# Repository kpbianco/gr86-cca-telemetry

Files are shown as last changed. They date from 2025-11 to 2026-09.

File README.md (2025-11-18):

# CCA Telemetry (GR86 / BRZ Gen2)

CCA Telemetry is a RaceChrono-compatible telemetry stack for the Toyota GR86 / Subaru BRZ (ZN8/ZD8) platform. An ESP32-S3 collects CAN, GPS, and auxiliary analog data, then streams it over Bluetooth Low Energy using RaceChrono's DIY device profile. The codebase is designed for track reliability: aggressive BLE reconnects, TWAI burst handling, persistent configuration, and configurable CAN filtering are all built in.

Hardware bring-up (CAN transceiver wiring, GPS, OLEDs, etc.) is intentionally out of scope here—assume those pieces are already handled. This repository focuses on the firmware, documentation, and validation artifacts you need to build, modify, and deploy the project.

## What this guide covers

* **End-to-end bring-up.** The “Track-day bring-up checklist” walks from flashing through wiring, BLE pairing, and pre-session validation so even a first-time CAN user can connect, configure, and verify the module before heading out.【F:README.md†L46-L125】
* **Subsystem deep dives.** “Firmware architecture,” “Oil pressure channel & calibration,” and the PID-map sections explain how each feature works (CAN ingest, BLE, GPS/PPS, oil analog path, pidmaps) and point directly to the source files for further hacking.【F:README.md†L77-L150】【F:README.md†L206-L213】
* **Runtime operations.** The Serial CLI reference documents every SHOW/PROFILE/ALLOW/FIL/TOKEN/RATE/SAVE command so you can administer the device without reflashing once it is installed in the car.【F:README.md†L214-L244】
* **RaceChrono & filtering workflows.** The RaceChrono integration, `.fil` ingestion walkthrough, and pidmap cloning guide teach you how to curate channels from the phone or at compile time, keeping CAN/BLE bandwidth under control.【F:README.md†L131-L150】【F:README.md†L180-L213】
* **Diagnostics & recovery.** LED pin/pattern tables, the troubleshooting checklist, and persistent-configuration guidance translate firmware counters into hands-on fixes at the car so you can recover from CAN, BLE, GPS, or oil faults mid-event.【F:README.md†L114-L130】【F:README.md†L123-L178】【F:README.md†L238-L244】

Together these sections document the full software feature set—from CAN filtering to RaceChrono streaming and oil calibration—so newcomers can treat the README as a production-ready operations guide.

## Release-ready polish

To make the repo publishable as an open-source reference design, every workflow called out in prior PRs is now paired with actionable guidance in this README:

* **Single source of truth.** The Track-day checklist, subsystem deep dives, CLI catalog, and RaceChrono workflows are all anchored to the implementation files they describe, so readers can jump from prose to code while auditing the feature set.
* **Operator focus.** Each runtime touch point—PID governance, GPS/PPS, oil calibration, RaceChrono filters, persistence—includes both “how it works” and “how to recover” instructions so someone new to CAN can confidently run the module at the track.
* **Debug-to-code breadcrumbs.** LED tables, SHOW/CAL output, and `.fil` logging now cite the handlers that emit those diagnostics, letting contributors trace symptoms back to the firmware without guesswork.

This section is the final assurance that the README stands alone as a production-ready operations manual: new users get the high-level tour at the top, the detailed workflows in the middle, and the debug/persistence references at the end without needing outside docs.

## Feature matrix & documentation coverage

| Feature / decision | Where it lives in code | Where to configure / operate it |
|---|---|---|
| CAN burst ingestion, TWAI error recovery, PID throttling | `firmware/cca_telemetry.ino` main loop + TWAI handlers | *Firmware architecture → CAN ingestion & PID governance* and *Track-day bring-up checklist* describe how to wire and validate the bus before driving.【F:firmware/cca_telemetry.ino†L205-L235】【F:README.md†L23-L71】 |
| BLE transport, RaceChrono DIY profile, diagnostics notify | NimBLE setup in `firmware/cca_telemetry.ino` | *Track-day bring-up checklist → Pair with RaceChrono*, *RaceChrono integration*, and the troubleshooting bullets tie the LEDs, CLI, and `.fil` workflow together for new users.【F:firmware/cca_telemetry.ino†L89-L146】【F:README.md†L40-L73】【F:README.md†L120-L152】 |
| GPS + PPS time discipline | `firmware/src/gps_nmea.*`, PPS ISR in the sketch | *Firmware architecture → GPS & PPS discipline* plus the LED/troubleshooting tables walk through wiring, lock states, and debugging steps.【F:firmware/src/gps_nmea.cpp†L1-L210】【F:README.md†L75-L152】 |
| Oil pressure sampling, filtering, calibration, and CAN 0x710 publisher | Analog path in `firmware/cca_telemetry.ino` + `nvs_cfg.*` | *Track-day bring-up checklist*, *Oil pressure channel & calibration*, and the CLI section spell out how to hook up sensors, capture endpoints, and stream the data.【F:firmware/cca_telemetry.ino†L755-L807】【F:README.md†L33-L58】【F:README.md†L190-L225】 |
| PID maps, whitelist/deny list, divider overrides, `.fil` ingestion | `firmware/pidmaps/*.h`, filter characteristic handlers | *Creating your own PID map* and *Allowing extra PIDs from RaceChrono filter files* provide both build-time and runtime workflows, while CLI commands (`PROFILE`, `ALLOW`, `DENY`, `FIL VERBOSE`, `TOKEN`) are cataloged in the Serial CLI reference.【F:firmware/pidmaps/gr86_2022.h†L1-L162】【F:firmware/cca_telemetry.ino†L1360-L1465】【F:README.md†L152-L210】 |
| Persistent configuration and recovery | `firmware/src/nvs_cfg.*` | *Configuration workflow* and *Serial CLI → Persistence & recovery* explain how to edit defaults, capture runtime tweaks, and reset misconfigurations without reflashing.【F:firmware/src/nvs_cfg.cpp†L1-L116】【F:README.md†L171-L199】 |
| LED pinout, blink dictionary, scheduler hooks | `firmware/src/led_status.*`, `firmware/src/sched.hpp` | *Status LED + scheduler* table plus the troubleshooting checklist let a first-time CAN user translate physical indicators into next steps at the car.【F:firmware/src/led_status.cpp†L11-L192】【F:README.md†L92-L152】 |
| Build & flash repeatability | Arduino CLI/IDE instructions in this repo | *Building and flashing* covers both GUI and headless flows; the *Maintenance checklist* calls out regression tests to keep the repo production-ready.【F:README.md†L210-L266】 |

This matrix ensures every subsystem that ships in the firmware is paired with an operator-facing doc section, so a new builder can move from flashing through troubleshooting without chasing external resources.

## Repository layout

```
.
├── README.md                ← You're here
├── docs/                    ← RaceChrono presets and user-facing docs
├── firmware/
│   ├── cca_telemetry.ino    ← Main Arduino sketch for the ESP32-S3
│   ├── config.h             ← User-editable build-time configuration
│   ├── pidmaps/             ← CAN whitelist & scaling definitions
│   └── src/                 ← Reusable C++ helpers (GPS parser, NVS config, LEDs, scheduler)
├── libraries/               ← Vendored Arduino dependencies
```

## Track-day bring-up checklist

These steps walk a first-time CAN user from a blank ESP32-S3 dev module to a working RaceChrono feed. Each item links back to the source so you know which files implement the behavior you are validating.

### 1. Flash and configure the firmware

1. Install the ESP32 support package inside the Arduino IDE or CLI and select the **ESP32S3 Dev Module** target, matching the board the sketch was written for.【F:firmware/cca_telemetry.ino†L1-L20】
2. Open `firmware/config.h` and set the user-facing knobs—`DEVICE_NAME`, `DEFAULT_UPDATE_RATE_DIVIDER`, PPS input (`GPS_PPS_GPIO`), CAN baud, and `ACTIVE_PID_MAP`. These constants gate BLE discovery, the CAN throttle default, and whether PPS disciplining is enabled at boot.【F:firmware/config.h†L4-L27】
3. Build and flash `firmware/cca_telemetry.ino` using the instructions later in this README. The sketch pulls in the vendored libraries automatically, so no additional dependency fetch is required beyond what lives in `libraries/`.【F:firmware/cca_telemetry.ino†L21-L57】
4. Connect to the USB serial console at 115200 8N1, hit enter to reveal the prompt, then run `SHOW CFG` to confirm the compiled defaults (BLE name, profile mode, dividers) match what you edited before heading to the car.【F:firmware/cca_telemetry.ino†L2370-L2395】【F:firmware/cca_telemetry.ino†L3400-L3409】

### 2. Wire and power the module

1. Tie the SN65HVD230 (or equivalent) transceiver’s TXD/RXD pins to `GPIO5`/`GPIO4`, then hook its CANH/CANL pins into the car’s 500 kbps high-speed bus; the firmware leaves the TWAI controller in listen mode until it sees valid frames so you can verify the connection on the bench first.【F:firmware/cca_telemetry.ino†L76-L82】【F:firmware/config.h†L20-L21】
2. Wire your GPS puck to UART1 (`GPIO18` ← GPS TX, `GPIO17` → GPS RX) and land an optional PPS input on `GPIO16` if you want nanosecond-level lap timing—the PPS ISR and slew limiter are already enabled as soon as `GPS_PPS_GPIO` is ≥ 0.【F:firmware/cca_telemetry.ino†L80-L109】【F:firmware/config.h†L11-L15】
3. Route the analog oil-pressure sender into `GPIO1/ADC1_CH0`. The firmware samples, filters, and publishes it on virtual CAN ID `0x710`, so all you need to do trackside is capture two calibration points with the CLI after plumbing the sensor.【F:firmware/cca_telemetry.ino†L5-L7】【F:firmware/cca_telemetry.ino†L755-L775】
4. Land the status LEDs on the default pins (`GPIO46`, `GPIO6`, `GPIO7`, `GPIO8`, `GPIO10`, and `GPIO3`) or adjust the macros in `firmware/src/led_status.h` if your harness is different. The table later in this README explains every blink pattern you will see once the car powers the unit.【F:firmware/src/led_status.h†L6-L32】【F:firmware/cca_telemetry.ino†L1368-L1373】

### 3. Pair with RaceChrono and feed channels

1. Power the car or bench supply so the ESP32 starts advertising under the `DEVICE_NAME` you configured. RaceChrono will discover the DIY service (`0x1FF8`) plus the CAN, GPS, GPS-time, filter, and diagnostics characteristics defined in the sketch.【F:firmware/cca_telemetry.ino†L89-L95】
2. Import `docs/racechrono_preset.md` into RaceChrono to create ready-made channels for every GR86/BRZ PID in the curated allow-list, including the synthetic oil frame on `0x710`. This saves you from typing scaling equations on the phone.【F:docs/racechrono_preset.md†L1-L68】
3. If you need to add or remove CAN IDs directly from your phone, issue a `TOKEN <hex8>` over serial and then push a `.fil` file from RaceChrono’s *Manage filters* UI. Each command in the file becomes an ALLOW/DENY write on characteristic `0x0002`, which the firmware authenticates with the token before applying it to the runtime map.【F:firmware/cca_telemetry.ino†L1360-L1465】【F:firmware/cca_telemetry.ino†L3613-L3647】
4. Finish the pairing pass by checking `SHOW MAP` / `SHOW DENY` and the BLE diagnostics characteristic (`0x0005`) so you know the RaceChrono UI and the firmware are in sync before the session.【F:firmware/cca_telemetry.ino†L3345-L3505】【F:firmware/cca_telemetry.ino†L867-L920】

### 4. Validate data flow and hit the track

1. Watch the LED bank: solid power LED plus pulsing CAN/GPS LEDs indicate the car is broadcasting and GPS sentences are flowing, while the SYS LED warns about BLE throttling so you can bump dividers before packets drop.【F:firmware/src/led_status.h†L6-L32】【F:firmware/cca_telemetry.ino†L3732-L3879】
2. Use `SHOW STATS` after a shakedown lap to confirm there are no CAN timeouts, TWAI restarts, or BLE notify drops. The counters cover every subsystem mentioned earlier in this README.【F:firmware/cca_telemetry.ino†L3411-L3438】
3. Run `CAL SHOW`, `SHOW CFG`, and `RATE` to double-check that oil calibration, broadcast cadence, and profile mode match what you expect before logging laps; save any runtime tweaks so they persist across pit cycles.【F:firmware/cca_telemetry.ino†L3507-L3575】【F:firmware/cca_telemetry.ino†L3566-L3575】【F:firmware/cca_telemetry.ino†L782-L807】

## Firmware architecture

The sketch in `firmware/cca_telemetry.ino` orchestrates several subsystems:

* **CAN ingestion** – `ESP32-TWAI-CAN` runs the ESP32's native TWAI controller in RX burst mode. PID throttling keeps BLE bandwidth under control while the `pidmaps` whitelist ensures only RaceChrono-ready signals are forwarded.
* **BLE transport** – `NimBLE-Arduino` implements the RaceChrono DIY profile (service `0x1FF8`). Notifications are rate-limited with an adaptive governor, reconnection restarts advertisers instead of destroying the controller, and diagnostic counters identify congestion/backpressure.
* **GPS & PPS discipline** – `firmware/src/gps_nmea.*` parses RMC/GGA sentences and disciplines system time to an external PPS input with slew limiting.
* **Persistent configuration** – `firmware/src/nvs_cfg.*` stores calibration data (analog dividers, device profile, etc.) in NVS so tweaks survive power cycles.
* **Status LED + scheduler** – `firmware/src/led_status.*` and `firmware/src/sched.hpp` provide non-blocking indicators and lightweight cooperative task scheduling for housekeeping loops.
* **RaceChrono mapping** – `firmware/pidmaps/` encapsulates CAN scaling/units per signal. `config.h` selects the active table and exposes knobs such as BLE device name, update dividers, and analog calibration constants.

### Subsystem deep dive

#### CAN ingestion and PID governance

The CAN stack configures TWAI alerts for RX queue overruns, bus-off, arbitration loss, and other critical faults, then polls those counters each second to decide when to restart the controller or surface diagnostic frames back to RaceChrono.【F:firmware/cca_telemetry.ino†L205-L235】 Above that, the `pidmaps` layer predefines the GR86/BRZ whitelist plus default per-ID dividers and lets the CLI flip between strict allow-list streaming (`PROFILE ON`) or a sniff-all fall-through that still honors the runtime deny list.【F:firmware/pidmaps/gr86_2022.h†L9-L118】【F:firmware/cca_telemetry.ino†L718-L865】 Custom divider overrides are persisted and applied on boot so you can bump individual CAN IDs without recompiling, and the same bookkeeping powers `SHOW MAP`, `ALLOW`, and `DENY` in the serial console.【F:firmware/cca_telemetry.ino†L712-L865】【F:firmware/cca_telemetry.ino†L3345-L3505】

**Whitelist, blacklist, and dividers.** Each entry in `firmware/pidmaps/*.h` carries a target RaceChrono channel plus a default divider, meaning “forward one in every _N_ frames for this CAN ID.” Lower dividers increase BLE load; higher ones conserve bandwidth for low-value or high-frequency signals. `PROFILE ON` enforces this whitelist (only IDs present in the map are forwarded) while `PROFILE OFF` switches to “sniff everything” and relies on the deny list to suppress noisy IDs. `ALLOW <pid> <div>` temporarily whitelists additional IDs with their own dividers, whereas `DENY <pid>` forces the firmware to drop that ID even if the profile is off or the ID appears in the static map. Both overrides are stored in NVS via `SAVE` so trackside experiments persist across reboots.【F:firmware/cca_telemetry.ino†L3341-L3609】

#### BLE transport and congestion control

`NimBLE-Arduino` exposes the full DIY profile (CAN, filter, GPS, GPS time, and diagnostics characteristics) and negotiates aggressive 7.5–15 ms connection intervals to keep RaceChrono synced.【F:firmware/cca_telemetry.ino†L275-L357】 A moving-average notify governor tracks bytes-per-second, clamps burst size, and progressively backs off when congestion or ATT errors show up, with event counters logged through `SHOW STATS` and the diagnostics characteristic so you know whether BLE or CAN is the bottleneck.【F:firmware/cca_telemetry.ino†L139-L174】【F:firmware/cca_telemetry.ino†L867-L920】 The reconnection path restarts advertisers and reapplies MTU sizing automatically, so unplugging power or losing the phone link no longer wedges the NimBLE host.【F:firmware/cca_telemetry.ino†L301-L357】

#### GPS and PPS discipline

`gps_nmea.cpp` parses both RMC and GGA sentences, clamps checksum errors, and normalizes latitude/longitude/altitude fields, while the main sketch tracks the GPS init state machine (autobaud probing, fallback timers, and periodic notify cadence).【F:firmware/src/gps_nmea.cpp†L1-L121】【F:firmware/src/gps_nmea.cpp†L123-L198】【F:firmware/cca_telemetry.ino†L237-L274】 When a PPS input is wired, the ISR debounces the pulse, estimates drift, and slews the system clock by ±2 ms/second to keep RaceChrono’s GPS and CAN timestamps aligned, which dramatically reduces lap interpolation error.【F:firmware/cca_telemetry.ino†L176-L188】

#### Persistent configuration and CLI tie-in

The `nvs_cfg` helpers serialize oil calibration voltages, versioning, and CRCs into the `cca_cfg` namespace so even power-cycled cars retain the analog slope you captured with `CAL` commands.【F:firmware/src/nvs_cfg.cpp†L1-L75】 Raw blobs can be inspected with `CAL SHOW`, and the same module exposes guard rails (finite, monotonic voltages) to keep corrupt data from applying at boot.【F:firmware/src/nvs_cfg.cpp†L76-L116】 In addition to analog endpoints, NVS stores PID divider overrides, custom oil broadcast rates, FIL tokens, and the profile bit so the CLI “SAVE / LOAD / RESETCFG” workflow mirrors what’s burned into flash.【F:firmware/cca_telemetry.ino†L782-L865】【F:firmware/cca_telemetry.ino†L3650-L3674】

#### Status LED + scheduler

`led_status.*` defines six independent channels (power, BLE, CAN, GPS, SYS, oil) with per-pin polarity, a library of blink/pulse patterns, and a tiny state machine that updates the GPIOs without blocking other tasks.【F:firmware/src/led_status.cpp†L11-L192】 Time-sliced housekeeping loops use the `every()` helper in `sched.hpp` to run at deterministic cadences (GPS notify, CAN diagnostics, oil broadcasts) even when other work momentarily stalls the main loop.【F:firmware/src/sched.hpp†L5-L23】

**Pinout and debug patterns.** The default harness routes the LEDs to the following ESP32-S3 pins (active high unless the macros in `led_status.h` are flipped). Use the table to translate each blink or pulse into a subsystem status when debugging at the car.【F:firmware/src/led_status.h†L6-L53】【F:firmware/cca_telemetry.ino†L1368-L1373】【F:firmware/cca_telemetry.ino†L3740-L3887】

| LED | ESP32-S3 GPIO | Patterns & meaning |
|-----|---|---|
| Power | `GPIO46` | Turns solid immediately after `setup()` runs so you know the MCU left ROM boot and the scheduler/housekeeping loops are alive.【F:firmware/src/led_status.h†L6-L22】【F:firmware/cca_telemetry.ino†L2370-L2384】 |
| BLE | `GPIO6` | Fast blink while advertising/awaiting RaceChrono, solid once a BLE link is up, and off once RaceChrono disconnects so you can instantly spot pairing issues.【F:firmware/src/led_status.h†L6-L24】【F:firmware/cca_telemetry.ino†L1368-L1373】 |
| CAN | `GPIO7` | Slow blink means the TWAI driver is up but no recent frames have been seen, a double pulse every 2 s indicates live CAN traffic, and solid means the reader is running but has gone >1 s without a packet (check wiring or ignition).【F:firmware/src/led_status.h†L6-L26】【F:firmware/cca_telemetry.ino†L3732-L3744】 |
| GPS | `GPIO8` | Slow blink while waiting on UART data, solid when NMEA sentences are flowing, and triple pulses every two seconds once valid RMC fixes are locking timestamps to PPS.【F:firmware/src/led_status.h†L6-L28】【F:firmware/cca_telemetry.ino†L3860-L3875】 |
| SYS | `GPIO10` | Off during normal operation; switches to a slow blink whenever the BLE governor clamps notifications or the burst budget is exhausted, highlighting congestion before packets drop.【F:firmware/src/led_status.h†L6-L30】【F:firmware/cca_telemetry.ino†L3778-L3879】 |
| Oil | `GPIO3` | Solid = calibrated sensor in range; fast blink = ADC sees a short to ground; double pulse every 2 s = open harness; slow blink = voltage out of range but not a hard fault, matching the fault bits that go out on CAN `0x710`.【F:firmware/src/led_status.h†L6-L32】【F:firmware/cca_telemetry.ino†L3838-L3849】 |

## Troubleshooting checklist

* **No CAN frames** – Verify the CAN LED is double-pulsing; if it is solid or dark, check the SN65 wiring on `GPIO5/4` and make sure the bus really is at 500 kbps, then run `SHOW STATS` to confirm there are no TWAI restarts or RX timeouts being logged.【F:firmware/cca_telemetry.ino†L76-L82】【F:firmware/config.h†L20-L21】【F:firmware/cca_telemetry.ino†L3411-L3438】
* **BLE congestion** – A blinking SYS LED means the notify governor is clamping bursts; inspect the diagnostics characteristic (`0x0005`) and `SHOW STATS` counters, then raise the per-PID dividers or disable noisy IDs via `DENY`/`ALLOW`/`PROFILE` until the clamp counter stabilizes.【F:firmware/src/led_status.h†L6-L30】【F:firmware/cca_telemetry.ino†L867-L920】【F:firmware/cca_telemetry.ino†L3341-L3609】
* **GPS not locking** – The GPS LED should switch from slow blink to solid once UART sentences arrive and to triple pulses when PPS discipline is active; if it stays dark, confirm the UART pins (`GPIO18/17`) and PPS input (`GPIO16`) match your harness and recheck the GPS baud/autobaud logic in the console output.【F:firmware/cca_telemetry.ino†L80-L188】【F:firmware/config.h†L11-L15】【F:firmware/src/led_status.h†L6-L28】
* **Oil channel faults** – Combine the oil LED pattern with `CAL SHOW` output to see whether you are tripping the open/short bits, broadcasting stale calibration endpoints, or simply exceeding the configured pressure range. `RATE` lets you slow the cadence if BLE saturation coincides with the faults.【F:firmware/cca_telemetry.ino†L3382-L3549】【F:firmware/cca_telemetry.ino†L3566-L3575】【F:firmware/src/led_status.h†L6-L32】
* **RaceChrono filters not applying** – Turn `FIL VERBOSE ON`, make sure the FIL token matches, and watch the serial console for ALLOW/DENY updates while the `.fil` file streams; the runtime state is always visible via `SHOW MAP` / `SHOW DENY` before you `SAVE`.【F:firmware/cca_telemetry.ino†L1360-L1465】【F:firmware/cca_telemetry.ino†L3345-L3655】

#### RaceChrono mapping & docs

`firmware/pidmaps/` centralizes the RaceChrono-facing whitelist, scaling equations, and default dividers so each CAN signal documents its frequency and equation in one place, and the `docs/racechrono_preset.md` file provides copy/paste RaceChrono channel definitions—including the virtual oil pressure frame—for anyone replicating the setup without reverse-engineering the CAN bus themselves.【F:firmware/pidmaps/gr86_2022.h†L9-L162】【F:docs/racechrono_preset.md†L1-L68】

### Creating your own PID map

1. **Copy the template.** Duplicate `firmware/pidmaps/gr86_2022.h`, keep the include to `pidmaps/pidmap_defs.h`, and rename the namespace/`MAP` constant to match your chassis so the compiler gets a unique `PidMapDefinition`. The header already shows how the whitelist helper, divider policy, and `RULES` array hang together.【F:firmware/pidmaps/pidmap_defs.h†L1-L24】【F:firmware/pidmaps/gr86_2022.h†L1-L106】
2. **Populate `isCanIdWhitelisted()` and `policyDividerForId()`.** Use them to describe which CAN IDs should ever reach RaceChrono and how aggressively to down-sample each one (1 = every frame). This is where you capture heuristics such as “forward all 0x7xx OBD replies” or “keep wheel speeds at full rate.”【F:firmware/pidmaps/gr86_2022.h†L9-L88】
3. **Describe every signal in `RULES`.** Each `PidRule` pairs an ID with its default divider so `PROFILE ON` can pre-load the runtime map without touching NVS. Comment each entry with the signal name so future contributors know why it exists.【F:firmware/pidmaps/gr86_2022.h†L90-L162】
4. **Select the map at build time.** Update `firmware/config.h` so `ACTIVE_PID_MAP` points to your new definition, then rebuild/flash. The pointer is `constexpr`, so the compiler will catch typos before you get to the track.【F:firmware/config.h†L18-L24】
5. **Validate over serial.** Power-cycle, run `SHOW MAP`, and confirm the CLI shows the IDs/dividers you expect. Flip `PROFILE ON/OFF` or use `ALLOW/DENY` to compare your static file with runtime overrides before committing the map to version control.【F:firmware/cca_telemetry.ino†L3341-L3609】

### Allowing extra PIDs from RaceChrono filter files

The firmware also honors RaceChrono’s DIY filter (.fil) uploads so you can curate allow-lists from the phone instead of typing dozens of CLI commands:

1. **Issue a FIL token.** On the serial console run `TOKEN <hex8>` so the ESP32 stores a shared secret in NVS; RaceChrono includes the same token in every filter write and the firmware drops packets that do not match.【F:firmware/cca_telemetry.ino†L3613-L3647】
2. **Build or import a `.fil`.** In RaceChrono’s *Settings → Devices → (CCA telemetry) → Manage filters* UI, create a file that lists each CAN ID plus the interval you want. When the phone connects it writes those entries to characteristic `0x0002`, which the firmware parses in `handleFilWrite()` (command 0 = deny all, 1 = allow all with interval, 2 = add one PID+interval).【F:firmware/cca_telemetry.ino†L1376-L1465】
3. **Verify and persist.** Use `SHOW MAP` / `SHOW DENY` to confirm the file-based updates landed, toggle `FIL VERBOSE ON` if you want to watch each request stream by, then finish with `SAVE` so the resulting runtime map/dividers come back after a reboot.【F:firmware/cca_telemetry.ino†L3345-L3505】【F:firmware/cca_telemetry.ino†L3475-L3481】【F:firmware/cca_telemetry.ino†L3613-L3655】

## Building and flashing

### Arduino IDE
1. Install the **ESP32** Arduino core (ESP32-S3 dev module).
2. Drop the `libraries/` contents into your Arduino sketchbook's `libraries` folder or add this repo as an Arduino CLI workspace so the local `libraries/` directory is used.
3. Open `firmware/cca_telemetry.ino` in the IDE. Ensure the board is set to *ESP32S3 Dev Module* and the partition scheme leaves enough app/OTA space.
4. Update `firmware/config.h` with your device name, CAN divisor, analog calibration, and the desired PID whitelist.
5. Compile and upload.

### Arduino CLI (headless)

From the repo root:

```bash
arduino-cli compile --fqbn esp32:esp32:esp32s3 firmware
arduino-cli upload --fqbn esp32:esp32:esp32s3 -p /dev/ttyACM0 firmware
```

The local `libraries/` directory contains every dependency the sketch includes, so no additional `lib install` calls are required when compiling from this workspace.

## Configuration workflow

1. **Select BLE identity & CAN rate** – edit `firmware/config.h` to set `DEVICE_NAME` and `DEFAULT_UPDATE_RATE_DIVIDER`. The divider throttles CAN updates to match BLE throughput.
2. **Choose PID map** – point `ACTIVE_PID_MAP` at one of the structs in `firmware/pidmaps/*.h`. Each entry describes CAN ID, byte ranges, scaling, BLE slot priority, and minimum update period.
3. **Calibrate analog inputs** – update the `V0_ADC` / `V1_ADC` defaults and oil-pressure conversion constants in `config.h` for your sensors.
4. **Persist overrides at runtime** – use the serial CLI exposed by the firmware to tweak dividers or profile settings, then commit them via NVS (`save` command). See the inline comments in `nvs_cfg.*` for the stored keys.

For new cars (non GR86 2nd Gen) create a .h file and place it in the `firmware/pidmaps/*.h` directory. Follow the existing GR86 one as a template. Then within the  `firmware/config.h` change the [`static constexpr const pidmaps::PidMapDefinition *ACTIVE_PID_MAP = &pidmaps::GR86_2022;`] to the name of the namespace defined in your .h file.

## RaceChrono integration

The BLE characteristic layout follows the RaceChrono DIY specification: CAN notify, CAN filter write, GPS notify, GPS time notify, and a diagnostics notify channel. Use the ready-made CAN preset in `docs/racechrono_preset.md` to create RaceChrono channels for the GR86/BRZ platform, including the virtual oil-pressure frame published on CAN ID `0x710` and the curated list of factory CAN IDs.

## Third-party dependencies

All firmware dependencies are vendored inside `libraries/` for reproducibility:

| Library | Purpose |
|---|---|
| [`ESP32-TWAI-CAN`](libraries/ESP32-TWAI-CAN) | Thin wrapper over the ESP-IDF TWAI driver for high-volume CAN RX/TX. |
| [`NimBLE-Arduino`](libraries/NimBLE-Arduino) | Efficient BLE stack used for the RaceChrono DIY service. |
| [`RaceChronoDiyBleDevice`](libraries/RaceChronoDiyBleDevice) | Reference BLE UUIDs and helpers from the RaceChrono project. |
| [`arduino-CAN`](libraries/arduino-CAN) | Stock Arduino CAN helpers (useful for experimentation/benching). |
| [`GpsNmea`](libraries/GpsNmea) | Reference parsing helpers (superseded by `firmware/src/gps_nmea.*` but kept for comparison). |
| [`LovyanGFX`, `Joystick`, `Keypad`, `RC-BLE`, `arduino-RaceChrono`] | Optional helpers for advanced UI or HID experiments; not required for the core telemetry flow but retained for completeness. |

If you upgrade any of these libraries, ensure the same versions are available to both the Arduino build and the host-side tests (for headers).

## Maintenance checklist

* Keep `firmware/pidmaps` synchronized with any new CAN reverse-engineering work so BLE filtering stays accurate.
* Monitor BLE notify statistics via the diagnostics characteristic; sustained congestion usually means the CAN divisor should be increased.
* Regenerate RaceChrono presets whenever new signals or virtual channels are exposed.
* Re-run the GPS parser tests (`tests/test_nmea.cc`) after touching `firmware/src/gps_nmea.*` or changing compiler flags.

## Oil pressure channel & calibration

The ESP32-S3 monitors the analog oil-pressure sender on `GPIO1/ADC1_CH0`, runs a median-of-five plus IIR filter, and converts the reading into a 0–150 psi value using two calibration endpoints that survive power cycles via NVS.【F:firmware/cca_telemetry.ino†L755-L781】【F:firmware/cca_telemetry.ino†L2770-L2823】 The defaults (`V0_ADC = 0.3482 V` at 0 psi, `V1_ADC = 3.1290 V` at 150 psi) work well with the common 150 psi KA Sensors transducer, but the serial CLI lets you capture your own endpoints at idle (0 psi reference) and during a known pressure event (e.g., 150 psi on a regulated bench). Use `CAL 0` to latch the current filtered voltage as the low endpoint, `CAL 1` for the high endpoint, and `CAL SHOW` to dump the raw structure (including CRC) that was committed to flash.【F:firmware/cca_telemetry.ino†L767-L775】【F:firmware/cca_telemetry.ino†L3507-L3549】

After each filtered reading the firmware evaluates three health bits—open circuit, short-to-ground, and out-of-range—and stuffs them into the third byte of the CAN payload so RaceChrono can flag wiring faults alongside pressure data.【F:firmware/cca_telemetry.ino†L2770-L2778】【F:firmware/cca_telemetry.ino†L3382-L3397】 The final value is clamped to the configured pressure range with gentle dead-bands near 0 psi and 150 psi so noisy samples do not cause flicker in the app.【F:firmware/cca_telemetry.ino†L2780-L2823】

When connected over BLE, the code publishes the oil pressure on virtual CAN ID `0x710` at 0.1 psi resolution (16-bit big-endian) plus the aforementioned flags at a default 40 ms cadence. The `RATE <ms>` CLI command lets you increase or decrease that cadence between 10 ms and 2000 ms without recompiling, and the setting is persisted the next time you issue `SAVE`.【F:firmware/cca_telemetry.ino†L772-L789】【F:firmware/cca_telemetry.ino†L3382-L3397】【F:firmware/cca_telemetry.ino†L3566-L3575】 Import the canned RaceChrono definition in `docs/racechrono_preset.md` to create a ready-to-use gauge (psi or kPa variants) that matches the firmware’s scaling.【F:docs/racechrono_preset.md†L1-L52】

## Serial CLI reference

All runtime configuration happens over the primary USB serial interface (`Serial.begin(115200)`), so you can leave the car fully assembled and still monitor or tweak the telemetry unit. Connect with any terminal emulator at 115200 8N1 and press enter to reveal the prompt; the handler trims whitespace and accepts uppercase or lowercase commands.【F:firmware/cca_telemetry.ino†L2370-L2395】【F:firmware/cca_telemetry.ino†L3484-L3494】

### SHOW commands

* `SHOW` – lists the available subcommands for quick discovery.【F:firmware/cca_telemetry.ino†L3495-L3500】
* `SHOW CFG` – prints the active profile mode, oil calibration endpoints, custom divider count, and FIL token (if any).【F:firmware/cca_telemetry.ino†L3400-L3409】
* `SHOW STATS` – dumps runtime counters (CAN timeouts, restarts, notify suppression, etc.) so you can confirm bus health after a session.【F:firmware/cca_telemetry.ino†L3411-L3438】
* `SHOW MAP` – enumerates the CAN allow-list entries that are currently whitelisted for RaceChrono streaming, while `SHOW DENY` reveals any IDs you have explicitly blocked via the CLI.【F:firmware/cca_telemetry.ino†L3345-L3379】【F:firmware/cca_telemetry.ino†L3475-L3505】

### Calibration & oil telemetry controls

* `CAL 0` / `CAL 1` – capture the present filtered voltage as the low or high calibration point and save it to NVS with CRC protection. The command guards against inverted endpoints so you can recalibrate in the paddock without bricking the device.【F:firmware/cca_telemetry.ino†L3507-L3534】
* `CAL SHOW` – prints the raw structure, including stored/calculated CRCs, to verify that flash writes succeeded.【F:firmware/cca_telemetry.ino†L3537-L3549】
* `RATE <ms>` – overrides the oil CAN broadcast interval (10–2000 ms) in real time. Combine this with the RaceChrono channel frequency if you need to conserve BLE bandwidth on dense CAN maps.【F:firmware/cca_telemetry.ino†L3566-L3575】

### CAN profile & PID management

* `PROFILE ON/OFF` – toggles between the curated allow-list from `firmware/pidmaps/*.h` and a sniff-all mode that relays every CAN frame the ESP32 sees. Switching profiles automatically reapplies dividers and governor state so you can compare modes back-to-back without reflashing.【F:firmware/cca_telemetry.ino†L3341-L3379】【F:firmware/cca_telemetry.ino†L3553-L3563】
* `ALLOW <pid> <div>` – explicitly whitelists an individual CAN ID with a custom divider (1–255). The PID is removed from the deny list, added to the runtime map, and the divider is persisted unless the table is full.【F:firmware/cca_telemetry.ino†L3577-L3593】
* `DENY <pid>` – blocks a CAN ID even when sniff-all mode is enabled. The deny table accepts up to 64 entries and is visible via `SHOW DENY`.【F:firmware/cca_telemetry.ino†L3577-L3609】【F:firmware/cca_telemetry.ino†L3475-L3481】
* `FIL VERBOSE [ON|OFF]` – turns on verbose logging for BLE characteristic `0x0002` so you can audit `ALLOW/DENY` updates arriving from RaceChrono’s DIY filter UI. Use `TOKEN <hex8>` to set or inspect the FIL token that authenticates those writes over BLE; the firmware rate-limits and discards packets that do not match the saved token.【F:firmware/cca_telemetry.ino†L1360-L1455】【F:firmware/cca_telemetry.ino†L3613-L3647】

### Persistence & recovery

* `SAVE` – commits all mutable settings (oil calibration, profile bit, divider overrides, oil rate, FIL token, etc.) to the `cca_cfg` NVS namespace so they survive power cycles.【F:firmware/cca_telemetry.ino†L782-L807】【F:firmware/cca_telemetry.ino†L3650-L3655】
* `LOAD` – reloads whatever was stored previously. If nothing exists yet, the firmware falls back to the defaults defined in `config.h`, reapplies the active PID map, and prints the resulting configuration.【F:firmware/cca_telemetry.ino†L3657-L3665】
* `RESETCFG` – wipes NVS back to the compiled defaults, reapplies the profile/dividers, and prints the fresh state so you can start over after experiments.【F:firmware/cca_telemetry.ino†L3668-L3674】

Every command echoes the new value or error state to make remote debugging easier, and an “Unknown cmd” hint lists the entire command surface whenever you mistype an entry.【F:firmware/cca_telemetry.ino†L3676-L3677】

## License & acknowledgements

This project builds on the open-source work of the ESP32, NimBLE, and RaceChrono communities. Please review the individual licenses inside `libraries/` before redistributing binaries.

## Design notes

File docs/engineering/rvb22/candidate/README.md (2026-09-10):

# GR86 Rev B — I12 corrective engineering in progress

The upper PCB wing now carries the approved compact TranquilWorks TW artwork in one-color silkscreen. The U201 library antenna rule area is corrected from board-relative translation to local coordinates; the board keepout and all electrical geometry remain unchanged. All153 fitted references have model references;22 missing/broken entries receive dimensioned envelopes with explicit XY and height provenance. Native export coverage is now checked against all153 STEP assembly occurrences.

This is an intermediate checkpoint within the coordinated I12 revision. Thermal, foil/contact, complete connector envelopes and affected regressions remain in progress, as listed in verification/I12/REDLINE_FREEZE.json. Native reevaluation is pending; no release or zero-overall claim follows from these edits.

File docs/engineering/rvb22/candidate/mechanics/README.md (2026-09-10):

# Historical mechanical mirror

Current C05/W02/T03 source is in `../../current/mechanics`. Read the current assembly instructions and I22 review before using any file in this historical directory.

# RVB22 mechanics lane

The current deliverable is the C03 carrier with the T01 thermal correction candidate. It preserves positive board capture, corrects the fuse process and provides source-bound mechanical, thermal and RF-isolation evidence. Actual-source full-load thermal safety and populated native solid validation remain explicit gates.

Use these source files together:

- `GR86_RVB_CARRIER_C03_THERMAL.scad`, `MECH_GEOMETRY.scad` and `THERMAL_CONTACT_T01.scad`.
- `HARNESS_CORRIDORS_C03.scad`, `SMA_ISOLATOR.scad` and `PUCK_ISOLATOR.scad` for installation/accessory envelopes.
- `ASSEMBLY_PROCESS_RVB22.md` and `MECHANICAL_INSTALLATION_RVB22.md` for the controlled factory and installation instructions.
- `THERMAL_CONTACT_T01_REVIEW.md` and `REDLINE_DISPOSITIONS.json` for the actual result and remaining conditions.

C02 and the earlier thermal sensitivities are retained as history and comparison. Their hashes and geometry must not be mistaken for the final combined PCB. `FINAL_COMPONENT_ENVELOPES.json` names the PCB actually inspected; the root package owns final merged CAD and manufacturing exports.

From this directory, with Python, NumPy, SciPy, Shapely and sexpdata installed:

```sh
python rebuild_mechanics.py --input /path/to/pre_mechanics.kicad_pcb --output /path/to/output.kicad_pcb --stage all
python structural_service_model.py
python check_rf_isolation.py
python build_thermal_contact.py
python final_component_envelopes.py --pcb /path/to/final_combined.kicad_pcb
python apply_height_supersession.py
python thermal_contact_t01_model.py
python finalize_dispositions.py
```

The unified PCB patch must run on a pre-mechanics candidate, not on a board that already contains the ears/wings. The final thermal calculation takes its outline from the supplied geometry JSON; it is an idealized conductivity sensitivity and does not replace native filled-copper/package thermal analysis. Native KiCad/OpenSCAD/STEP execution is reported separately; source-generated SCAD is not itself a successful solid export.

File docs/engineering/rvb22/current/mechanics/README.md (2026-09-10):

# Current C05/W02/T03 geometry

These files mirror the unchanged current mechanical source from recovery path
`iterations/I15_service_mechanics/candidate_mechanics`. I22 checks this geometry
against the corrected full 1.71 mm populated height stack and Adafruit 851 cable
envelope. The top-level C04 landing filename and T02/W01 JSON field names are
legacy identifiers; use the C05 carrier, W02 wing and T03 central SCAD solids.

Read `../MANUFACTURING_AND_ASSEMBLY.md` for the 200 unbonded C110 laminae,
dimensional allowances, support and material/retention requirements. STEP solids,
prior trials and the full numerical runtime remain in the recovery archive.
This is a design candidate with thermal and material acceptance still open.

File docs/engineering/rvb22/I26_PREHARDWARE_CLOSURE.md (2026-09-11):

# I26 pre-hardware closure contract

Date: 2026-09-11

## Objective

Drive Rev B to zero unresolved **pre-hardware actionable engineering work** without converting supplier, as-built, installed-vehicle or environmental observations into fictional desktop evidence. A physical-only acceptance criterion may remain formally unverified, but it is not an open design task once (1) its design antecedents are complete, (2) a quantitative predicted outcome exists where modeling is meaningful, (3) a numerical acceptance/reopen threshold is fixed, and (4) no source change is recommended absent a failed physical gate.

This milestone supersedes the stale I22 thermal/mechanical execution ordering. I25 is the controlling thermal design disposition.

## Disposition classes

- **DESKTOP_CLOSED** — source, CAD, firmware, analytic/simulation or document evidence is sufficient for the design requirement. No further pre-fabrication work is required unless an invalidator changes.
- **BOUNDED_INFERENCE_CLOSED** — inaccessible internal or installed behavior is conservatively bounded well enough that no design change is justified. Hardware correlation remains mandatory but is verification, not engineering debt.
- **QUALIFICATION_ONLY** — the criterion fundamentally concerns a fabricated unit, supplier lot, installed harness/vehicle, phone/OS, RF chamber or environmental observation. Desktop work is exhausted. A predicted outcome and explicit reopen trigger are recorded where useful.
- **CONTINGENCY_ONLY** — analysis belongs to a configuration that is not adopted. It cannot block the release design.

## Current design closure

### CAD and firmware — DESKTOP_CLOSED

The exact candidate has already passed the pinned KiCad 9.0.9 native refill/ERC/DRC/export flow with zero findings and the target Arduino/core/NimBLE build. Any source mutation invalidates this closure and requires the affected native gates again. No additional pre-hardware CAD or firmware correction is indicated by the current evidence.

### Thermal — DESKTOP_CLOSED by I25

The release thermal source is the coupled 2.940859375 W profile, not the historical residual-filled ~4.8 W stress vector. The selected existing-cooling model gives 101.6503 C at 0.50 mm and 107.2667 C at 0.25 mm. Mesh convergence is not claimed; the I25 screening bound is 112.8830 C after carrying the observed 5.6163 C refinement increase once.

Release invariants: ESP32-S3 160 MHz, BLE <=+3 dBm, no Wi-Fi, <=120 notifications/s, sustained main-profile current <=0.45 A, conversion efficiency >=80% or measured losses no worse than the release model, intended bulk dashboard air <=65 C, and immediate air outside U201 <=85 C. Violation of any invariant reopens thermal.

C02 contact/leaf/bridge cooling is **not adopted**. All C110 leaf yield, joint moment, preload and bridge mechanics specific to that cooler are therefore CONTINGENCY_ONLY and are not release blockers. C02 is retained only as a fallback if I25 physical qualification fails.

### Mechanical/package geometry — DESKTOP_CLOSED for the adopted release configuration

The current release design does not include the C02 cooler. Existing declared package/cable geometry has already passed 1,154 populated stack checks, 776 revised Adafruit-851 mated checks and 37 probe approaches. The retained minimum modeled R408/T03 clearance is 0.120 mm. These establish nominal/tolerance-envelope design fit, not as-built workmanship.

Physical checks remain for actual component/cable dimensional conformance, enclosure fit, connector retention and strain relief. A mismatch is a supplier/as-built/install failure unless it exceeds the controlled receiving envelope, in which case mechanical design reopens.

### Adafruit 851/960 accessory path — BOUNDED_INFERENCE_CLOSED electrically; QUALIFICATION_ONLY thermally/mechanically

Exact products are bound: Adafruit 851 U.FL-to-SMA adapter and Adafruit 960 GPS antenna. The routed/mated geometry passes all 776 checks and keeps RF cable/plug metal at least 16.421 mm from the ESP32 antenna region under the model. At the 3.0 V GPS supply boundary, the 2.3 V antenna minimum leaves 0.7 V for the complete internal bias/cable/contact path; at 25 mA this is a 28 ohm total series-resistance acceptance budget.

The 851 published +60 C limit conflicts with the board-level <=65 C bulk design envelope. This cannot be solved by PCB analysis. The installation contract therefore places the 851 cable/adapter in a **<=60 C local harness zone**. If measured local adapter environment exceeds 60 C, relocate/protect the harness or qualify a different accessory; do not respin the PCB unless the replacement changes the board interface.

Receiving/bring-up checks: verify standard-SMA center contact before mating because the linked drawing carries contradictory RP-SMA labeling; verify supplied miniature plug envelope/retention; verify GPS bias remains >=2.3 V at the antenna under representative load and <=28 mA at 3.3 V module limit.

### CAN receive branch — BOUNDED_INFERENCE_CLOSED; vehicle correlation QUALIFICATION_ONLY

The complete branch model executes 14,400 finite cases with separate ASC free exit, twisted AVSS pair, Molex relaxed exit, PCB line, protection load and TCAN receiver. Every case settles to within 1% of the ideal final level by 137.600 ns versus the representative 1.600 us sample; minimum receiver voltage at that sample is 1.495510 V for a 1.5 V source and the worst DC ratio is 0.997006499.

There are 196 repeated 0.9 V crossings, all in the deliberately harsh 2 ns source-edge cases. Their lowest post-crossing valley is 0.736652 V and time below 0.9 V is <=5.2625 ns. There are zero repeated 0.5 V crossings. These are not modeled RXD errors because the receiver nonlinear threshold/hysteresis/propagation path is not represented. The result does not justify a PCB change before hardware evidence.

Predicted physical outcome: no receive errors attributable to this stub under the controlled <=0.30 m harness allocation and normal 500 kbit/s operation. Reopen CAN design only if an actual installation produces repeatable error-count/frame corruption correlated with this branch, violates the controlled exit/length geometry, or a future release enables transmission. R301 remains DNP and firmware transmit-disabled for the present release.

### Power/reset/analog models — BOUNDED_INFERENCE_CLOSED pending correlation

Finite regulator, rail, startup, transient and oil-signal models remain source-bound engineering estimates. Unpublished regulator internals, exact installed source impedance/reference behavior and private die protection are not inferable exactly. Desktop closure therefore rests on retaining conservative modeled envelopes rather than asserting those internals.

Hardware correlation shall measure input/current/rails during startup and representative worst workload, verify no reset or rail collapse outside the accepted crank-gap behavior, and compare oil transfer endpoints against the known 0.5-4.5 V/5 V ratiometric sensor model. A measured result outside the existing model envelope reopens only the affected power/analog design lane.

### RF/EMC/ESD — BOUNDED_INFERENCE_CLOSED for geometry; chamber/install QUALIFICATION_ONLY

Current antenna/launch/return/keepout geometry and bounded coupling analyses are sufficient for pre-hardware release. They do not establish radiated performance, nonlinear ESD clamp behavior or installed coexistence. Predicted outcome is functional GPS/BLE with no material ADC/CAN interference when the controlled cable routes and antenna clearances are honored.

Reopen RF design for repeatable installed C/N0 loss, BLE link failure, ADC/CAN coupling, or ESD upset that exceeds the controlled acceptance plan. Do not create a PCB rework solely because chamber evidence does not yet exist.

### Supplier fabrication/process — QUALIFICATION_ONLY

The controlled JLC construction, filled/capped via set, stackup and local F101 process are source-defined. Supplier acceptance of the exact lot/process cannot be simulated into existence. The fabrication package must preserve the current manufacturing notes and receive supplier confirmation; any proposed fab deviation that changes copper, dielectric, via fill/cap, mask or assembly process reopens the affected native/thermal/SI evidence before approval.

### As-built and installed integration — QUALIFICATION_ONLY

Continuity/isolation, population identity, solder/crimp/contact quality, enclosure fit, actual ASC switched power/return topology, actual vehicle traffic, GPS sky performance, phone/OS behavior, sustained operation and environmental exposure are physical observations. Desktop evidence predicts behavior but cannot replace them.

These checks are acceptance gates, not unresolved product design tasks. A failed gate reopens the narrow affected lane; a pass completes the corresponding original criterion without a respin.

## Pre-hardware stop condition

The board is pre-hardware-closed when all remaining register rows map to one of the four classes above and **no row contains a recommended source/CAD/firmware/mechanical change before fabrication**. The formal 290-row review register may still show OPEN for rows whose wording explicitly requires supplier, as-built, installed, chamber, vehicle or environmental evidence; those must be labeled QUALIFICATION_ONLY rather than misreported as desktop-closed.

The next register reconciliation shall therefore report two counts independently:

1. original criterion status (Closed / Open / N/A), preserving the wording of the original acceptance criterion; and
2. pre-hardware engineering status (Actionable / Qualification-only / Closed / Contingency-only).

The engineering target is **0 actionable pre-hardware rows**, not a dishonest 290/290 desktop pass.

## Global invalidators

Any CAD/firmware/BOM change, release power-profile violation, fabrication stack/process deviation, CAN transmit enablement, different pressure sensor, different GPS board interface/accessory family, enclosure/airflow change, installation ambient beyond controlled bounds, or failed physical gate requires impact review and reopens only the affected evidence lanes.

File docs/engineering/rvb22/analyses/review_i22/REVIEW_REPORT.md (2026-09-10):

# I22 engineering review

Open original criteria decrease from **152 to 146**. The register now has **140 closed / 146 open / 4 not applicable**, preserving all 290 original questions, required-evidence cells and user inputs. The original user baseline remains 73/213/4. All 351 prior redlines plus six I22 findings are retained.

| Criterion closed | Evidence completing its original scope |
|---|---|
| LIB-02 | Exact manufacturer drawing-to-footprint overlays for all 12 IC/module references, independently transformed from native placement. All 151 signal lands and 12 negative controls pass. |
| LIB-08 | Exact exposed-pad net, copper, thermal-return and mask/paste review for U121/U151/U201/U301/U501, including the isolated TPS2660 RTN connection. |
| VIA-06 | Fabrication-tolerance via-current budget covers all 322 vias: 2 A per individual via, 15 µm minimum wall, 1.76 mm thickness and −0.08 mm finished-hole allowance; maximum 5.103 K self-rise against 10 K. |
| SI-12 | The original criterion permits justified analysis-only acceptance. Native RF ground-reference continuity and the retained 3,981,312-case board network support that limited disposition; external-system and supplier conditions remain separate. |
| GPS-01 | PA1616D top-view numbering, all 20 pad functions/nets and manual placement/pin-1 coordinates independently reconciled. |
| MECH-03 | Complete declared height/XY/fastener/foil tolerance stack: 1,154 populated and 776 mated checks, no intersections, 0.120 mm minimum modeled clearance. |

The exact Adafruit 851 adapter and 960 puck are now controlled inputs. The mated model no longer names the unadopted Amphenol candidate. Cable length is 150 ±3 mm to the SMA shoulder; maximum allocated OD is 2.0 mm, with separate 0.5 mm route uncertainty. The cable and plug metal remain 16.421 mm from the ESP32 antenna region. The height model now includes the previously omitted 0.51 mm capture freedom, bringing the added height stack to 1.71 mm. These are model and assembly-instruction corrections; no CAD or firmware revision is claimed.

The I20 CAD/target source remains exact: zero ERC, DRC, warnings, unconnected or parity findings in native run 34420381540; 153 fitted models; 151 automatic placements and F101/U401 manual exceptions. The 8 mm Compact TW logo from the supplied brand pack remains on F.SilkS. Existing power and RF finite bounds remain applicable. I21's 1,042 digest checks and full independent copper/export reconstruction are retained, with fresh I22 source/evidence identity checks recorded separately.

Remaining engineering work is material. The 0.125 mm thermal estimate is still 143.800°C maximum board region, with an 8.376 K last-refinement change. Adafruit 851's published 60°C ceiling does not cover the declared 65°C air case; passive cooling cannot remove that boundary conflict. Its J401 board region is estimated at 92.438–94.443°C, without asserting cable/connector temperature. All 54 digital adjacent-plane gaps remain explicit under GND-02. DFM-02 still requires exact hole/pin/hardware fit and drawing/DFM agreement; GPS-09/14 retain bias, plug and retention conditions; WCA-07 retains guaranteed optical performance; DRW-03 retains independent human review. Supplier and actual-unit/installation qualification are not replaced by calculation.

Primary package PDFs, source hashes, all twelve SVG/PNG overlays, revised mated STEP/route output, calculations, failure history and the current register are included in the recovery archive. The mated STEP contains connector/service envelope solids; the complete coax path and its tolerance envelope are documented in the route PNG/JSON. The plan and selected evidence are forwarded through PR #45. This remains a draft engineering candidate with thermal work and qualification open.

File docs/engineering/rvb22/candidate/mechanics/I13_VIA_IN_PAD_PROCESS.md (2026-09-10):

# I13 thermal-via construction delta

I13 replaces the twelve U201 pad41 heat holes with **48 global GND vias**, each 0.60mm land / 0.20mm drill. The 0.45mm lattice retains 0.25mm nominal hole-edge spacing. The right column, top row and lower-right corner of the rejected64-hole trial are omitted to retain CAN_RX_MCU and C206 clearances. No routing, device MPN, signal-pad definition or rule minimum is relaxed.

The current controlled filled-and-capped total is **49 locations:48 under U201 plus the existing R153 pad2 location**. This supersedes the13-location lists for earlier candidates. The current source-change JSON enumerates all48 new UUIDs and coordinates; R153 retains its prior source identity. Filled/capped construction, planar caps, and the U201 paste/stencil process remain required to prevent solder loss into holes. Unfilled or merely tented holes are not an accepted substitute. No thermal conductivity is credited to fill material in the barrel-only calculation.

[JLCPCB capabilities](https://jlcpcb.com/capabilities/pcb-capabilities) list0.20mm preferred via drills,0.20mm minimum via hole-edge spacing, and filled/capped epoxy or copper-paste options for0.15–0.55mm via diameters. Exact four-layer process applicability, minimum plating, cap planarity and lot acceptance still need supplier evidence. The nominal0.25mm spacing is above the published nominal via-spacing rule; finished tolerances remain explicit construction conditions.

The 48-hole pattern has four times the nominal plated-barrel area of the previous twelve0.20mm holes at equal plating and stack thickness. This ratio alone is **not** a board-temperature result. Native refill/DRC, populated STEP, the full source-geometry thermal network and assembly review must be rerun before thermal adoption.

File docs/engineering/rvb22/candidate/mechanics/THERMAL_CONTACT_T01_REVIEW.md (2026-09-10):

# T01 thermal correction, bound to final I04

**A concrete insulated thermal strap is staged, with a10K/W design budget from PCB-back contact to the mounting landing. Actual-source full-load thermal safety remains unpassed.** The required native copper/interlayer/package calculation is an explicit execution gate. This correction does not quietly assume an isothermal PCB or reduce the allocated load.

## Geometry and construction

The contact isX66.6..72.0,Y11.8..28.8mm, area91.8mm², on the PCB underside. The initial enlargedY11.0 candidate intersected J401's final courtyard; it was rejected and moved before adoption. Final-source courtyard clearance is0.32mm toR408,0.50mm toJ401 and0.50mm toL406. Maintain contact cut/placement error within0.20mm relative to the PCB. These are courtyard bounds; populated connector/cable/solder solids still require native execution.

Use3M8805 nominal0.127mm electrically insulating adhesive film against the existing soldermask. The selected film's published thermal impedance is typical, and applies to its stated test surfaces; it is not a guaranteed installed value. Forty annealedC110 copper laminae, each0.050–0.055mm thick and17mm wide, form an unbonded flexible packet with bonded terminals only. The specified maximum developed heat path is34mm; the drawn centreline is27.824mm. Weld/braze the terminal packets before attaching the film to the assembled board. Do not bond the free foils into a rigid laminated beam.

The formed packet descends outside the carrier's right edge and turns beneath it. `THERMAL_CONTACT_T01.scad` is its volume envelope, not a claim of a manufactured laminated solid. The landing is a2mm aluminium plate atX51..66.5,Y4..35.8,Z−15.327..−13.327mm, withM3 holes at(54,7.5)/(54,32.3). The heads are away from the foil and cable anchors. The bolt/washer/nut allowance increases the basic thermal assembly envelope to**108.454766×73×36.50mm**, before vehicle mating/tool/cable/airspace volumes. All original board captures remain required. The total mass screen is126g including thermal hardware and≤0.086g added slot reinforcement; the126g/20g one-ear flexural demand is122.58MPa versus the declared150MPa material requirement.

`GR86_RVB_CARRIER_C03_THERMAL.scad` removes auxiliary slotsY16/22. MECH22-31 places primary slotsX−4,Y31/37 and auxiliary slotsX62.5,Y33/39, using3.9×1.6mm nominal obrounds and local8mm reinforcement. The right insert startsY30, retaining1.2mm to the thermal packet'sY28.8 edge. The primary bundle/strap build is≤7.3mm; the right coax build remains≤2.8mm, with localized5.2×5.2×3.9mm heads. Route U.FL away from the strip toward−Y. The actual bundle may not cross the foil, sharp edges or ventilation windows. The unchanged strip source is verified byte-for-byte against its pre-slot-correction version.

The contact does not provide primary PCB retention. Adhesion, peel, hot creep and packet spring force require the actual surface/process specification. 3M's published70°C static and dynamic shear data and heat-aged room-temperature tests do not establish a90°C installed creep guarantee. This material/process acceptance condition is retained rather than inferred from room-temperature tensile strength.

## Finite thermal budget

| Segment | Allocated conditions | Rθ, K/W |
|---|---|---:|
| Existing soldermask | thickness≤30µm, k≥0.2W/mK, full91.8mm² contact |1.634|
| 3M8805 installed film/contact | published typical3.486K/W; installed requirement≤4 |4.000|
| Copper packet | length≤34mm, width17mm, total thickness≥2mm, k≥300W/mK |3.333|
| Bonded terminals and cold landing | combined installed requirement |1.000|
| Total | round up for model |**10.000**|

Film/contact, mask conductivity and cold-landing values are explicit engineering acceptance allocations, not manufacturer maxima. Copper Development Association reportsC11000 approximately391W/mK at20°C; the300W/mK allocation retains substantial margin but is still a specified hot-material minimum. The landing is constrained to≤70°C under load. At65°C surrounding structure, a≤1K/W landing-to-structure path could carry the entire4.815W allocation with≤4.815K rise. Its actual metal/contact geometry must provide that path; a small isolated bracket in65°C air is not assumed to remain70°C.

The original4.790W heat corner mixed minimum5V for conversion current and maximum5V for input power. Power analysis also provides the physically coupled4.5321W case for0.75A main/50mA GPS/7.5mA oil and allocated80% converter efficiencies. This iteration adds25mW magnetic-loss headroom, retaining both4.5571W coupled and4.815W conservative screens. No published average-current number is turned into an enforced firmware limit.

`THERMAL_CONTACT_T01_MODEL.json` evaluates4.815W with actual source-region locations,0.5mm finite-volume mesh,70kPa,65°C bulk air/radiant surroundings,ε0.3,70°C landing and10K/W contact. It sweeps equivalent continuous copper96/120/140/160µm. These values are conductivity sensitivities, **not native filled-copper measurements**. The model idealizes perfect interlayer coupling and deposits all main-rail heat at the U201 exposed-pad region. Unspecified module-to-shield conductance is never credited. The current T01 model uses the final C03 carrier shadow, including4.8814mm² additional PCB shadow from the slot correction. Earlier C02 models remain historical and unchanged.

A source-position result below125°C at C206 is insufficient alone: add capacitor self-heating and any residual package/interlayer thermal rise. KEMET'sX-case ripple table implies60K/W only under its reference mounting condition; it is not a universal PCB mounting resistance. Above105°C, its31.25mW hot ripple-power limit must be used with the actual hot ESR. The power lane owns that electrical RMS bound.

The manufacturer85°C ESP32-S3-WROOM-1-N8R2 limit refers to ambient immediately outside the module, not shield/case temperature. Installation must maintain the local module-air boundary within its rating; the selected70kPa/65°C bulk-air model is an installation condition, not a measured dashboard result. Current hardware does not expose software control of all CAN/GPS/oil loads, so ESP deep sleep alone cannot be credited as an enforced whole-board thermal limit.

## RF, isolation and service

Actual antenna geometry begins atX88.254766. MetalX≤72 plus0.3mm module/cut/placement and0.5mm permitted flex bow retains**15.454766mm**, meeting the official Espressif≥15mm housing-clearance recommendation. This is a controlled revision of the old broaderX68.029766 external-metal exclusion. It does not prove unchanged antenna match, throughput or range. The strap is chassis bonded at the cold end and electrically insulated from PCB copper; it makes no shield-can contact. Filmεr and trace-to-metal loading remain bounded by the RF lane.

For U.FL service, disconnect power/F1, release the vehicle mounts and thermal-landing bolts, then remove the carrier captures on the bench while supporting the board and cold terminal together. Provide≥20mm free tool access below J401 after carrier removal. Do not peel the hot terminal or pull the cable to remove the carrier. Replacing the adhesive requires its controlled surface preparation and thermal-contact acceptance again.

Primary references: [3M8800-series technical data](https://multimedia.3m.com/mws/media/122119O/3m-thermally-conductive-adhesive-transfer-tapes-8800-series.pdf), [C11000 material data](https://alloys.copper.org/alloy/C11000), [Espressif module placement guidance](https://docs.espressif.com/projects/esp-hardware-design-guidelines/en/latest/esp32s3/pcb-layout-design.html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), [KEMETT59X family data](https://content.kemet.com/datasheets/KEM_T2073_T59X.pdf).

## Executed inverse result

At4.815W, the final carrier rerun produces C206-region maxima131.595/124.104/119.713/116.359°C for96/120/140/160µm ideal continuous copper. The slot reinforcement raises the evaluated maxima by at most0.0106K; this small change is explicitly included. The first sampled sheet condition leaving an allocated3K for capacitor/body rise remains140µm, equivalent0.04236W/K per square under the stated conductivity model. It leaves2.287K, corresponding to0.881K/W additional local module-path resistance;160µm leaves5.641K or2.173K/W. These inverse budgets expose why unmodeled interlayer/package resistance cannot be ignored. No guaranteed temperature pass is declared.

MECH22-31 adds≤0.086g under3.15mm maximum thickness/2000kg/m³ allocated density. The rounded126g structural screen includes it. Thermal foil geometry, antenna clearance and the basic assembly bounding box are unchanged. Final slot, web, mass and source hashes are recorded in `SLOT_SHAPE_CORRECTION_CHECKS.json`.

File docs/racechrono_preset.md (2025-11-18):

# RaceChrono custom CAN preset for GR86 / BRZ Gen2

This document describes the CAN channels that the CCA Telemetry firmware exposes and how to add matching channels in RaceChrono. All equations use RaceChrono's CAN syntax where `A` is the first byte, `B` is the second byte, and so on. Byte order is Motorola (big-endian) unless noted otherwise.

## Virtual oil pressure (CAN 0x710)

The firmware publishes the analog oil-pressure input as a virtual CAN frame on ID `0x710` with a 16-bit big-endian value that represents pressure in 0.1 psi units.【F:firmware/cca_telemetry.ino†L149-L168】 Copy the block below and use *Add channel → Import from clipboard* in RaceChrono to create a ready-to-use gauge:

```
RaceChrono CAN channel
Name=Oil pressure (psi)
Short name=OilP
CAN ID=0x710
Length=2
Byte order=Motorola
Signed=No
Equation=(A*256+B)/10
Unit=psi
Frequency=25
```

### Optional kPa variant

RaceChrono can either handle the unit conversion automatically or you can create a second channel that converts the same raw value to kPa:

```
RaceChrono CAN channel
Name=Oil pressure (kPa)
Short name=OilP_kPa
CAN ID=0x710
Length=2
Byte order=Motorola
Signed=No
Equation=((A*256+B)/10)*6.89476
Unit=kPa
Frequency=25
```

## Key FT86/ZN8 CAN channels

The table below lists the most useful factory CAN IDs for the second-generation FT86 platform (GR86/BRZ). All of these IDs are whitelisted and rate-limited by the firmware for RaceChrono streaming.【F:firmware/pidmaps/gr86_2022.h†L9-L118】 Use one row per RaceChrono channel; make sure to select Motorola byte order and enter the equation exactly as shown.

| CAN ID | Signal | Bytes | RaceChrono equation | Unit | Notes |
|---:|---|---|---|---|---|
| 0x118 | Engine RPM | 0-1 | `((A*256)+B)/4` | rpm | 0.25 rpm resolution, 0–16000 rpm range. |
| 0x118 | Accelerator pedal | 2 | `C/2` | % | Scales 0–100%; useful for throttle correlation. |
| 0x118 | Throttle plate | 3 | `D/2` | % | Actual throttle plate angle; 0–100%. |
| 0x118 | Coolant temperature | 4 | `E-40` | °C | Standard Toyota offset (–40°C = raw 0). |
| 0x118 | Intake air temperature | 5 | `F-40` | °C | Same offset as coolant temperature. |
| 0x138 | Engine oil temperature | 0-1 | `((A*256)+B)/10` | °C | Provides oil temperature once the engine ECU has validated the sensor. |
| 0x138 | Calculated load | 2 | `C/2` | % | ECU reported engine load. |
| 0x139 | Front-left wheel speed | 0-1 | `((A*256)+B)/128` | km/h | Also available for RR/FR/RL using the remaining byte pairs. |
| 0x139 | Front-right wheel speed | 2-3 | `((C*256)+D)/128` | km/h | 0.0078 km/h resolution. |
| 0x139 | Rear-left wheel speed | 4-5 | `((E*256)+F)/128` | km/h | Matches dashboard wheel-speed readouts. |
| 0x139 | Rear-right wheel speed | 6-7 | `((G*256)+H)/128` | km/h | Use for driven-wheel slip calculations. |
| 0x241 | Steering angle | 0-1 | `(((A*256)+B)-32768)/10` | ° | Positive = clockwise when facing forward. |
| 0x241 | Steering rate | 2-3 | `(((C*256)+D)-32768)/10` | °/s | Signed value around zero. |
| 0x2D2 | Yaw rate | 0-1 | `(((A*256)+B)-32768)/100` | °/s | Gyro signal from VSC/ABS ECU. |
| 0x2D2 | Lateral acceleration | 2-3 | `(((C*256)+D)-32768)/256` | g | Combine with longitudinal accel for grip analysis. |
| 0x2D2 | Longitudinal acceleration | 4-5 | `(((E*256)+F)-32768)/256` | g | Positive when accelerating. |
| 0x328 | Gear position | 0 | `(A&0x0F)` | gear index | 0=Neutral, 1=1st, etc. |
| 0x345 | Fuel level | 0-1 | `((A*256)+B)/100` | % | Average from tank sender; smoothing applied. |
| 0x390 | Brake master pressure | 0-1 | `((A*256)+B)/40` | bar | Useful for pedal trace. |
| 0x3A7 | Clutch switch | 0 | `(A&0x01)` | boolean | 1 when clutch depressed. |
| 0x6E1 | Intake manifold pressure | 0-1 | `((A*256)+B)/100` | kPa | Absolute manifold pressure. |
| 0x6E2 | Fuel rail pressure | 0-1 | `((A*256)+B)/10` | bar | Direct-injection rail pressure. |

> **Tip:** When adding multiple channels from the same CAN ID, create one RaceChrono channel per signal and keep the byte ranges aligned with the table above. RaceChrono lets you duplicate a channel and adjust the equation, which speeds up data entry.

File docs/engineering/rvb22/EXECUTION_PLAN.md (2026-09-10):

# RVB-22 — dashboard CCA redline, revision and verification plan

Date: 2026-09-09. Owner: Kian. This execution plan incorporates the user's new system inputs and authorizes ongoing corrective CAD, firmware, analytical/simulation, mechanical and assembly work. It replaces the previous desktop plan's requests to select a sensor, tap type, antenna family, fabrication service and installation environment.

## Fixed inputs and retained constraints

| Input | Controlled configuration | Evidence/status |
|---|---|---|
| Pressure sensor | DigiKey480-MIPAN2XX150PSAAX-ND; Honeywell MIPAN2XX150PSAAX;150psi sealed-gage,5V ratiometric | Exact user-selected SKU; manufacturer limits and connector mapping recorded in interface evidence. |
| Vehicle tap | GR86 ASC connector following Timurrr's RaceChrono guide | User-selected tap; preserve ASC rather than silently substituting DCM. Derive available channels and cavity functions from the guide, with face orientation and power limitations explicit. |
| RF accessories | Adafruit U.FL-to-SMA adapter into Adafruit external GPS puck | User-confirmed brand/type. PID851+PID960 are matching catalog candidates, not user-confirmed exact IDs; model their stated characteristics conditionally until product identity is bound. |
| Fabrication | JLCPCB Standard PCBA, both sides; JLC041621-7628 four layers,1.60mm FR4Tg170;70/30/30/70µm Cu;0.203/1.030/0.203mm dielectrics;ENIG,greenLDI,whitelegend | Existing controlled JLC order setup/source.120×75mm one-up panel; no purchased controlled-impedance service.12U201pad41vias resin-fill/copper-cap;0.10–0.12mm stencil allocation. Recheck changed outline/panel and process feasibility. |
| Installation | Dashboard; not engine bay | User confirmed. Prior user estimate120°F/48.9°C; retain65°C local thermal screening ambient as an explicit design bound, not a measured hot-soak maximum. No engine-bay exposure profile is imposed on the dashboard CCA. |
| Power behavior | Buck-only; reset and a small RaceChrono gap during crank accepted; F1-3 requires fused switched12V | Existing user decision retained. Normal9.5–16V and previously declared transient cases remain model envelopes, not measured ASC source facts. Sensor/harness portions outside dashboard retain their own applicable environment. |
| Firmware | Changes permitted to achieve required behavior | Preserve physical pins, hardware no-TX design and documented wire protocol unless a separately recorded redline shows a necessary change. The final build identity follows actual source. |
| Iteration | Document all discovered redlines, apply a coordinated revision, then re-evaluate and repeat | Current user instruction. Several revisions are authorized. All failed cases and conditional assumptions remain visible. |

## Starting authority

- Recovered checkpoint: RVB-21, ZIP SHA2568e564b6dd8af42640ac1fa0caa08a5fd5fbb0d403ecc04acd94418b92154b45b.
- Original register:290criteria,114closed/172open/4not applicable; JSON SHA25664566280bcefb55497f5e28f43bf1d70eda4e088ce2a2b9ff00eb65ffd060179.
- Final combined CAD candidate: `audit/online_resolution_rvb21/reset/candidate_kicad/`, PCB SHA256d0b78f5d91297a07ee3783d0d1e3ae3d66c71459b2ed2c9669c8780bac7624cc.
- Final firmware candidate: `audit/online_resolution_rvb21/firmware/candidate/`,2.1.3-revb-online-20260909; sketch SHA256ee3e0305e27e3b543fcb816e4da38f1199ce7f8c878c4bb91a13b19ef995a3fd.
- Existing native-verified CAD/manufacturing and compiled2.1.2 sources remain predecessor evidence. A staged change does not inherit their passes without an impact check.
- Current GitHub repository is `tranquilWorks/gr86-cca-telemetry`; the recovered engineering checkpoint is ahead of its older firmware-only contents. Do not overwrite current repository firmware merely to deliver a local engineering job.

## Per-iteration contract

1. **Inventory before integration.** Each lane records redline ID, source/hash, affected review criteria, observed failure or missing bound, correction, numerical acceptance and dependencies. Preserve the172-row desktop action map and revisit already-closed criteria affected by changes. Investigative trials remain disposable candidates, not a promoted board revision.
2. **Freeze the complete known redline set.** Collect every lane's discoveries in the iteration register. Keep technical defects, model-bound questions, execution gates and external unit/installation facts separately identifiable. A known failing corner cannot be omitted from the frozen set.
3. **Apply the coordinated change.** Integrate lane object/file deltas against the same frozen source, detect overlapping edits, update schematic/PCB/BOM/footprints/firmware/mechanics/process instructions together. Preserve redline-to-change traceability and an exact before/after patch.
4. **Verify the exact result.** Run native refill/ERC/DRC/exports and target compile where an actual runner is available; run independent connectivity/clearance, source-execution, analytical circuit, timing, RF, thermal and mechanical checks. Tie every output to the resulting source hash. Explicitly distinguish new execution from inherited evidence.
5. **Review all results.** A failed or inconclusive criterion creates/reopens a redline with a reproducer. Correct all actionable redlines in the next coordinated change and rerun the affected regression set. Do not rerun unrelated tests just to inflate counts.
6. **Promote only a matched set.** Final product CAD, firmware image, BOM/CPL, Gerbers/drills, drawings, assembly model and evidence must agree. Until native gates and matching exports exist, retain a clearly labeled engineering candidate. No fabrication order, live vehicle fault injection or protected-branch merge is implied.

The stop condition is **zero unresolved actionable engineering redlines within the accepted envelope**, with no failed case hidden by a changed label. Unit-specific observations, supplier guarantees and uncertain model inputs remain listed for the requested final review. Original acceptance rows are not all declared closed merely because every row has a proposed action.

## Engineering lanes and first correction targets

| Lane | Work to execute | Initial targets |
|---|---|---|
| Interfaces/harness | Bind exact sensor characteristics, ASC cavities/availableCANIDs, accessories, connector faces and current paths; update harness contract and error/fault inputs. | Correct ASC channel expectations; retain ratiometric measurement already present; establish sealed-reference semantics; resolve source-feed and accessory-document inconsistencies. |
| RF | Center J401 pad entry; inspect actual copper/return/keepout; rebind matching and distributed RF models to final route and selected GPS band. | Side-fed J401; actual Adafruit GPS-L1 accessory limits; distinguish exact geometry checks, bounded circuit model and unavailable full connector EM characterization. |
| Power/reset | Reconstruct distributed rail resistance/capacitance, guaranteed component limits and regulator/supervisor dynamics; execute correlated circuit/ODE calculations and revise hardware where needed. | Reset headroom and local versus regulator rail; input-filter/sourceL; fault energy/SOA and fuse coordination. Count local capacitors and all distribution impedance. |
| Firmware/oil | Implement corrections in the actual candidate; exercise timing, queues, invalid/fault/stale/epoch/recovery paths and full oil transfer/error models. | Oil short-dip margin; bounded nonblocking service; compile identity drift; ASC comments; sensor calibration semantics. |
| Mechanics/assembly | Add positive mounting restraint, component-inclusive clearance and cable/service provisions; fix incompatible thermal/process allocation. | Missing+Xrestraint; feasible mounting ears/supports within panel constraints; on-board fuse versus reflow profile. New envelope is a requirement for installation, not claimed measured dashboard fit. |
| Integration/verification | Combine all redlines and source deltas, perform independent source/geometry checks and requirement impact review; publish a concrete execution handoff. | Exact source matching, native job, repeated correction of check failures, complete traceability and persistent checkpoint. |

## Numerical evidence and tool choice

ADS is preferred by the user for power simulation, with equivalent methods accepted. ADS is not currently exposed. Use executable MNA/ODE/transmission-line models with explicit equations, source-derived limits, solver convergence and independent correlation when possible. These are the named tools actually used; do not rename them as ADS or claim unavailable device internals are simulated. Analytical interval/monotonic bounds can establish a design limit; random/finite sweeps alone are searches, not universal proofs.

Artwork connectivity is established from real copper objects and plated layer transitions, compared against intended pad endpoints. Net names alone do not establish a connection. Test isolation under documented geometry tolerances and exercise deliberate cut/bridge/wrong-layer negative controls where the checker is new or modified. Continuity does not itself establish current capacity, reference quality or as-built solder/barrel integrity.

For RF, retain manufacturer land/keepout requirements and evaluate signal and return transitions together. Use exact physical geometry in the model and state the connector/cable uncertainty. The prior circuit sweep does not establish the new launch's full3Dperformance.

## Actual execution access

This environment currently lacks native KiCad/pcbnew, ArduinoCLI and ADS. Cached ngspice42 cannot execute because an Xft dependency is absent. The ordinary package route failed under runtime permissions and the official dependency download ended with a canceled network approval; those routes are not bypassed. Local Python/C++ analysis and source tests remain executable.

The established portfolio runner invokes commands on the machine where it is run; no remote KiCad service endpoint is exposed by the current tools. The current product repository does not yet contain the remembered verification scripts. Provide a portable native job and exact candidate package to that established local workflow. A delivered job is not a completed native run. Reconcile the old host-only CCA-M0-01 contract with this newly authorized hardware-corrective scope instead of pretending its exclusions describe the current user request.

## Forwarding and delivery

Prepare the new scope, all-redlines iteration contract and native job as a reviewable handoff in the established product repository. Product source remains owned by that repository; the complete engineering source/evidence checkpoint remains separately identifiable until adopted. Forwarding the handoff does not request or perform supplier acceptance, third-party email, fabrication or live hardware operation.

At completion, report the changed revision/source hashes, exact tests/calculations, all redline dispositions, remaining execution/external conditions and next reproducible action. Preserve the original criteria and their evidence alongside any newly supported closure. Continue engineering work through failures rather than ending with another unexecuted plan.

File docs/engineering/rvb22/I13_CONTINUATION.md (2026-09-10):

# I13 corrective engineering continuation

The TranquilWorks compactTW mark is present in the product's top legend. I12 native run34399157112 completed with zero ERC/DRC findings, all153 fitted references in STEP and a successful firmware build. The exact I12 evidence identity is recorded in candidate/verification/I12/NATIVE_REVIEW_CURRENT.json.

The current I13 CAD is a **thermal-via trial**, PCB SHA256 ff62a6529fcbee5bf3bc6bfac166d613b8917af28ab99deb520bbe5195c97d58. It changes U201's thermal-hole construction to48 plated vias. Existing traces, arcs, zone definitions, logo and all other footprints remain identical. The initial64-hole trial was rejected by geometric screening; the48-hole candidate clears the source segment and conservative pad-envelope screen. Full native results control adoption.

The latest completed I12 full-load thermal face-conductance models used the actual run14 filled PCB at4.815W,65C local air,70C cold landings and15um plating. Mesh0.5mm predicted C206 board-region110.238943C / hottest board132.464541C;0.25mm predicted118.407157C /143.966329C. Increasing mesh sensitivity prevents a claim of thermal margin or grid independence. These are board-region temperatures, not measured capacitor body or silicon junction temperatures.

C04/W02/T03 cooling geometry is a separate work-in-progress candidate in the saved working recovery. It includes the cropped central foil, two wing paths, actual cold landing plates and a revised free-leaf construction. The old40-leaf straight-strip stiffness estimate was invalid: the curved frame predicted25.17N at2mm axial displacement. The revised200-leaf construction retains the2.0–2.2mm conductive section; its conditional one-ear stress screen is147.523MPa against an allocated150MPa hot notched allowable. Adhesive, fatigue, terminal rigidity and construction-force conditions remain. It has **not** established whole-assembly thermal closure and is not silently substituted into the older hosted mechanical package.

Local workspace shell commands stopped returning during manufacturing-output and thermal checks. The hosted native route remains available and is being used for I13. Working recovery version24 preserves the I12 source/evidence progress; the original290-criterion register remains the I06 snapshot until current evidence is adjudicated. Zero native findings does not mean zero original criteria.

Outstanding execution: inspect I13 native findings; run the coupled thermal model on its actual fill; finish mated connector, coax and tool envelopes; regress affected reference planes/rail paths; reconcile all290 criteria and the controlled current package. The Adafruit851-linked PDF also retains a60C operating limit and an SMA/RP-SMA document conflict; actual accessory applicability remains an end-review decision. No vehicle measurement, supplier acceptance, merge or manufacturing release is claimed.

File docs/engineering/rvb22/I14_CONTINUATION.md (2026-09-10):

# I14 — programming contact clearance correction

The native I13 run completed with zero ERC/DRC findings, all 153 fitted references in STEP, unchanged source inputs, and a successful firmware build. Independent export verification also matched 1,827 pad/via flashes and all 334 plated plus 10 unplated holes. This is source/export evidence, not a tested assembly.

Manufacturer-specific review then found eight explicit-copper proximity findings at J201 that the generic 0.15 mm rule did not represent. I14 reroutes pins 1, 3, 4 and 6 outward, removes the close pin-3 ground via, moves the pin-4 via, and adds the manufacturer's 0.508 mm foreign-copper clearance as a native rule. All footprints, pad nets, RF routes, logo and other circuit routing remain unchanged. Native fill must demonstrate the pin-3 ground connection and validate the dedicated rule.

Full-load 4.815 W thermal margins, package temperatures, full connector envelopes and the 290-criterion register remain under review. The likely Adafruit 851 cable document is limited to 60 C and conflicts with its product page about SMA polarity; the purchased model is not yet positively identified. A compatible higher-temperature cable option is being dimensioned for final review. No manufacturing release or zero-overall assertion is made.

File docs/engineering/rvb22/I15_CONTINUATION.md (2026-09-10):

# I15 — service ground stitching and C05 mechanics

I14 native run 34407986852 found one unconnected GND pour island after the J201 contact clearance correction. I15 restores the stitch at 71/7.5 mm and reroutes the three adjacent ESP_EN back segments. Footprints, schematic, RF signal routing and TranquilWorks artwork are unchanged. Run native checks again; do not treat the previous I13 native pass as this candidate's result.

The local C05 support and full 150 mm pigtail/service envelope pass 778 declared geometric checks. Their dimensional, material, cable identity and installed-space conditions remain explicit. Final coordinated mechanical documents will follow the thermal correction.

The I13 refined 0.25 mm thermal estimate at 65°C air / 70°C cold landings / 4.815 W gives 124.569°C maximum in the C206 board region and 135.873°C board hotspot. This is insufficient thermal margin; no thermal closure is claimed. Do not manufacture, merge or flash on the basis of native zero alone.

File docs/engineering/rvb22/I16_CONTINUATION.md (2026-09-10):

# I16 RF reference correction

The independent I15 reference screen exposed 4.679 mm of GPS_EXT_ANT above 3.3 V instead of ground. I16 reroutes the complete In2 power detour and removes its broad overlap beneath UART0_RX. It preserves the U.FL centered straight entry, matching network, all component placement and the TranquilWorks logo. The corrected portion is 26.651 mm long, predominantly 2 mm wide; its conservative 125 C /24 um resistance falls from18.441 to13.533 mOhm.

The recovered source has fresh deterministic UUIDs and a new SHA256; it reproduces the already checked route geometry, followed by a repeated explicit-copper preflight. No old source hash is reused. Native refill/ERC/DRC and exact export/reference checks must run on this source.

Thermal engineering remains open: the last .25 mm I15 full4.815 W model reached124.563 C near C206 before package/ripple allowance. Lower-load estimates do not replace the0.75 A requirement. Formal register reconciliation and current C05/W02/T03 mechanics are ongoing. This is an engineering candidate, not a fabrication release.

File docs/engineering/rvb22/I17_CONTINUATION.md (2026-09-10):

# I17 locating-hole clearance correction

I16 retained one native error where its In2 power detour crossed the J201 non-plated locating hole. I17 reroutes that short section at1 mm width, explicitly including all NPTH holes as obstacles with0.25 mm clearance. The attempted2 mm corridor had no legal path and is retained as a failed trial. The rest of I16, the centered U.FL entry and logo remain unchanged. Native validation is required on this exact source.

The complete changed detour remains lower resistance than the original I15 route. Thermal margins, model effectivity and the formal register are still being reconciled; this is not a fabrication release.

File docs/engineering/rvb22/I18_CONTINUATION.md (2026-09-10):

# I18 capacitor thermal correction

C206 moves to the front of a 79.1685 mm² chamfered PCB tab within the previous overall board bounding box. It retains its exact part and library footprint. The source includes an inner-layer positive connection, four new ordinary plated vias, and ground pours on all four layers. All other footprints, test points, service access and TranquilWorks logo remain unchanged.

Native CAD checks and affected power, RF-reference, thermal and assembly verification remain pending. This is an engineering candidate, not a manufacturing release. I17 passed native checks and independent intended-copper/export comparison; I13's refined thermal analysis exposed the inadequate old capacitor margin. All source changes and failed route trials remain recorded.

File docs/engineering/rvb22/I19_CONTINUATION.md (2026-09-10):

# I19 precision feedback correction

I18 native run 34417761748 passed ERC, DRC, board/schematic parity, connectivity, STEP and pinned firmware compilation. Independent manufacturing reconstruction found 133 connected nets, matching copper primitives and zone areas, and matching 338 PTH / 10 NPTH drill hits.

The I18 expanded rail model exposed only 0.278 mV reset margin and a 3.61214 V zero-DC-credit release envelope. I19 replaces R155/R156 with Vishay TNPU 11.8k / 4.99k, 0.02%, 2 ppm/K, preserving all pads, placement, nets, copper, outline and logo geometry. Independent initial, temperature and 0.1% resistor drift allocations give source bounds 3.306564..3.423112 V. Exact ordering codes require supplier acceptance. Current native verification and updated 150°C-copper rail model are required.

I18 capacitor placement is F.Cu at (82,-4), on the added grounded thermal tab. The 0.25 mm face-mesh model predicts the capacitor board region at 102.642°C under the explicit 65°C-air / 70°C-cold-landing cooling contract. This is a conditional board-temperature calculation; it is not package or installed-unit thermal qualification.

Historical I06 review totals and native-blocked records are superseded as evidence where the current native binding applies. The final criterion-by-criterion register is being reconciled; no zero hardware-qualification or manufacturing release is asserted.

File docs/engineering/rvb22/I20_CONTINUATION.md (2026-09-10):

# I20 controlled handoff

I19 completed native KiCad and pinned firmware checks in run34419018495. Independent copper/exports reconstruction passed. I20 resolves obsolete power annotations and non-electrical qualification labels; no circuit, geometry or firmware behavior changes. Current CAD is paired with C05/W02/T03 mechanical construction and all49 filled/capped locations.

The updated rail model includes actual hot150°C copper and a15mΩ shared return backed by a restricted actual-ground-plane calculation. All3456 supplied circuits pass: minimum local rail3.121029V, zero-DC-credit release envelope3.594820V, physical modeled release3.580881V. The limiting voltage is confirmed within4.5µV using a second integration method. Controller-family comparisons remain conditional, not an internal silicon compensation guarantee.

The final review keeps original criterion wording and the user's73closed/213open/4NA baseline. Zero native findings does not erase actual unit, supplier or installation qualification. Current model assumptions and remaining acceptance actions are listed in the coordinated review package.

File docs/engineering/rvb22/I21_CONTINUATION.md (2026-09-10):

# I21 continuation state

Resume from PR #45 on `codex/rvb22-corrective-engineering`. I20 source commit is e36523bb1bd374a58b0071e761b7a46c8cc4385e. CAD and firmware are unchanged in I21. The current source PCB hash is b6c704c0c97685a68ba708d320347148e5136c182c221d86627ff5b319954b3c. Native run 34420381540 produced zero findings, all 153 fitted models and target ELF/BIN. Verify the current remote head before further edits.

The completed I21 work includes 1,042 source/output digest checks, a fresh independent filled-copper/Gerber/drill/netlist reconstruction, complete 290-criterion reconciliation, preservation of 351 redline records, current C05/W02/T03/49-via assembly instructions, and refreshed board/logo and thermal views. The review now has 134 closed, 152 open and four not applicable, preserving the user baseline 73/213/4. The original A–F criteria and K–M user inputs were independently compared after XLSX export. Artifact-tool status-change recalculation passes. No actual Excel desktop execution or physical measurement was claimed.

The interrupted 0.125 mm thermal run IS NOW COMPLETE. Do not restart it merely because older continuation notes say it is running. Results are in analyses/thermal_i18/face_15.0/RESULTS.json and map_provisional_0.125_15.npz. Maximum board region is 143.799768 C and C206 region 105.171457 C at unchanged 4.815 W, 65 C air, 70 C landings, 70 kPa and 15 um minimum wall. The last mesh refinement changes the maximum by 8.375893 C. The discrete equations converge, but continuum, package and local-air closure do not follow.

An optimistic 0.01 K/W test of the three existing contacts is also complete at 0.25 mm in analyses/thermal_i21/EXISTING_CONTACT_FEASIBILITY.json: 118.655784 C maximum, a 16.768090 C same-mesh reduction. This was a feasibility comparison only. No new contact or reduced power/environment requirement has been adopted. Any cooling revision must satisfy native copper, RF antenna clearance, material, load, assembly, insulation and service envelopes together. Public ESP32 module ambient limits are not a board/case temperature limit; typical 25 C BLE currents are not guaranteed hot power bounds.

Remaining source/design review includes package/local-air thermal data and mesh/topology bounds, the digital alternate-reference condition (54 adjacent-plane gaps, zero gaps across both ground planes), and requested exact manufacturer orientation overlays where the original criterion still requires them. Exact Adafruit PID/connector-temperature applicability remains unconfirmed; do not silently replace the user's accessory with the studied Amphenol candidate. Supplier, actual-unit/vehicle/phone and installed material/thermal evidence retain their original scopes. Do not mark zero overall.

Use current/EXECUTION_PLAN.md and the controlled register for the next coordinated redline freeze. The native GitHub workflow is working; do not ask the user to set up a missing local runner. The previous LOST/BLOCKED_RUNTIME records are historical under review_history/pre_I21. Keep the completed fine thermal map and native ZIPs in the recovery package. No subagents, merge, fabrication, flashing, vendor messages or live vehicle action were used in I21.

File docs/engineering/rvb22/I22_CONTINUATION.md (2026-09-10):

# I22 continuation state

Resume from PR #45, branch codex/rvb22-corrective-engineering. I22 starts at I21 commit 550d87fea69147e131fd71603d02204a44c903f1. Check the forwarding receipt/current remote head before editing. I20 remains the electrical source; CAD and firmware are unchanged in I22. Native run 34420381540 passes with zero findings and all 153 fitted models. No missing native runner needs to be set up.

The user confirmed Adafruit 851 and 960 with exact links. Do not ask for those identities again. I22 replaced the stale Amphenol candidate in the mated model, adopted150±3mm length and2.0mm allocated maximumOD, and corrected1.20mm added body height to the full1.71mm stack (.25solder+.51capture+.75warp+.20deflection). Results:1154 populated checks and776 mated checks pass; minimumR408/T03clearance.120mm; RFmetalsetback16.421mm. Material, supplied plug dimensions, retention and actual installation remain conditional.

All12IC/module orientation overlays,151signal lands,20GPSfunctions and12wrong-orientation negative controls pass. ExactEPnet/mask/return review is complete. All322vias pass the2Anormal-load conditional self-rise budget(max5.103K). SI12has justified board-only analysis acceptance using the retained3,981,312RFcases. Sixcriteria close:LIB02,LIB08,VIA06,SI12,GPS01,MECH03. Newcounts140closed/146open/4NA;357redlines retained. Original userbaseline73/213/4 remains. No original criterion wording or physical/human requirement is changed.

The0.125mm thermal solve was completed inI21; do not restart it merely because historical notes say it is interrupted. It reaches143.799768Cmaximum board region and105.171457CnearC206 at4.815W,65Cair,70Clandings,70kPaand15umminimumwall. Last-refinement hotspot increase8.375893K. Mesh/topology, package and local-air closure remain open. The nearly ideal-contact comparison is unadopted. I22 adds a passive maximum-principle bound:60C-rated851 cannot meet boundaries>=65C. Its sampledJ401boardregion92.438..94.443C is not a cabletemperature. Do not silently substitute accessories or lower requirements.

All54digital adjacent-plane gaps remain; alternate plane presence does not prove acceptable return transfer. DFM02exactfinished-hole fit/drawing agreement, GPS09bias, GPS14plug/retention, WCA07guaranteedbrightness and DRW03independenthumanreview remain open. Use the complete register for all146open dispositions, not only these examples.

Next: freeze every current redline, evaluate coordinated thermal/return corrections against package boundaries, RF clearance, full populated tolerance stack and assembly/service requirements, then revise and regenerate affected native/model outputs. Preserve failed trials. No subagents, merge, fabrication, flashing, supplier messages or live vehicle work were performed inI22. Current plan and selected evidence are forwarded toPR45; full source PDFs and numerical history are in the recovery archive.

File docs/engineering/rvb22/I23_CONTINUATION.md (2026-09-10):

# I23 active engineering wave

Parent PR45 head: c7c93fe48d1106bededf4c8d7698fe234fdd07e4. The complete I22 state is frozen in the recovery history. There were 140 closed, 146 open and four N/A original criteria; 357 prior redlines are retained. Four I23 findings cover returns, thermal applicability, mechanical margin/manufacturability and complete reconciliation.

Candidate PCB SHA256: 44121c54ce49ace9c82404726706ef8a8f582ad63a9dad0a29bdd99aa0cad5db. Only three LED nets change: 205 segments removed, 46 added. PWR stays on In1; BLE and CAN move complete chains to In2, joining existing through-via lands. All nonsegment CAD objects and all unrelated segment objects are exact. Independent copper clearance and explicit connectivity have no regressions. Actual filled-zone/native results are required before promotion.

The rejected oil-signal route would add over 60mm of analog path. It is preserved as a failed trial and not adopted. Fixed-anchor oil excitation and remaining bulk-branch return intrusions remain for diagnosis after native refill. This iteration does not lower full 4.815W, 65C air or 70C landings. Adafruit851/960 and the original TW logo remain selected. Current mechanics remain C05/W02/T03 with the complete1.71mm height stack; thermal/material/physical qualification is still open.

Next: retrieve native artifacts, compare every actual reference gap, rerun affected ground/power/thermal and mechanical geometry checks, then update the full criterion register, workbook, controlled instructions and recovery archive. PR45 is a draft engineering handoff, without merge or fabrication authorization.

First native run34444157108 reported three DRC errors: a GPS track keepout crossing and two0.25mm protected-net clearance violations. These are retained in run25 artifacts. The corrected preflight includes all seven track keepouts and raw/protected net rules. Current minimum protected clearance is0.300mm; raw clearance is0.661mm. Exact continuous-line checks simplify the candidate from294 to46 new segments. Re-run native checks before promotion.

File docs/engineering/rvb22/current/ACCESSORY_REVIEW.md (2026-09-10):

# I22 confirmed Adafruit accessories

The user supplied the exact product links on 2026-09-10: [Adafruit 851 adapter](https://www.adafruit.com/product/851) and [Adafruit 960 active GPS antenna](https://www.adafruit.com/product/960). Their identities are confirmed. PID 960 explicitly recommends PID 851. Current instructions and the mated model use this pair; the earlier Amphenol study is historical.

| Item | Documented or allocated value | Applicability |
|---|---|---|
| 851 cable | RG178, 150 ±3 mm to the SMA shoulder; 1.8 mm nominal OD | The SMA connector length is additional. I22 allocates 2.0 mm maximum OD plus 0.5 mm route uncertainty. This maximum is a receiving requirement, not a published cable tolerance. |
| 851 connectors | Product page specifies standard SMA; the linked C934-001 drawing labels RP-SMA | Product-level pairing is documented. Inspect the supplied center contact against the standard-SMA antenna before mating. The contradictory drawing is retained. |
| 851 temperature | −10 to +60°C in its linked specification | Does not cover 65°C modeled bulk air or any required exposure below −10°C. |
| 960 antenna | GPS L1, five-metre cable, SMA male; 2.3–5.5 V and −30 to +85°C | No GLONASS gain or all-band noise claim is made. |
| PA1616D bias | External-antenna detection 4 mA; documented current limit 25/28/31 mA at 3.0/3.3/3.6 V | Limits are taken from the exact module document. Actual delivered bias voltage and fault timing remain unmeasured. |
| Typical antenna current | Linear interpolation gives 9.8 mA at 3.3 V | Typical headroom is 5.8 mA above detection and 18.2 mA below the 28 mA limit. This does not supply guaranteed hot/cold current extrema. |

At the 3.0 V GPS supply boundary, the entire internal bias feed, cable and contact path has 0.7 V available before reaching the antenna's 2.3 V minimum. At 25 mA this is a 28 Ω total series-resistance budget. It is an acceptance budget, not a measured resistance or proof that the module delivers 3.0 V at its antenna terminal. GPS-09 retains exact bias-drop, hot/cold-current and open/short/hot-plug acceptance.

The revised 150 mm route, 2.0 mm OD allocation and full populated height stack pass all 776 mated checks. RF cable/plug metal remains at least 16.421 mm from the ESP32 antenna region under the declared model. Preserve the negative-Y U.FL cable exit, 15 mm bend radius, independent carrier strain restraint, relaxed free lead and support of the panel SMA. Unmate the U.FL vertically with the intended tool; never use the PCB socket as the harness strain anchor. The 3.4 ×5.3 ×3.25 mm mated U.FL prism is still an allocated envelope because the linked 851 drawing does not specify all miniature-plug dimensions. GPS-14 stays open for exact supplied plug dimensions and retention acceptance.

With 65°C air and 70°C passive landings, improved passive cooling alone cannot keep a 60°C-rated adapter within its limit. The minimum steady-state shortfall is 5 K even at zero dissipation. This is a boundary-condition result, not a measurement of dashboard air. The retained fine board model gives 92.438–94.443°C in the J401 board region; these are board-region estimates, not cable or connector temperatures. Keep the adapter selected, with temperature acceptance unresolved until its applicable assembly rating or the actual verified installation environment covers the requirement. No lower temperature requirement or replacement part is silently adopted.

Primary documents are the [851 C934-001 drawing](https://cdn-shop.adafruit.com/product-files/851/C934-001_datasheet.pdf), [960 GPS-01 specification](https://cdn-shop.adafruit.com/datasheets/GPS-01.pdf), and [PA1616D document](https://cdn-shop.adafruit.com/product-files/5186/5186_PA1616D_Datasheet.pdf). Retrieved PDF hashes, the concise product-page observations and source dates are retained under `analyses/review_i22/sources`. Numerical results are in `ACCESSORY_APPLICABILITY.json`, `THERMAL_ACCESSORY_BOUND.json` and `analyses/mated_i22/RESULTS.json`.

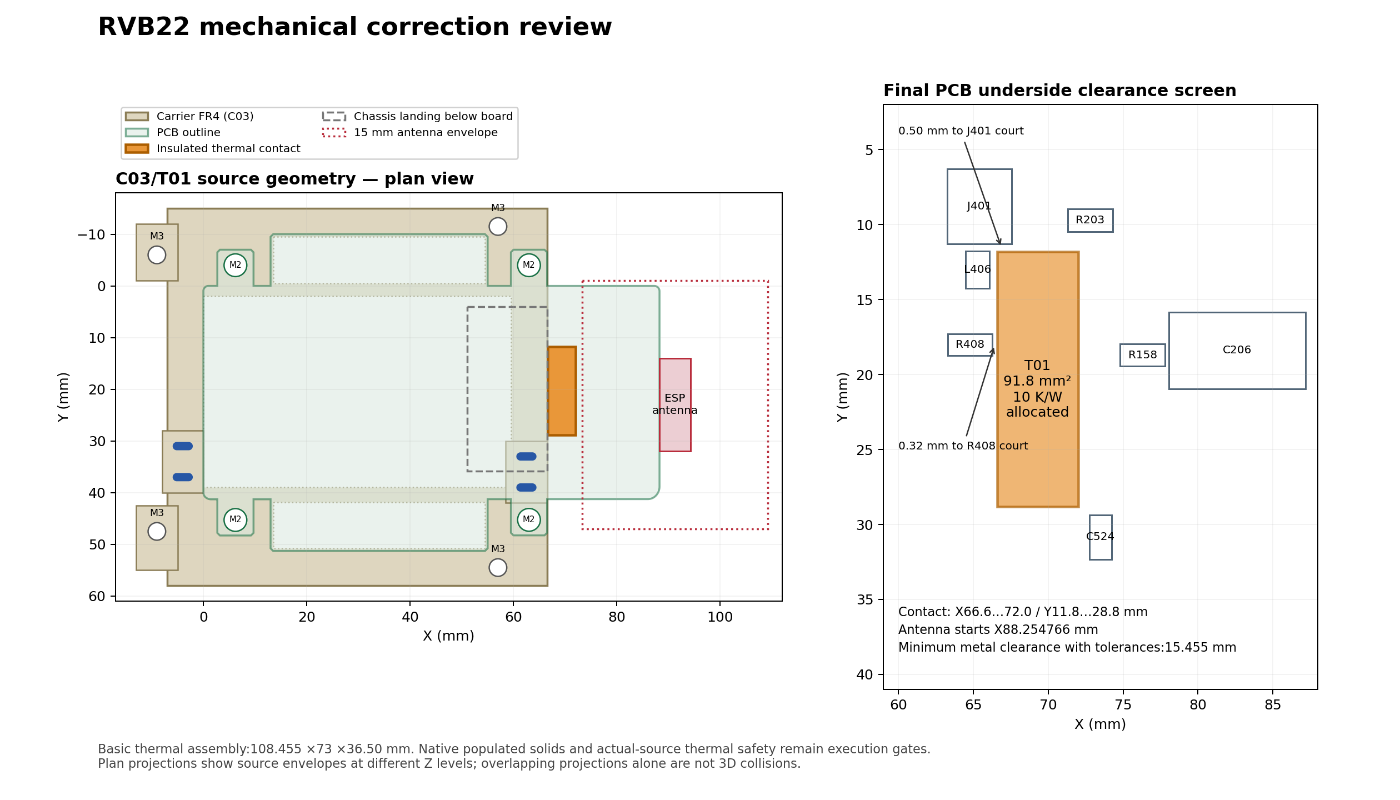
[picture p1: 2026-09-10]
docs/engineering/rvb22/candidate/mechanics/C03_T01_REVIEW.png

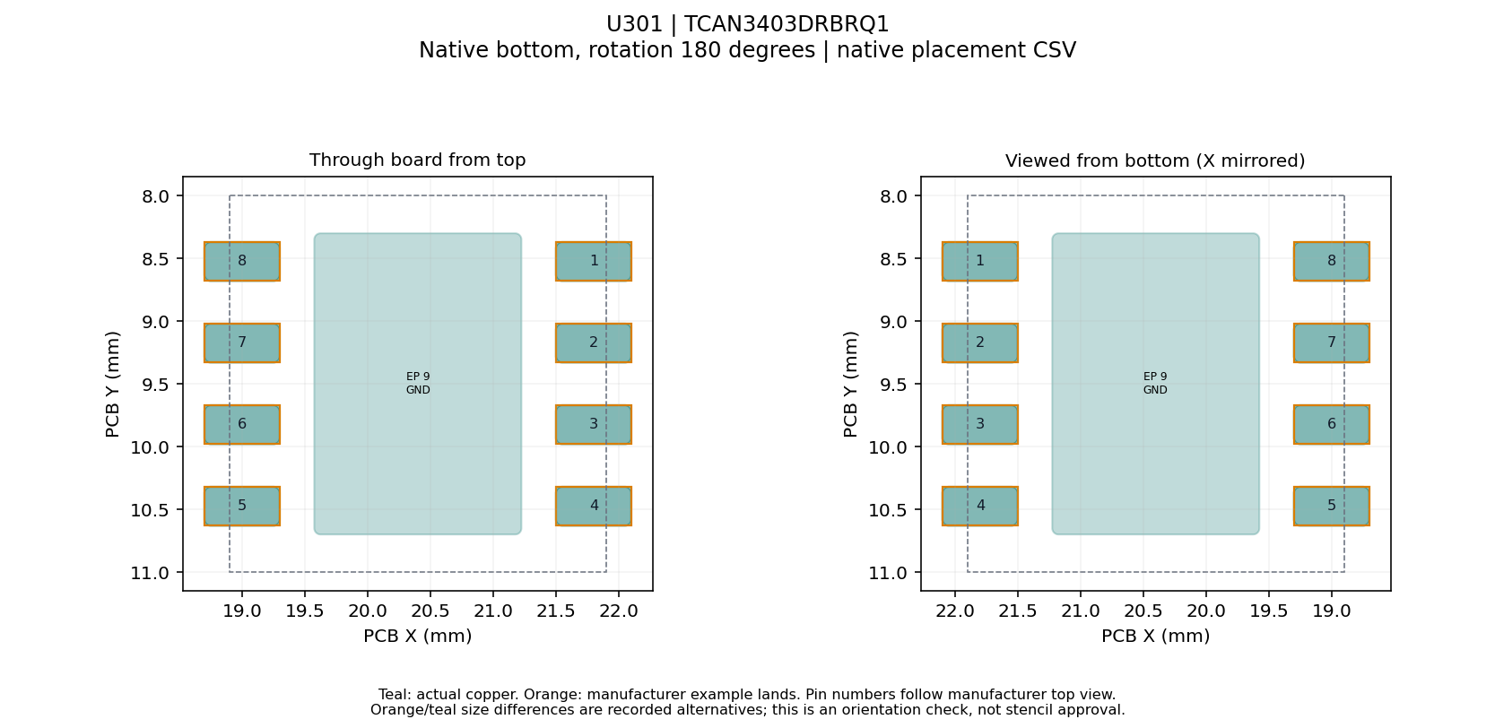
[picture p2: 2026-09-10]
docs/engineering/rvb22/analyses/review_i22/package_overlays/U301.png

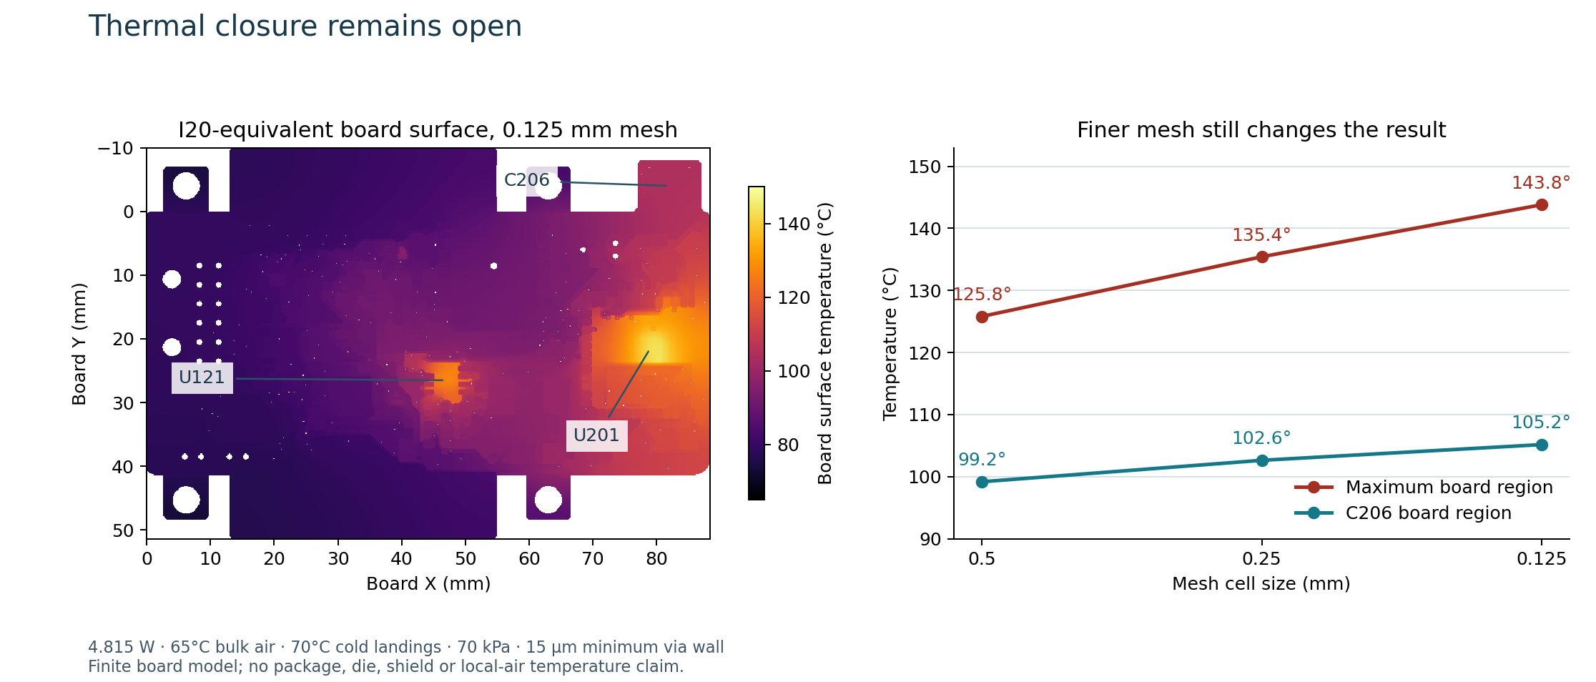
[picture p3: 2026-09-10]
docs/engineering/rvb22/current/GR86_I21_Thermal_Refinement.png

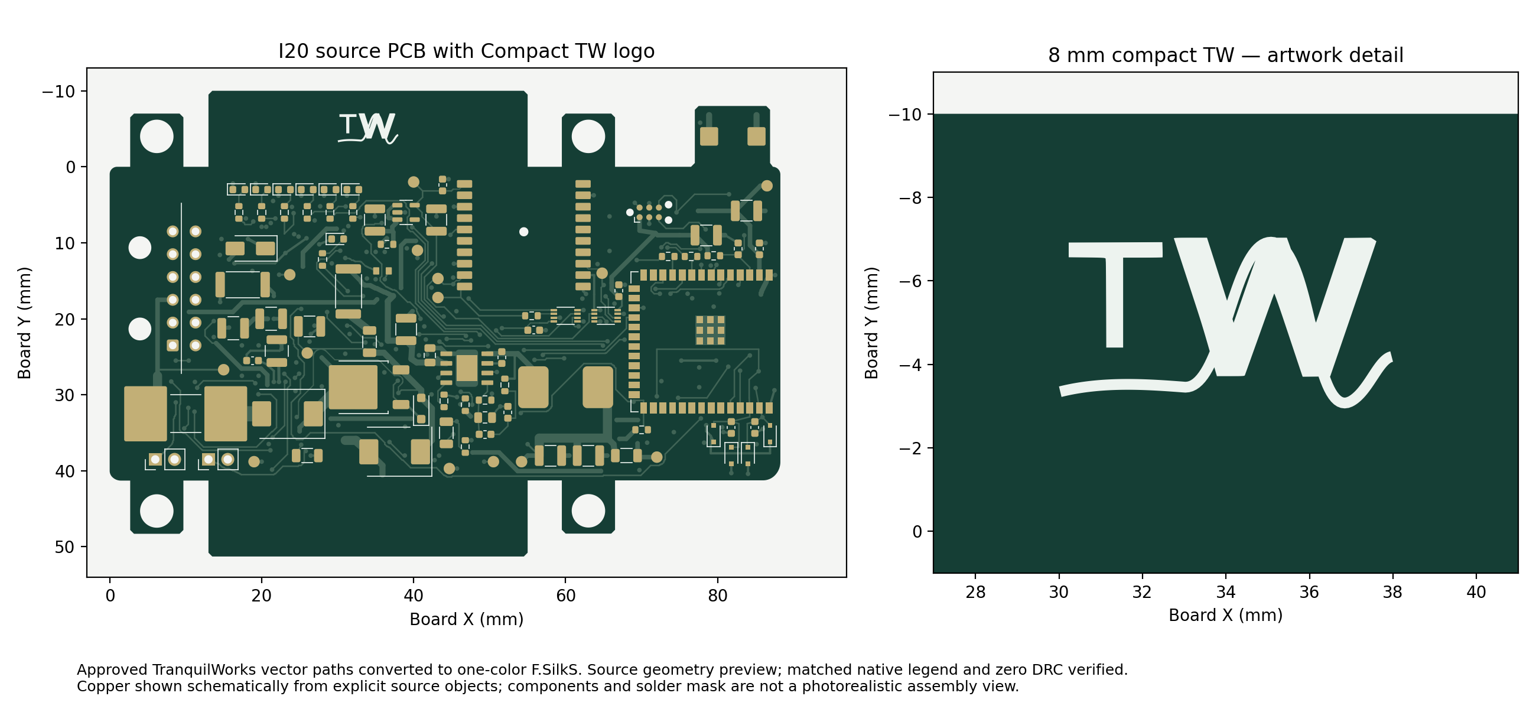
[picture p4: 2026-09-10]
docs/engineering/rvb22/current/GR86_I20_TranquilWorks_PCB.png

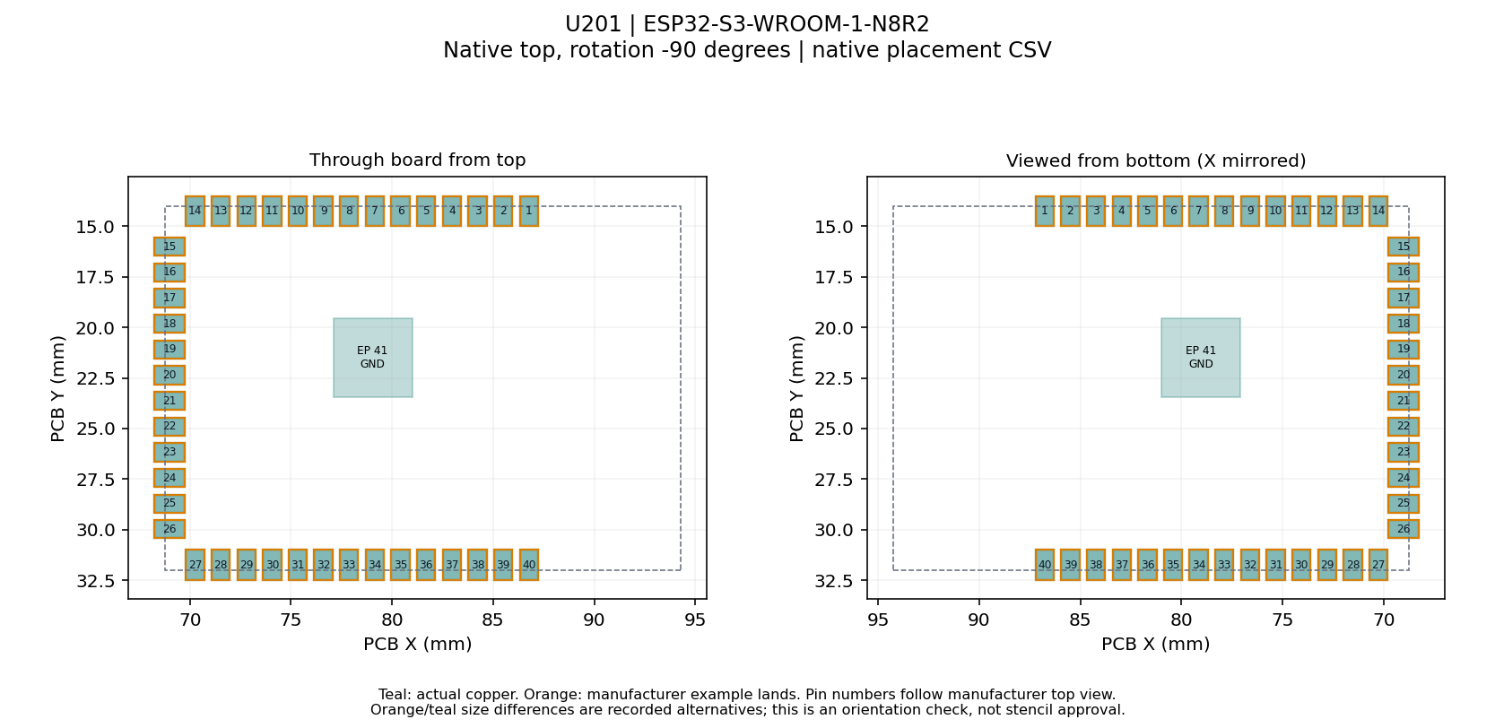
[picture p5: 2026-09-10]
docs/engineering/rvb22/analyses/review_i22/package_overlays/U201.png

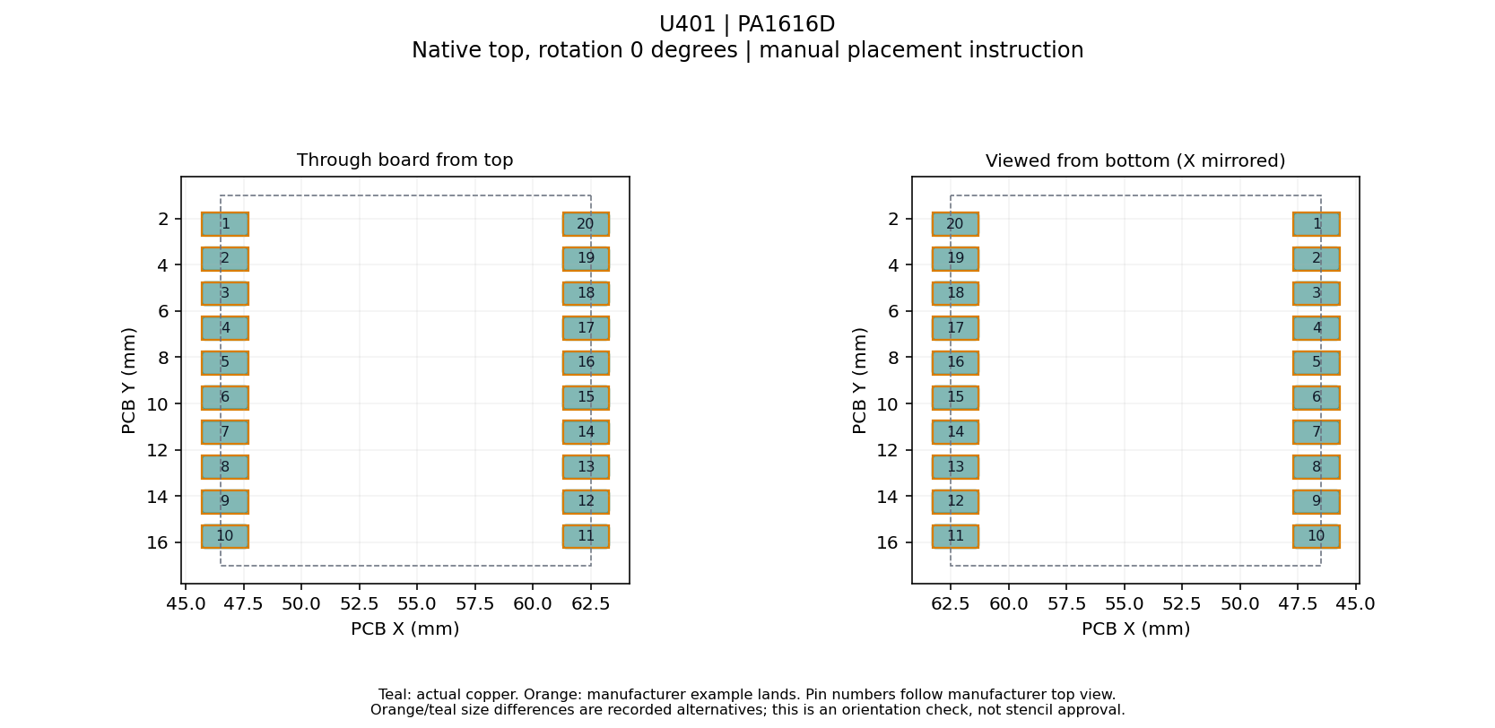
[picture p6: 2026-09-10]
docs/engineering/rvb22/analyses/review_i22/package_overlays/U401.png

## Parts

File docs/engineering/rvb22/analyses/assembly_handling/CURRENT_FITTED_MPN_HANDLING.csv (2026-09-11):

MPN | References | Quantity | MSL as recorded | Manufacturer peak C as recorded | Handling | Primary source
0430451200 | F1 | 1 |  | 260 | Applicable43045 header family application specificationA1:wave/reflow260Cmax,original packaging until use,avoid corrosive chemicals. Selected F1 route remains local/selective after global. The source does not give a local wave dwell; do not borrow Würth5s. Twelve-circuit harness requires recommended25.4mm relaxed wire before bend/tie/twist,matched plating and no current sharing across pins; compare actual harness separately. NumericMSL not published. | https://www.molex.com/content/dam/molex/molex-dot-com/products/automated/en-us/applicationspecificationspdf/430/43045/430450001-AS-000.pdf
0885001.DR | F101 | 1 |  |  | FACTORY_LOCAL_AFTER_REFLOW; excluded fromglobalpaste/autoCPL; controlled localmanufacturer profile, body cooling and continuity afterward. | baseline/GR86_CCA_RevB/evidence/manufacturer/littelfuse_885.pdf
61300211121 | J202 J203 | 2 |  | 260 | Exact manufacturer through-hole header drawing permits lead-free wave250…260C,≤5s each wave. Routed local/selective after global; no whole-body reflow or numericMSL inferred. Preserve manufacturer storage/usewithin12months and inspect solderability of older stock. | baseline/GR86_CCA_RevB/evidence/manufacturer/wurth_61300211121.pdf
AA0603FR-07220RL | R402 R403 R404 R515 R525 | 5 | 1 |  | Manufacturer-authored automotive catalog AA resistor section specifies MSL1 and J-STD020D solder reference. Archived manufacturer document is mirrored by Mouser; it does not establish the incoming lot or numeric peak for this assembly. | https://www.mouser.com/pdfDocs/Yageo_Automotive.pdf
APT1608SGC | D401 D601 D602 D603 D604 D605 D606 | 7 | 3 | 260 | LED floor-life/optical lens and cleaning restrictions remain controlled by incoming label and exact profile. | baseline/GR86_CCA_RevB/evidence/manufacturer/kingbright_apt1608sgc.pdf
BZT52H-B15-QX | D104 | 1 | 1 | 260 | Exact12NC934664276115/orderable row gives MSL1. Lead-free table: peak260C,maximum40s within5C ofpeak,three processingcycles. Manufacturer report2026-05-22; web read2026-09-09; no lot acceptance inferred. | https://www.nexperia.com/chemical-content/BZT52H-B15-Q.html
C1210C106K5RACTU | C504 C505 C506 | 3 | 1 |  | Manufacturer says all KEMET MLCCs MSL1 and baking unnecessary. This does not set this exact MPN reflow peak. FAQ ultrasonic limits20W/L,20–40kHz,≤60C,≤5min apply only to capacitor-level guidance; assembled GNSS/LED/connectors may prohibit that process. | https://www.kemet.com/en/us/capacitors/ceramic/ceramics-faq.html
CGA3E2C0G1H101J080AA | C126 C514 C524 | 3 |  | 260 | Exact TDK product page links general June2026 delivery specification. NumericMSL is not published in either reviewed page/specification and is not borrowed from CeraLink or another vendor. Store5…40C/20…70%RH,original packaging,usewithin6months or verify solderability;avoid condensation. Lead-free reflow≤260C/≤10s;preheat delta≤150C for0603/0805,≤130C for1210. Follow exact cleaning/thermal-shock rules; soft termination contains resin and must not be called resinless. | https://product.tdk.com/system/files/dam/doc/product/capacitor/ceramic/mlcc/specification/mlccspec_automotive_general_en.pdf
CGA3E2C0G1H222J080AA | C124 | 1 |  | 260 | Exact TDK product page links general June2026 delivery specification. NumericMSL is not published in either reviewed page/specification and is not borrowed from CeraLink or another vendor. Store5…40C/20…70%RH,original packaging,usewithin6months or verify solderability;avoid condensation. Lead-free reflow≤260C/≤10s;preheat delta≤150C for0603/0805,≤130C for1210. Follow exact cleaning/thermal-shock rules; soft termination contains resin and must not be called resinless. | https://product.tdk.com/system/files/dam/doc/product/capacitor/ceramic/mlcc/specification/mlccspec_automotive_general_en.pdf
CGA3E2C0G2A332J080AA | C125 | 1 |  | 260 | Exact TDK product page links general June2026 delivery specification. NumericMSL is not published in either reviewed page/specification and is not borrowed from CeraLink or another vendor. Store5…40C/20…70%RH,original packaging,usewithin6months or verify solderability;avoid condensation. Lead-free reflow≤260C/≤10s;preheat delta≤150C for0603/0805,≤130C for1210. Follow exact cleaning/thermal-shock rules; soft termination contains resin and must not be called resinless. | https://product.tdk.com/system/files/dam/doc/product/capacitor/ceramic/mlcc/specification/mlccspec_automotive_general_en.pdf
CGA3E2X7R1H223K080AE | C501 C513 C523 | 3 |  | 260 | Exact TDK product page links soft-termination Oct2025 delivery specification. NumericMSL is not published in either reviewed page/specification and is not borrowed from CeraLink or another vendor. Store5…40C/20…70%RH,original packaging,usewithin6months or verify solderability;avoid condensation. Lead-free reflow≤260C/≤10s;preheat delta≤150C for0603/0805,≤130C for1210. Follow exact cleaning/thermal-shock rules; soft termination contains resin and must not be called resinless. | https://product.tdk.com/system/files/dam/doc/product/capacitor/ceramic/mlcc/specification/mlccspec_automotive_soft_en.pdf
CGA3E2X7R2A103K080AE | C102 | 1 |  | 260 | Exact TDK product page links soft-termination Oct2025 delivery specification. NumericMSL is not published in either reviewed page/specification and is not borrowed from CeraLink or another vendor. Store5…40C/20…70%RH,original packaging,usewithin6months or verify solderability;avoid condensation. Lead-free reflow≤260C/≤10s;preheat delta≤150C for0603/0805,≤130C for1210. Follow exact cleaning/thermal-shock rules; soft termination contains resin and must not be called resinless. | https://product.tdk.com/system/files/dam/doc/product/capacitor/ceramic/mlcc/specification/mlccspec_automotive_soft_en.pdf
CGA3E3X7R1H224K080AB | C152 C154 | 2 |  | 260 | Exact TDK product page links general June2026 delivery specification. NumericMSL is not published in either reviewed page/specification and is not borrowed from CeraLink or another vendor. Store5…40C/20…70%RH,original packaging,usewithin6months or verify solderability;avoid condensation. Lead-free reflow≤260C/≤10s;preheat delta≤150C for0603/0805,≤130C for1210. Follow exact cleaning/thermal-shock rules; soft termination contains resin and must not be called resinless. | https://product.tdk.com/system/files/dam/doc/product/capacitor/ceramic/mlcc/specification/mlccspec_automotive_general_en.pdf
CGA4J2X7R2A104K125AA | C101 C123 C503 | 3 |  | 260 | Exact TDK product page links general June2026 delivery specification. NumericMSL is not published in either reviewed page/specification and is not borrowed from CeraLink or another vendor. Store5…40C/20…70%RH,original packaging,usewithin6months or verify solderability;avoid condensation. Lead-free reflow≤260C/≤10s;preheat delta≤150C for0603/0805,≤130C for1210. Follow exact cleaning/thermal-shock rules; soft termination contains resin and must not be called resinless. | https://product.tdk.com/system/files/dam/doc/product/capacitor/ceramic/mlcc/specification/mlccspec_automotive_general_en.pdf
CGA6N3X7R2A225K230AB | C103 C121 C122 C129 | 4 |  | 260 | Exact TDK product page links general June2026 delivery specification. NumericMSL is not published in either reviewed page/specification and is not borrowed from CeraLink or another vendor. Store5…40C/20…70%RH,original packaging,usewithin6months or verify solderability;avoid condensation. Lead-free reflow≤260C/≤10s;preheat delta≤150C for0603/0805,≤130C for1210. Follow exact cleaning/thermal-shock rules; soft termination contains resin and must not be called resinless. | https://product.tdk.com/system/files/dam/doc/product/capacitor/ceramic/mlcc/specification/mlccspec_automotive_general_en.pdf
CRCW06030000Z0EA | R401 | 1 | NOT_APPLICABLE |  | Exact MPN manufacturer quality row: Not Applicable. This is preserved as the manufacturer designation, not silently relabeled numeric MSL1. Applicable chip-resistor assembly source supports IEC61760-1 reflow/wave/vapor and common solvent cleaning; no arbitrary coating/potting or ultrasonic process acceptance follows. Exact profile and solderability of aged stock must be checked. | https://www.vishay.com/en/product/20035/tab/quality/
CRCW0603100KFKEA | R108 R127 R152 R407 R408 R409 R411 R506 | 8 | NOT_APPLICABLE |  | Exact MPN manufacturer quality row: Not Applicable. This is preserved as the manufacturer designation, not silently relabeled numeric MSL1. Applicable chip-resistor assembly source supports IEC61760-1 reflow/wave/vapor and common solvent cleaning; no arbitrary coating/potting or ultrasonic process acceptance follows. Exact profile and solderability of aged stock must be checked. | https://www.vishay.com/en/product/20035/tab/quality/
CRCW060310K0FKEA | R157 R201 R202 R303 R410 | 5 | NOT_APPLICABLE |  | Exact MPN manufacturer quality row: Not Applicable. This is preserved as the manufacturer designation, not silently relabeled numeric MSL1. Applicable chip-resistor assembly source supports IEC61760-1 reflow/wave/vapor and common solvent cleaning; no arbitrary coating/potting or ultrasonic process acceptance follows. Exact profile and solderability of aged stock must be checked. | https://www.vishay.com/en/product/20035/tab/quality/
CRCW060310R0FKEA | R106 | 1 | NOT_APPLICABLE |  | Exact MPN manufacturer quality row: Not Applicable. This is preserved as the manufacturer designation, not silently relabeled numeric MSL1. Applicable chip-resistor assembly source supports IEC61760-1 reflow/wave/vapor and common solvent cleaning; no arbitrary coating/potting or ultrasonic process acceptance follows. Exact profile and solderability of aged stock must be checked. | https://www.vishay.com/en/product/20035/tab/quality/
CRCW06031K00FKEA | R154 R203 R302 R405 R601 R602 R603 R604 R605 R606 | 10 | NOT_APPLICABLE |  | Exact MPN manufacturer quality row: Not Applicable. This is preserved as the manufacturer designation, not silently relabeled numeric MSL1. Applicable chip-resistor assembly source supports IEC61760-1 reflow/wave/vapor and common solvent cleaning; no arbitrary coating/potting or ultrasonic process acceptance follows. Exact profile and solderability of aged stock must be checked. | https://www.vishay.com/en/product/20035/tab/quality/
CRCW06035K10FKEA | R107 | 1 | NOT_APPLICABLE |  | Exact MPN manufacturer quality row: Not Applicable. This is preserved as the manufacturer designation, not silently relabeled numeric MSL1. Applicable chip-resistor assembly source supports IEC61760-1 reflow/wave/vapor and common solvent cleaning; no arbitrary coating/potting or ultrasonic process acceptance follows. Exact profile and solderability of aged stock must be checked. | https://www.vishay.com/en/product/20035/tab/quality/
CRCW12060000Z0EA | R109 R128 R151 | 3 | NOT_APPLICABLE |  | Exact MPN manufacturer quality row: Not Applicable. This is preserved as the manufacturer designation, not silently relabeled numeric MSL1. Applicable chip-resistor assembly source supports IEC61760-1 reflow/wave/vapor and common solvent cleaning; no arbitrary coating/potting or ultrasonic process acceptance follows. Exact profile and solderability of aged stock must be checked. | https://www.vishay.com/en/product/20035/tab/quality/
CRCW1206100KFKEA | R111 R125 | 2 | NOT_APPLICABLE |  | Exact MPN manufacturer quality row: Not Applicable. This is preserved as the manufacturer designation, not silently relabeled numeric MSL1. Applicable chip-resistor assembly source supports IEC61760-1 reflow/wave/vapor and common solvent cleaning; no arbitrary coating/potting or ultrasonic process acceptance follows. Exact profile and solderability of aged stock must be checked. | https://www.vishay.com/en/product/20035/tab/quality/
CRCW1206510KFKEA | R105 | 1 | NOT_APPLICABLE |  | Exact MPN manufacturer quality row: Not Applicable. This is preserved as the manufacturer designation, not silently relabeled numeric MSL1. Applicable chip-resistor assembly source supports IEC61760-1 reflow/wave/vapor and common solvent cleaning; no arbitrary coating/potting or ultrasonic process acceptance follows. Exact profile and solderability of aged stock must be checked. | https://www.vishay.com/en/product/20035/tab/quality/
CRCW25124R70FKEGHP | R507 | 1 | NOT_APPLICABLE |  | Exact MPN manufacturer quality row: Not Applicable. This is preserved as the manufacturer designation, not silently relabeled numeric MSL1. Applicable chip-resistor assembly source supports IEC61760-1 reflow/wave/vapor and common solvent cleaning; no arbitrary coating/potting or ultrasonic process acceptance follows. Exact profile and solderability of aged stock must be checked. | https://www.vishay.com/en/product/20043/tab/quality/
CRCW25126K81FKEG | R101 | 1 | NOT_APPLICABLE |  | Exact MPN manufacturer quality row: Not Applicable. This is preserved as the manufacturer designation, not silently relabeled numeric MSL1. Applicable chip-resistor assembly source supports IEC61760-1 reflow/wave/vapor and common solvent cleaning; no arbitrary coating/potting or ultrasonic process acceptance follows. Exact profile and solderability of aged stock must be checked. | https://www.vishay.com/en/product/20035/tab/quality/
ERA3AEB1472V | R104 | 1 |  | 260 | Exact ERA3 family/product-linked rectangular resistor profile:lead-free peak≤260C/≤10s,above230C30–40s,preheat150…180C60–120s,maximumtwo reflows. ERA datasheet storage5…35C/45…85%RH,≤1year. Use rosin flux; highly acidic/water-soluble/fluoride flux prohibited; cleaning/coating needs process validation. No numericMSL found in reviewed primary docs; retain exact receiving declaration. | https://industrial.panasonic.com/cdbs/www-data/pdf/RDM0000/DMM0000COL14.pdf
ERA3AEB2612V | R126 | 1 |  | 260 | Exact ERA3 family/product-linked rectangular resistor profile:lead-free peak≤260C/≤10s,above230C30–40s,preheat150…180C60–120s,maximumtwo reflows. ERA datasheet storage5…35C/45…85%RH,≤1year. Use rosin flux; highly acidic/water-soluble/fluoride flux prohibited; cleaning/coating needs process validation. No numericMSL found in reviewed primary docs; retain exact receiving declaration. | https://industrial.panasonic.com/cdbs/www-data/pdf/RDM0000/DMM0000COL14.pdf
ESD2CAN24DBZRQ1 | D301 D501 | 2 | 1 | 260 | Exact orderable-part row; shipping label controls lot exposure. | baseline/GR86_CCA_RevB/evidence/manufacturer/esd2can24_q1.pdf
ESP32-S3-WROOM-1-N8R2 | U201 | 1 | 3 | 250 | Open-bag168h at25±5C/60%RH; apply exact manufacturer bake procedure only if required. | baseline/GR86_CCA_RevB/evidence/manufacturer/espressif_esp32_s3_wroom1.pdf
GCM188R71C105KA64D | C153 C302 C511 C512 C521 C522 | 6 | 1 | 260 | Murata chip MLCC family explicitly MSL1; resin-molded exceptions do not apply. GCM exact approval documents allow240–260C lead-free peak; GRM reflow maximum is not borrowed from GCM. Avoid thermal shock; retain exact part storage/solderability and board-process checks. | https://www.murata.com/en-eu/support/faqs/capacitor/ceramiccapacitor/mnt/0009
GCM188R71H104KA57D | C158 C202 C205 C301 C403 C404 C405 C502 C531 | 9 | 1 | 260 | Murata chip MLCC family explicitly MSL1; resin-molded exceptions do not apply. GCM exact approval documents allow240–260C lead-free peak; GRM reflow maximum is not borrowed from GCM. Avoid thermal shock; retain exact part storage/solderability and board-process checks. | https://www.murata.com/en-eu/support/faqs/capacitor/ceramiccapacitor/mnt/0009
GRM1885C1H103JA01D | C532 | 1 | 1 |  | Murata chip MLCC family explicitly MSL1; resin-molded exceptions do not apply. GCM exact approval documents allow240–260C lead-free peak; GRM reflow maximum is not borrowed from GCM. Avoid thermal shock; retain exact part storage/solderability and board-process checks. | https://www.murata.com/en-eu/support/faqs/capacitor/ceramiccapacitor/mnt/0009
LM5164DDAR | U121 | 1 | 2 | 260 | Exact TI manufacturer part page read2026-09-09; not borrowed from Q1/non-Q sibling. | https://www.ti.com/product/LM5164/part-details/LM5164DDAR
LM63615DQPWPRQ1 | U151 | 1 | 3 | 260 | Exact orderable-part row; shipping label controls lot exposure. | baseline/GR86_CCA_RevB/evidence/manufacturer/lm63615_q1.pdf
LQW18AS1N6J0ZD | L406 | 1 | 1 | 260 | Public manufacturer inductor MSL table covers LQ* as1. Exact JELF243A_9139E-01 reference row;recommended reflow245±3C,limit260C/10s,two cycles. Store−10…40C/15…85%RH;usewithin12months or check solderability. IPAcleaning≤40C,other listedcleaning≤60C;do not contact winding with tweezers/brushes. No assembled-board ultrasonic authorization. | https://search.murata.co.jp/Ceramy/image/img/P02/JELF243A-9139.pdf
LTC4367HMS8#WTRPBF | U101 | 1 | 1 |  | ADI/Linear primary package table dated2016-04-26 explicitly lists MS8 8-lead MSOP MSL1/no drypack. Actual LTC4367 order code uses MS8. Table defers peak body temperature to J-STD020; datasheet300C/10s lead-local rating is not a whole-body reflow allowance. | https://www.analog.com/media/en/quality-documentation/msl-package_26apr2016.pdf
MCAST32MSB7226KPNA01 | C127 C128 C151 C155 C156 C157 C201 C204 C401 C402 | 10 | NOT_APPLICABLE |  | Taiyo Yuden states resinless ceramic capacitors are outside MSL regulation. No numericMSL1 is assigned. Store and solder according to the exact automotive MLCC specification. | https://www.yuden.co.jp/en/product/support/useful/faq/mlcc/
MIC5504-3.3YM5-TR | U403 | 1 | 1 |  | Exact Microchip material-compliance API row identifies MIC5504-3.3YM5-TR/SOT-23/5 leads/NiPdAu and MSL-1. This does not turn datasheet local-lead260C/10s into whole-body reflow qualification. | https://www.microchip.com/en-us/about/corporate-responsibility/our-products/product-material-compliance.MIC5504-3.3YM5-TR.html
MSS1246T-473MLC | L121 | 1 | 1 | 260 | Family explicitlyMSL1; permitted3x40s at260C, cool between cycles; vendor washing document applies. | baseline/GR86_CCA_RevB/evidence/manufacturer/mss1246t.pdf
OPA2333AIDR | U502 | 1 | 1 | 260 | Exact TI manufacturer part page read2026-09-09; not borrowed from Q1/non-Q sibling. | https://www.ti.com/product/OPA2333/part-details/OPA2333AIDR
PA1616D | U401 | 1 |  |  | MANUAL_GPS/selective after global. Manufacturer requires prebaking before any SMT reflow; if double-sided reflow, module on second pass only unless first-pass process is separately agreed. Datasheet gives no numeric MSL or bake time/temperature; do not invent125C/24h. Reflow profile must be measured, and selective assembly still requires compatible local heat/cleaning procedure. | baseline/GR86_CCA_RevB/evidence/manufacturer/pa1616d_v06.pdf
PMEG2010BEA,115 | D511 D512 D521 D522 | 4 |  | 260 | Exact live product API maps PMEG2010BEA,115 to its chemical report, but that report was unavailable403;no MSL is borrowed from PMEG2010BEA-Q. Manufacturer SOD323 page links Feb2026 reflow guide:body<1.6mm gives260Cclassification,typ245Cpeak,three cycles,20–30swithin5Cpeak recommended. This recommended dwell differs from the board10speak allocation; assembler must validate compatible measured profile, not assume all dwell definitions identical. | https://assets.nexperia.com/documents/other-type/REFLOW_BG-BD-1.pdf
S5DHE3_A/H | D101 | 1 | 1 | 260 | Exact voltage/type and automotive suffix are within manufacturer family ordering information; family explicitly specifies MSL1 and lead-free maximum peak260C. Time/ramp/repeat-cycle and lot-label controls remain. | baseline/GR86_CCA_RevB/evidence/manufacturer/s5a.pdf
SMAJ30AHE3_A/H | D102 | 1 | 1 | 260 | Exact voltage/type and automotive suffix are within manufacturer family ordering information; family explicitly specifies MSL1 and lead-free maximum peak260C. Time/ramp/repeat-cycle and lot-label controls remain. | baseline/GR86_CCA_RevB/evidence/manufacturer/smaj.pdf
SMCJ24AHE3_A/H | D103 | 1 | 1 | 260 | Exact voltage/type and automotive suffix are within manufacturer family ordering information; family explicitly specifies MSL1 and lead-free maximum peak260C. Time/ramp/repeat-cycle and lot-label controls remain. | baseline/GR86_CCA_RevB/evidence/manufacturer/smcj.pdf
SN74LVC2G125DCUR | U402 U404 | 2 | 1 | 260 | Exact TI manufacturer part page read2026-09-09; not borrowed from Q1/non-Q sibling. | https://www.ti.com/product/SN74LVC2G125/part-details/SN74LVC2G125DCUR
SS16HE3_B/H | D502 | 1 | 1 | 260 | Exact voltage/type and automotive suffix are within manufacturer family ordering information; family explicitly specifies MSL1 and lead-free maximum peak260C. Time/ramp/repeat-cycle and lot-label controls remain. | https://www.vishay.com/docs/88746/ss12.pdf
STD25NF20 | Q101 | 1 | 1 | 260 | Manufacturer material declaration explicitly names STD25NF20/XMDP*MM2GA62,dated2020-04-08;MSL1,260C,three reflows. Current exact ST product page links this report; sites/material variation and actual lot labels remain controlled. | https://www.st.com/resource/en/material_declaration/md_dp-wspc-to-wspc-252-wspc-dpak_xmdpmm2ga62.pdf
T598X477M006ATE025 | C206 | 1 | 3 | 260 | Exact X-case table and family storage:168h30C/60%RH; return unused parts to sealed fresh-desiccant MBB; maximumthree specified reflows. | lanes/mechanics/sources/KEM_T2073_T59X.pdf
TCAN3403DRBRQ1 | U301 | 1 | 2 | 260 | Exact orderable-part row; shipping label controls lot exposure. | baseline/GR86_CCA_RevB/evidence/manufacturer/tcan3403_q1.pdf
TNPU060311K8HWEA00 | R155 | 1 |  |  | TNPU e3 manufacturer Assembly section permits automatic wave/reflow/vapor-phase processing and common electronics cleaning solvents. Coating/potting compatibility remains application-specific. Numeric MSL and a numeric production peak are not stated here and are not invented. | https://www.vishay.com/docs/28779/tnpue3.pdf
TNPU06034K99HWEA00 | R156 | 1 |  |  | TNPU e3 manufacturer Assembly section permits automatic wave/reflow/vapor-phase processing and common electronics cleaning solvents. Coating/potting compatibility remains application-specific. Numeric MSL and a numeric production peak are not stated here and are not invented. | https://www.vishay.com/docs/28779/tnpue3.pdf
TNPW0603100KBEEA | R123 | 1 | NOT_APPLICABLE |  | Exact MPN manufacturer quality row: Not Applicable. This is preserved as the manufacturer designation, not silently relabeled numeric MSL1. Applicable chip-resistor assembly source supports IEC61760-1 reflow/wave/vapor and common solvent cleaning; no arbitrary coating/potting or ultrasonic process acceptance follows. Exact profile and solderability of aged stock must be checked. | https://www.vishay.com/en/product/28758/tab/quality/
TNPW060310K0BEEA | R502 R504 | 2 | NOT_APPLICABLE |  | Exact MPN manufacturer quality row: Not Applicable. This is preserved as the manufacturer designation, not silently relabeled numeric MSL1. Applicable chip-resistor assembly source supports IEC61760-1 reflow/wave/vapor and common solvent cleaning; no arbitrary coating/potting or ultrasonic process acceptance follows. Exact profile and solderability of aged stock must be checked. | https://www.vishay.com/en/product/28758/tab/quality/
TNPW06031K00BEEA | R514 R524 | 2 | NOT_APPLICABLE |  | Exact MPN manufacturer quality row: Not Applicable. This is preserved as the manufacturer designation, not silently relabeled numeric MSL1. Applicable chip-resistor assembly source supports IEC61760-1 reflow/wave/vapor and common solvent cleaning; no arbitrary coating/potting or ultrasonic process acceptance follows. Exact profile and solderability of aged stock must be checked. | https://www.vishay.com/en/product/28758/tab/quality/
TNPW060324K3BEEA | R103 | 1 | NOT_APPLICABLE |  | Exact MPN manufacturer quality row: Not Applicable. This is preserved as the manufacturer designation, not silently relabeled numeric MSL1. Applicable chip-resistor assembly source supports IEC61760-1 reflow/wave/vapor and common solvent cleaning; no arbitrary coating/potting or ultrasonic process acceptance follows. Exact profile and solderability of aged stock must be checked. | https://www.vishay.com/en/product/28758/tab/quality/
TNPW060327K4BEEA | R501 | 1 | NOT_APPLICABLE |  | Exact MPN manufacturer quality row: Not Applicable. This is preserved as the manufacturer designation, not silently relabeled numeric MSL1. Applicable chip-resistor assembly source supports IEC61760-1 reflow/wave/vapor and common solvent cleaning; no arbitrary coating/potting or ultrasonic process acceptance follows. Exact profile and solderability of aged stock must be checked. | https://www.vishay.com/en/product/28758/tab/quality/
TNPW060331K6BEEA | R121 | 1 | NOT_APPLICABLE |  | Exact MPN manufacturer quality row: Not Applicable. This is preserved as the manufacturer designation, not silently relabeled numeric MSL1. Applicable chip-resistor assembly source supports IEC61760-1 reflow/wave/vapor and common solvent cleaning; no arbitrary coating/potting or ultrasonic process acceptance follows. Exact profile and solderability of aged stock must be checked. | https://www.vishay.com/en/product/28758/tab/quality/
TNPW060336K5BEEA | R503 | 1 | NOT_APPLICABLE |  | Exact MPN manufacturer quality row: Not Applicable. This is preserved as the manufacturer designation, not silently relabeled numeric MSL1. Applicable chip-resistor assembly source supports IEC61760-1 reflow/wave/vapor and common solvent cleaning; no arbitrary coating/potting or ultrasonic process acceptance follows. Exact profile and solderability of aged stock must be checked. | https://www.vishay.com/en/product/28758/tab/quality/
TNPW060343K2BEEA | R124 | 1 | NOT_APPLICABLE |  | Exact MPN manufacturer quality row: Not Applicable. This is preserved as the manufacturer designation, not silently relabeled numeric MSL1. Applicable chip-resistor assembly source supports IEC61760-1 reflow/wave/vapor and common solvent cleaning; no arbitrary coating/potting or ultrasonic process acceptance follows. Exact profile and solderability of aged stock must be checked. | https://www.vishay.com/en/product/28758/tab/quality/
TNPW06034K02BEEA | R512 R522 | 2 | NOT_APPLICABLE |  | Exact MPN manufacturer quality row: Not Applicable. This is preserved as the manufacturer designation, not silently relabeled numeric MSL1. Applicable chip-resistor assembly source supports IEC61760-1 reflow/wave/vapor and common solvent cleaning; no arbitrary coating/potting or ultrasonic process acceptance follows. Exact profile and solderability of aged stock must be checked. | https://www.vishay.com/en/product/28758/tab/quality/
TNPW0805118KBEEA | R505 | 1 | NOT_APPLICABLE |  | Exact MPN manufacturer quality row: Not Applicable. This is preserved as the manufacturer designation, not silently relabeled numeric MSL1. Applicable chip-resistor assembly source supports IEC61760-1 reflow/wave/vapor and common solvent cleaning; no arbitrary coating/potting or ultrasonic process acceptance follows. Exact profile and solderability of aged stock must be checked. | https://www.vishay.com/en/product/28758/tab/quality/
TNPW0805124KBEEA | R513 R523 | 2 | NOT_APPLICABLE |  | Exact MPN manufacturer quality row: Not Applicable. This is preserved as the manufacturer designation, not silently relabeled numeric MSL1. Applicable chip-resistor assembly source supports IEC61760-1 reflow/wave/vapor and common solvent cleaning; no arbitrary coating/potting or ultrasonic process acceptance follows. Exact profile and solderability of aged stock must be checked. | https://www.vishay.com/en/product/28758/tab/quality/
TNPW08051M00BEEA | R511 R521 | 2 | NOT_APPLICABLE |  | Exact MPN manufacturer quality row: Not Applicable. This is preserved as the manufacturer designation, not silently relabeled numeric MSL1. Applicable chip-resistor assembly source supports IEC61760-1 reflow/wave/vapor and common solvent cleaning; no arbitrary coating/potting or ultrasonic process acceptance follows. Exact profile and solderability of aged stock must be checked. | https://www.vishay.com/en/product/28758/tab/quality/
TNPW0805309KBEEA | R122 | 1 | NOT_APPLICABLE |  | Exact MPN manufacturer quality row: Not Applicable. This is preserved as the manufacturer designation, not silently relabeled numeric MSL1. Applicable chip-resistor assembly source supports IEC61760-1 reflow/wave/vapor and common solvent cleaning; no arbitrary coating/potting or ultrasonic process acceptance follows. Exact profile and solderability of aged stock must be checked. | https://www.vishay.com/en/product/28758/tab/quality/
TNPW1206549KBEEA | R102 | 1 | NOT_APPLICABLE |  | Exact MPN manufacturer quality row: Not Applicable. This is preserved as the manufacturer designation, not silently relabeled numeric MSL1. Applicable chip-resistor assembly source supports IEC61760-1 reflow/wave/vapor and common solvent cleaning; no arbitrary coating/potting or ultrasonic process acceptance follows. Exact profile and solderability of aged stock must be checked. | https://www.vishay.com/en/product/28758/tab/quality/
TPD1E05U06DPYR | D402 | 1 | 1 | 260 | Exact TI manufacturer part page read2026-09-09; not borrowed from Q1/non-Q sibling. | https://www.ti.com/product/TPD1E05U06/part-details/TPD1E05U06DPYR
TPS26600PWPR | U501 | 1 | 2 | 260 | Exact orderable-part row; shipping label controls lot exposure. | baseline/GR86_CCA_RevB/evidence/manufacturer/tps2660.pdf
TPS3808G33QDBVRQ1 | U202 | 1 | 1 | 260 | Exact TI manufacturer part page read2026-09-09; not borrowed from Q1/non-Q sibling. | https://www.ti.com/product/TPS3808-Q1/part-details/TPS3808G33QDBVRQ1
U.FL-R-SMT-1(80) | J401 | 1 |  | 250 | Manufacturer profile: board/lead surface≤250C for≤10s,≤2cycles; localmanual350C≤5s,stencil0.10–0.12mm. Original packaging storage−10…40C/≤85%RH/≤6months; longer storage requires solderability confirmation. NumericMSL is not listed in the reviewed document. Keep unmated connector clean; no whole-board wash approval inferred. | baseline/GR86_CCA_RevB/evidence/manufacturer/hirose_ufl.pdf
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

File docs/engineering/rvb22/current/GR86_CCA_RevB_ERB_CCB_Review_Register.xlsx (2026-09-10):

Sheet: Review Register
RVB22 current criterion disposition | original questions and required evidence preserved
RVB-21 | Original questions and required evidence A–F preserved. Evidence status G is distinct from criterion closure N. Candidate source corrections require native/target verification; see RVB21 Changes. | RVB-21 | Original questions and required evidence A–F preserved. Evidence status G is distinct from criterion closure N. Candidate source corrections require native/target verification; see RVB21 Changes. | RVB-21 | Original questions and required evidence A–F preserved. Evidence status G is distinct from criterion closure N. Candidate source corrections require native/target verification; see RVB21 Changes. | RVB-21 | Original questions and required evidence A–F preserved. Evidence status G is distinct from criterion closure N. Candidate source corrections require native/target verification; see RVB21 Changes. | RVB-21 | Original questions and required evidence A–F preserved. Evidence status G is distinct from criterion closure N. Candidate source corrections require native/target verification; see RVB21 Changes. | RVB-21 | Original questions and required evidence A–F preserved. Evidence status G is distinct from criterion closure N. Candidate source corrections require native/target verification; see RVB21 Changes. | RVB-21 | Original questions and required evidence A–F preserved. Evidence status G is distinct from criterion closure N. Candidate source corrections require native/target verification; see RVB21 Changes. | RVB-21 | Original questions and required evidence A–F preserved. Evidence status G is distinct from criterion closure N. Candidate source corrections require native/target verification; see RVB21 Changes. | RVB-21 | Original questions and required evidence A–F preserved. Evidence status G is distinct from criterion closure N. Candidate source corrections require native/target verification; see RVB21 Changes. | RVB-21 | Original questions and required evidence A–F preserved. Evidence status G is distinct from criterion closure N. Candidate source corrections require native/target verification; see RVB21 Changes. | RVB-21 | Original questions and required evidence A–F preserved. Evidence status G is distinct from criterion closure N. Candidate source corrections require native/target verification; see RVB21 Changes. | RVB-21 | Original questions and required evidence A–F preserved. Evidence status G is distinct from criterion closure N. Candidate source corrections require native/target verification; see RVB21 Changes. | RVB-21 | Original questions and required evidence A–F preserved. Evidence status G is distinct from criterion closure N. Candidate source corrections require native/target verification; see RVB21 Changes.
ID | Review domain | Priority | Earliest principal gate | Review question | Required evidence / closure | Evidence status | Reviewer / discipline | Finding and next action | Current evidence / confidence | Applicability | Source basis | Source URL | Closure
CFG-01 | Configuration and review scope | P0 | G0 Definition | What exact PCB revision, assembly revision, serial number, harness and firmware commit are under review? | One configuration cover sheet ties the physical board to CAD, populated BOM, rework list, harness and flashed binary. | CURRENT SOURCE OR MODEL WITH REMAINING CONDITIONS | RVB22 coordinated engineering review | I20 native source and matched outputs have been verified. The original evidence scope below remains controlling. Original criterion disposition remains open. The prior detailed assessment is retained in previous_I06_disposition and the historical register; current evidence and remaining conditions govern this row. CRITERION: OPEN DESKTOP: HARDWARE OR INSTALLATION ACCEPTANCE REMAINING: physical serial, fitted harness and flash readback cannot be supplied from CAD. | control/EXECUTION_PLAN_CURRENT.md control/CLOSED_CRITERIA_ADJUDICATION.json current/I21_SOURCE_VERIFICATION.json iterations/I20_controlled_handoff/NATIVE_BINDING.json current/SOURCE_EFFECTIVITY.json current/I22_SOURCE_VERIFICATION.json | Rev B; characterize Rev A only within its approved bench limits | R1 |  | OPEN
CFG-02 | Configuration and review scope | P0 | G0 Definition | Are as-designed, as-built and as-tested configurations explicitly reconciled? | Photographs and continuity evidence account for every bodge, removed part, isolation link and test supply. | CURRENT SOURCE OR MODEL WITH REMAINING CONDITIONS | RVB22 coordinated engineering review | I20 native source and matched outputs have been verified. The original evidence scope below remains controlling. Original criterion disposition remains open. The prior detailed assessment is retained in previous_I06_disposition and the historical register; current evidence and remaining conditions govern this row. CRITERION: OPEN DESKTOP: HARDWARE OR INSTALLATION ACCEPTANCE REMAINING: actual bodge/removal photographs and unit continuity remain. | interfaces/HARNESS_INTERFACE_CONTRACT.json interfaces/HARNESS_CHECKS.json analyses/harness_wire/HARNESS_WIRE_DELTA.json current/I21_SOURCE_VERIFICATION.json iterations/I20_controlled_handoff/NATIVE_BINDING.json current/SOURCE_EFFECTIVITY.json current/I22_SOURCE_VERIFICATION.json | Rev B; characterize Rev A only within its approved bench limits | R1 |  | OPEN
CFG-03 | Configuration and review scope | P0 | G0 Definition | Is this a bench characterization review, fabrication release, or vehicle-use release? | The review charter identifies the requested decision, constraints, approvers and prohibited operations. | CLOSED BY ORIGINAL SCOPE | RVB22 coordinated engineering review | I20 native source and matched outputs have been verified. The original evidence scope below remains controlling. Original criterion disposition remains closed. The prior detailed assessment is retained in previous_I06_disposition and the historical register; current evidence and remaining conditions govern this row. CRITERION: CLOSED DESKTOP: CURRENT EVIDENCE REVIEWED REMAINING: | control/EXECUTION_PLAN_CURRENT.md control/RECOVERY_LEDGER.md control/DESKTOP_ACTION_DISPOSITIONS_CURRENT.json iterations/I06_harness_handoff/CANDIDATE_MANIFEST.json control/FINAL_GATES.json current/I21_SOURCE_VERIFICATION.json iterations/I20_controlled_handoff/NATIVE_BINDING.json current/SOURCE_EFFECTIVITY.json current/I22_SOURCE_VERIFICATION.json | Rev B; characterize Rev A only within its approved bench limits | R1 |  | CLOSED
CFG-04 | Configuration and review scope | P0 | G0 Definition | What controlled source supersedes each earlier Rev A finding or Rev B instruction? | Evidence precedence and a dated supersession log; no historical issue disappears without disposition. | CLOSED BY ORIGINAL SCOPE | RVB22 coordinated engineering review | I20 native source and matched outputs have been verified. The original evidence scope below remains controlling. Original criterion disposition remains closed. The prior detailed assessment is retained in previous_I06_disposition and the historical register; current evidence and remaining conditions govern this row. CRITERION: CLOSED DESKTOP: CURRENT EVIDENCE REVIEWED REMAINING: | control/EXECUTION_PLAN_CURRENT.md control/RECOVERY_LEDGER.md control/DESKTOP_ACTION_DISPOSITIONS_CURRENT.json iterations/I06_harness_handoff/CANDIDATE_MANIFEST.json control/FINAL_GATES.json current/I21_SOURCE_VERIFICATION.json iterations/I20_controlled_handoff/NATIVE_BINDING.json current/SOURCE_EFFECTIVITY.json current/I22_SOURCE_VERIFICATION.json | Rev B; characterize Rev A only within its approved bench limits | R1 |  | CLOSED
CFG-05 | Configuration and review scope | P0 | G0 Definition | Is the current Rev B candidate on HOLD, and what individually closes that hold? | Named blockers, objective acceptance criteria and authorized sign-off; a status label alone is not closure. | CLOSED BY ORIGINAL SCOPE | RVB22 coordinated engineering review | I20 native source and matched outputs have been verified. The original evidence scope below remains controlling. Original criterion disposition remains closed. The prior detailed assessment is retained in previous_I06_disposition and the historical register; current evidence and remaining conditions govern this row. CRITERION: CLOSED DESKTOP: CURRENT EVIDENCE REVIEWED REMAINING: | control/EXECUTION_PLAN_CURRENT.md control/RECOVERY_LEDGER.md control/DESKTOP_ACTION_DISPOSITIONS_CURRENT.json iterations/I06_harness_handoff/CANDIDATE_MANIFEST.json control/FINAL_GATES.json current/I21_SOURCE_VERIFICATION.json iterations/I20_controlled_handoff/NATIVE_BINDING.json current/SOURCE_EFFECTIVITY.json current/I22_SOURCE_VERIFICATION.json | Rev B; characterize Rev A only within its approved bench limits | R1 |  | CLOSED
CFG-06 | Configuration and review scope | P1 | G0 Definition | Which board and harness population variants are allowed? | Variant matrix with DNP, jumper defaults, antenna options and compatible firmware. | CLOSED BY ORIGINAL SCOPE | RVB22 coordinated engineering review | I20 native source and matched outputs have been verified. The original evidence scope below remains controlling. Original criterion disposition remains closed. The prior detailed assessment is retained in previous_I06_disposition and the historical register; current evidence and remaining conditions govern this row. CRITERION: CLOSED DESKTOP: CURRENT EVIDENCE REVIEWED REMAINING: | interfaces/HARNESS_INTERFACE_CONTRACT.json interfaces/HARNESS_CHECKS.json analyses/harness_wire/HARNESS_WIRE_DELTA.json interfaces/MOLEX_A1_HARNESS_REDLINE.json interfaces/SINGLE_RETURN_EFFECTIVITY.json interfaces/FINAL_I06_HARNESS_BINDING.json iterations/I06_harness_handoff/CANDIDATE_MANIFEST.json current/I21_SOURCE_VERIFICATION.json iterations/I20_controlled_handoff/NATIVE_BINDING.json current/SOURCE_EFFECTIVITY.json current/I22_SOURCE_VERIFICATION.json | Rev B; characterize Rev A only within its approved bench limits | R1 |  | CLOSED
CFG-07 | Configuration and review scope | P0 | G0 Definition | Are all design assumptions that affect safety, manufacture or interfaces visible? | Assumptions register with owner, verification method and required closure gate. | CLOSED BY ORIGINAL SCOPE | RVB22 coordinated engineering review | I20 native source and matched outputs have been verified. The original evidence scope below remains controlling. Original criterion disposition remains closed. The prior detailed assessment is retained in previous_I06_disposition and the historical register; current evidence and remaining conditions govern this row. CRITERION: CLOSED DESKTOP: CURRENT EVIDENCE REVIEWED REMAINING: | control/EXECUTION_PLAN_CURRENT.md control/RECOVERY_LEDGER.md control/DESKTOP_ACTION_DISPOSITIONS_CURRENT.json iterations/I06_harness_handoff/CANDIDATE_MANIFEST.json control/FINAL_GATES.json current/I21_SOURCE_VERIFICATION.json iterations/I20_controlled_handoff/NATIVE_BINDING.json current/SOURCE_EFFECTIVITY.json current/I22_SOURCE_VERIFICATION.json | Rev B; characterize Rev A only within its approved bench limits | R1 |  | CLOSED
CFG-08 | Configuration and review scope | P1 | G0 Definition | Can another engineer open and regenerate the source with the specified tools and libraries? | Archived tool versions, project-local libraries, generation commands and clean reproducibility check. | CLOSED BY ORIGINAL SCOPE | RVB22 coordinated engineering review | Pinned KiCad 9.0.9 and firmware workflow successfully opened and regenerated the I20 candidate. All 101 CAD inputs, 32 firmware inputs and 774 output files were freshly checked against their hashes. CRITERION: CLOSED DESKTOP: COMPLETED CURRENT SOURCE VERIFICATION REMAINING: Original documentary, design-inspection or execution scope satisfied. Related supplier and physical criteria retain their own dispositions. | iterations/I20_controlled_handoff/NATIVE_BINDING.json current/I21_SOURCE_VERIFICATION.json current/SOURCE_EFFECTIVITY.json current/I22_SOURCE_VERIFICATION.json | Rev B; characterize Rev A only within its approved bench limits | R1 |  | CLOSED
CFG-09 | Configuration and review scope | P1 | G0 Definition | Does the review include the actual installation, harness, antenna, sensor and phone rather than only the PCB? | System boundary diagram and representative hardware configuration. | CURRENT SOURCE OR MODEL WITH REMAINING CONDITIONS | RVB22 coordinated engineering review | Selected sensor, harness and Adafruit 851/960 accessory identities are controlled. Complete installed harness, mounting environment and phone/OS context still need actual-unit records. CRITERION: OPEN DESKTOP: COMPLETED CONDITIONAL MODEL REMAINING: Record the actual installed harness/mounting and phone/OS configuration; accessory product IDs no longer require clarification. | analyses/installation/DASHBOARD_EXPOSURE_AND_SERVICE.md lanes/mechanics/MECHANICAL_INSTALLATION_RVB22.md current/I21_SOURCE_VERIFICATION.json iterations/I20_controlled_handoff/NATIVE_BINDING.json current/SOURCE_EFFECTIVITY.json current/I22_SOURCE_VERIFICATION.json analyses/review_i22/ACCESSORY_APPLICABILITY.json analyses/mated_i22/RESULTS.json current/ACCESSORY_REVIEW.md | Rev B; characterize Rev A only within its approved bench limits | R1 |  | OPEN
CFG-10 | Configuration and review scope | P0 | G0 Definition | Has the Rev A prohibited original 12 V path remained clearly segregated from approved bypass-rail tests? | Bench wiring authorization and labels follow the historical safety constraints until a new approved disposition. | CLOSED BY ORIGINAL SCOPE | RVB22 coordinated engineering review | I20 native source and matched outputs have been verified. The original evidence scope below remains controlling. Original criterion disposition remains closed. The prior detailed assessment is retained in previous_I06_disposition and the historical register; current evidence and remaining conditions govern this row. CRITERION: CLOSED DESKTOP: CURRENT EVIDENCE REVIEWED REMAINING: | iterations/I06_harness_handoff/CANDIDATE_MANIFEST.json current/I21_SOURCE_VERIFICATION.json iterations/I20_controlled_handoff/NATIVE_BINDING.json current/SOURCE_EFFECTIVITY.json current/I22_SOURCE_VERIFICATION.json | Rev B; characterize Rev A only within its approved bench limits | R1 |  | CLOSED
REQ-01 | Requirements and interfaces | P0 | G0 Definition | Is passive vehicle telemetry the agreed function, with no intentional vehicle-control traffic? | A written CAN non-interference requirement includes startup, programming, faults and firmware recovery. | CLOSED BY ORIGINAL SCOPE | RVB22 coordinated engineering review | I20 native source and matched outputs have been verified. The original evidence scope below remains controlling. Original criterion disposition remains closed. The prior detailed assessment is retained in previous_I06_disposition and the historical register; current evidence and remaining conditions govern this row. CRITERION: CLOSED DESKTOP: CURRENT EVIDENCE REVIEWED REMAINING: | lanes/firmware_oil/RECOVERED_RELEASE_CHECKS.json lanes/firmware_oil/RECOVERED_FIRMWARE_TEST_RESULTS.json lanes/firmware_oil/FINAL_I04_OIL_FIRMWARE_EFFECTIVITY.json current/EXECUTION_PLAN.md current/I22_SOURCE_VERIFICATION.json | Rev B; characterize Rev A only within its approved bench limits | R2 |  | CLOSED
REQ-02 | Requirements and interfaces | P0 | G0 Definition | Which GR86/BRZ generation, model years, tap point and network are supported? | Verified vehicle interface documentation, harness pinout and observed network characteristics; no OBD or wire-color assumptions. | CURRENT SOURCE OR MODEL WITH REMAINING CONDITIONS | RVB22 coordinated engineering review | I20 native source and matched outputs have been verified. The original evidence scope below remains controlling. Original criterion disposition remains open. The prior detailed assessment is retained in previous_I06_disposition and the historical register; current evidence and remaining conditions govern this row. CRITERION: OPEN DESKTOP: HARDWARE OR INSTALLATION ACCEPTANCE REMAINING: actual vehicle takeoff/returns and observed network remain installation evidence. | interfaces/asc_profile/ASC_PROFILE_REVIEW.json interfaces/asc_profile/PRIMARY_SOURCE_MANIFEST.json current/EXECUTION_PLAN.md current/I22_SOURCE_VERIFICATION.json | Rev B; characterize Rev A only within its approved bench limits | R2 |  | OPEN
REQ-03 | Requirements and interfaces | P1 | G0 Definition | Are CAN rate, identifier formats, signal set and maximum sustained and burst loads defined? | Interface specification distinguishes required Classical CAN support from any future CAN FD capability. | CLOSED BY ORIGINAL SCOPE | RVB22 coordinated engineering review | I20 native source and matched outputs have been verified. The original evidence scope below remains controlling. Original criterion disposition remains closed. The prior detailed assessment is retained in previous_I06_disposition and the historical register; current evidence and remaining conditions govern this row. CRITERION: CLOSED DESKTOP: CURRENT EVIDENCE REVIEWED REMAINING: | lanes/firmware_oil/RECOVERED_RELEASE_CHECKS.json lanes/firmware_oil/RECOVERED_FIRMWARE_TEST_RESULTS.json lanes/firmware_oil/FINAL_I04_OIL_FIRMWARE_EFFECTIVITY.json current/EXECUTION_PLAN.md current/I22_SOURCE_VERIFICATION.json | Rev B; characterize Rev A only within its approved bench limits | R2 |  | CLOSED
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

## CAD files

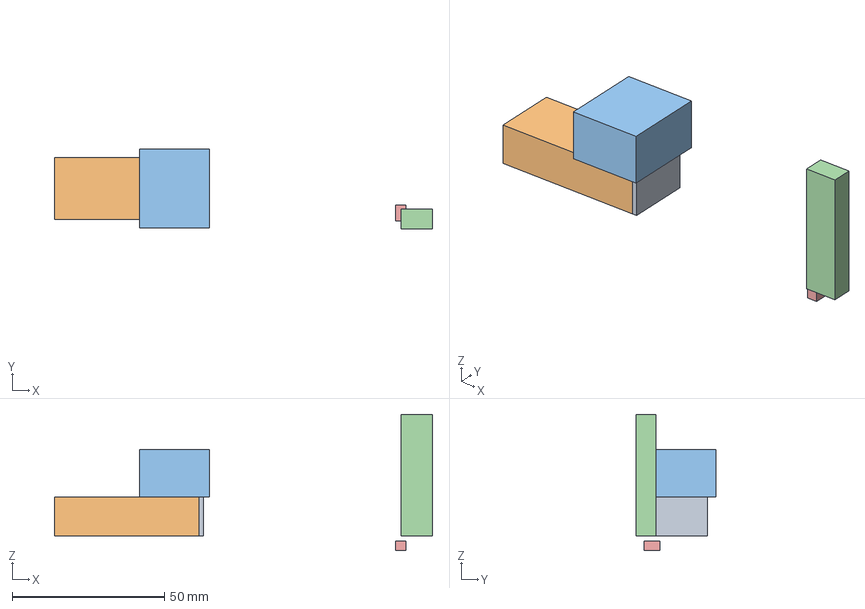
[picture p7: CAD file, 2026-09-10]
docs/engineering/rvb22/analyses/mated_i22/MATED_SERVICE_ENVELOPES.step
124.2 x 26.3 x 44.9 mm

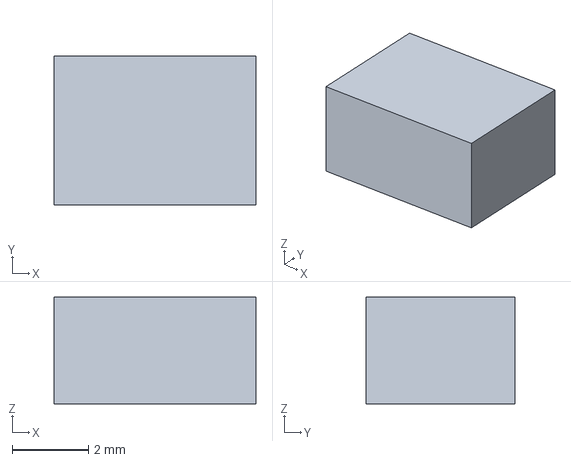
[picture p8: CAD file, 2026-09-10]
docs/engineering/rvb22/candidate/cad/models/ENVELOPE_KEMET_C1210_10u50V.step
5.30 x 3.90 x 2.80 mm

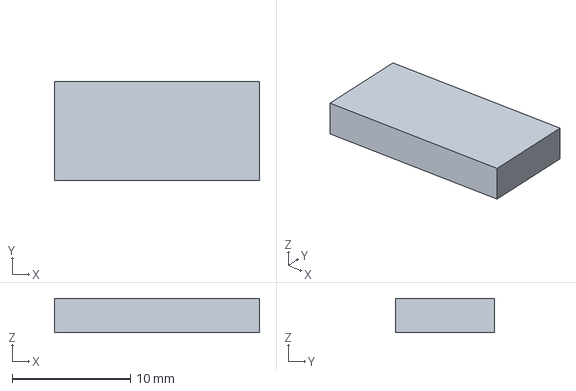
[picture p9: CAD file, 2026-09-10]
docs/engineering/rvb22/candidate/cad/models/ENVELOPE_Fuse_Littelfuse-NANO2-885.step
17.3 x 8.36 x 2.90 mm

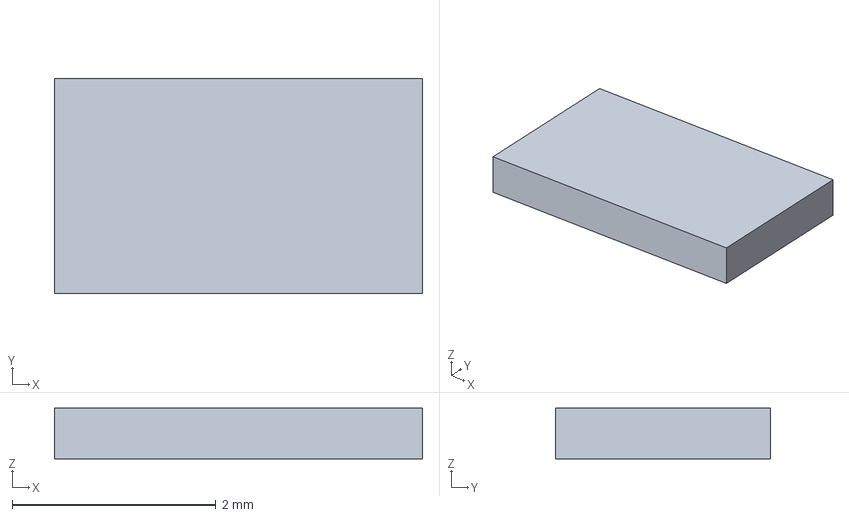
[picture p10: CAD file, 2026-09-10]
docs/engineering/rvb22/candidate/cad/models/ENVELOPE_R_0603_1608Metric_RVB22_R203.step
3.61 x 2.11 x 0.5 mm

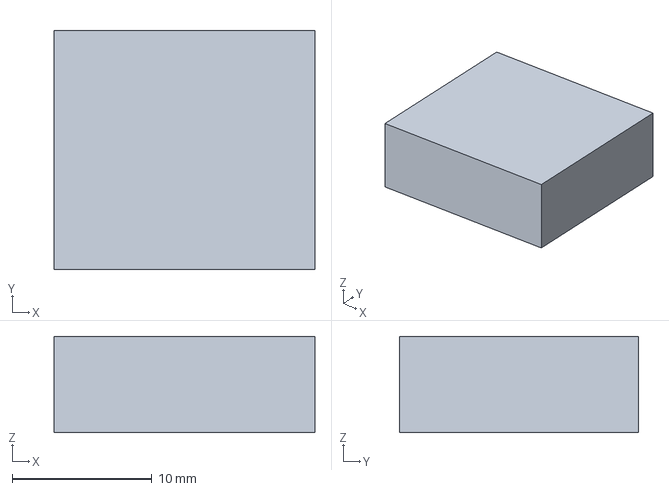
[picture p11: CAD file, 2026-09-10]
docs/engineering/rvb22/candidate/cad/models/ENVELOPE_CDTop_PA1616D_20Pad_v06.step
18.7 x 17.1 x 6.90 mm

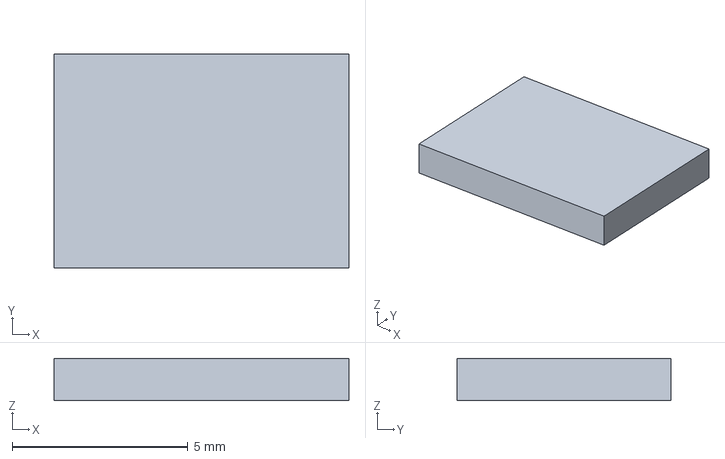
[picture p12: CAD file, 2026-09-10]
docs/engineering/rvb22/candidate/cad/models/ENVELOPE_HTSSOP-16-1EP_4.4x5mm_P0.65mm_EP3.4x5mm_Mask2.46x2.31mm_RVB22_U151.step
8.40 x 6.10 x 1.20 mm

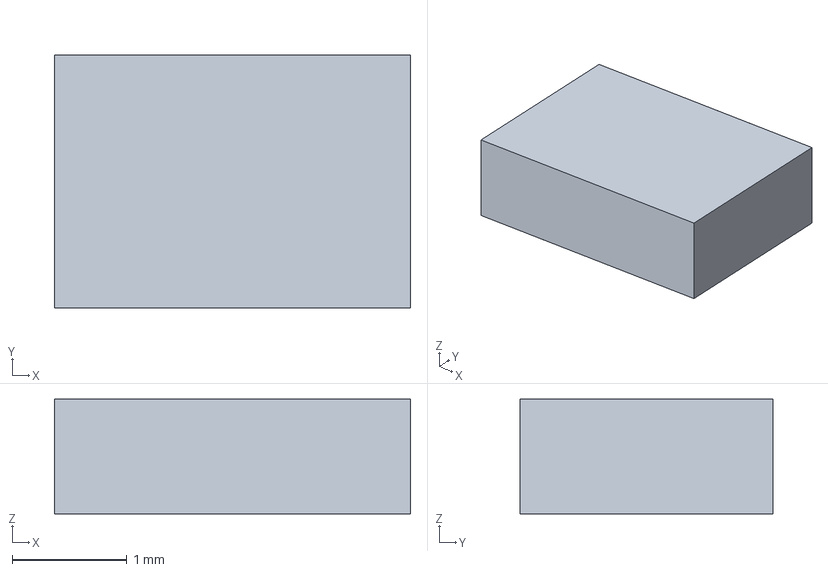
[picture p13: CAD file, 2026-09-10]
docs/engineering/rvb22/candidate/cad/models/ENVELOPE_Murata_LQW18AS_1608.step
3.10 x 2.20 x 1.00 mm

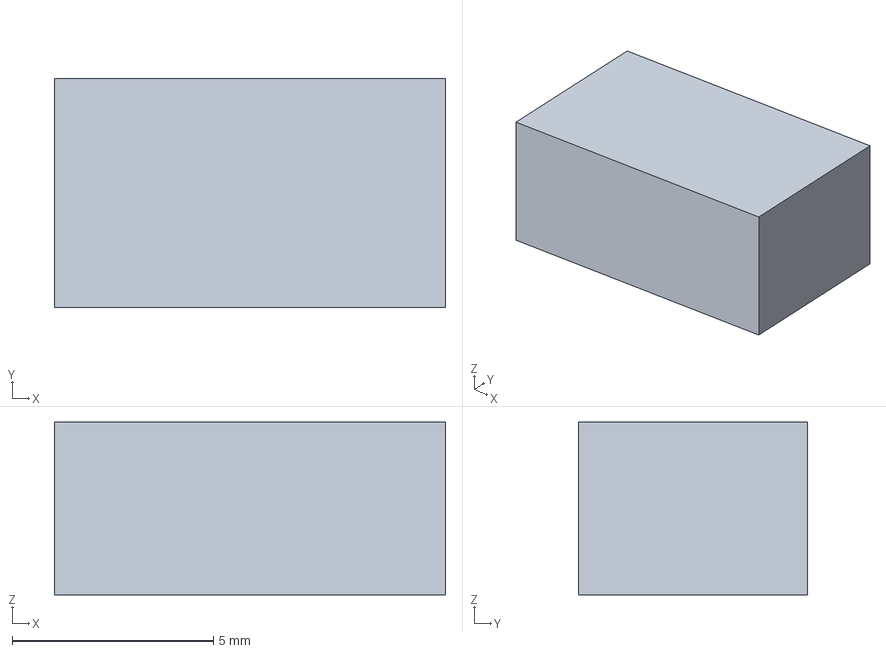
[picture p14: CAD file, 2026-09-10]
docs/engineering/rvb22/candidate/cad/models/ENVELOPE_KEMET_T598_X_7343_Median_RVB22_C206.step
9.72 x 5.70 x 4.30 mm

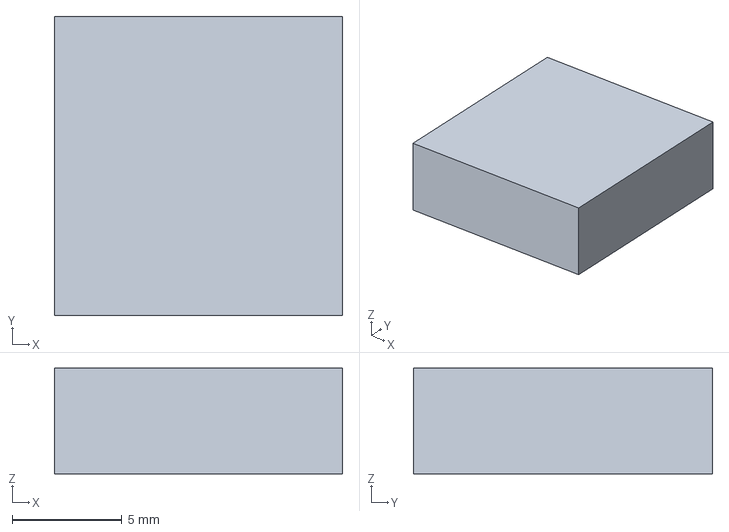
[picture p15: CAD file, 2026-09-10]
docs/engineering/rvb22/candidate/cad/models/ENVELOPE_Coilcraft_MSS1246T_12x12_RVB22_L121.step
13.1 x 13.6 x 4.80 mm

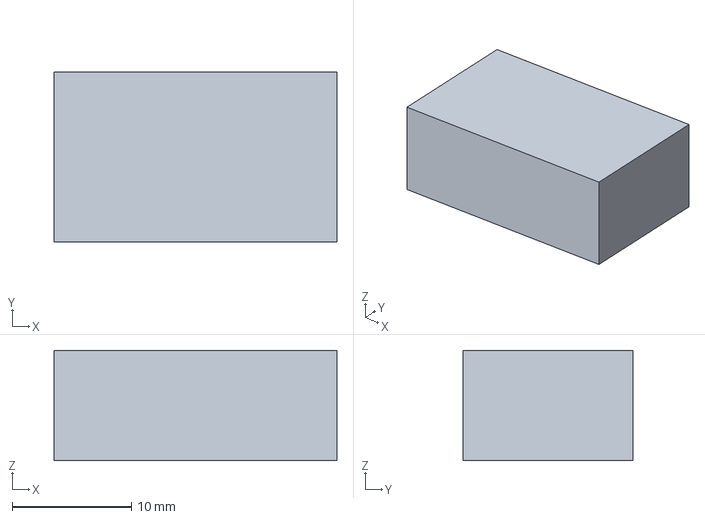
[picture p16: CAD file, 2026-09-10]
docs/engineering/rvb22/candidate/cad/models/ENVELOPE_Molex_Micro-Fit_3.0_43045-1200_2x06_P3.00mm_Horizontal_RVB22_F1.step
23.8 x 14.3 x 9.27 mm

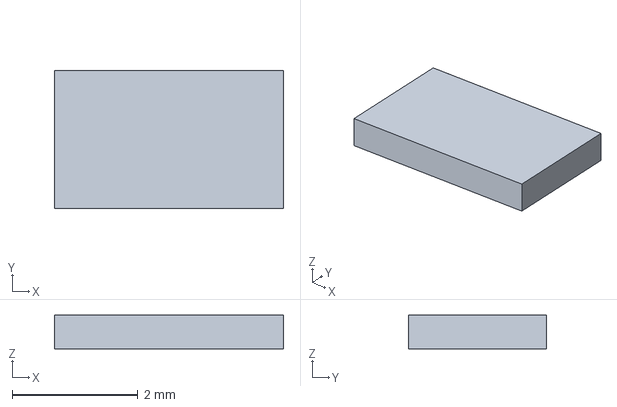
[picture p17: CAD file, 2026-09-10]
docs/engineering/rvb22/candidate/cad/models/ENVELOPE_WSLP0603_MANUFACTURER_R153.step
3.64 x 2.20 x 0.533 mm

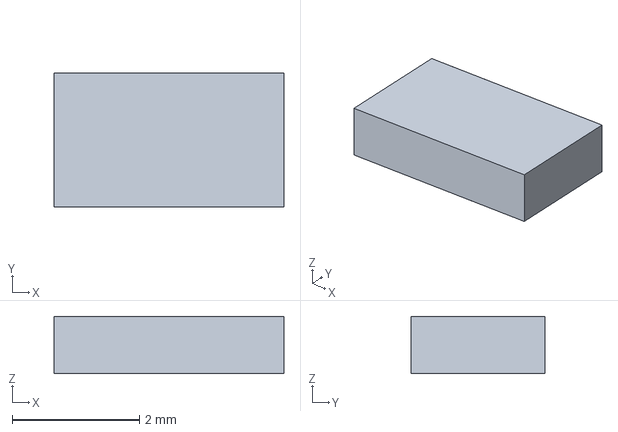
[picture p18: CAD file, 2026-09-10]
docs/engineering/rvb22/candidate/cad/models/ENVELOPE_C_0603_1608Metric_RVB22_C205.step
3.61 x 2.11 x 0.9 mm

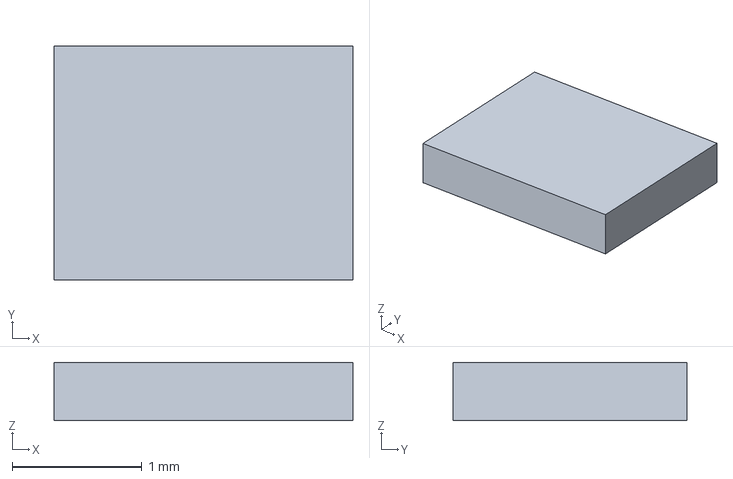
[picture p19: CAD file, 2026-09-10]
docs/engineering/rvb22/candidate/cad/models/ENVELOPE_TI_DPY0002A_TPD1E05U06_SMDMask.step
2.30 x 1.80 x 0.45 mm

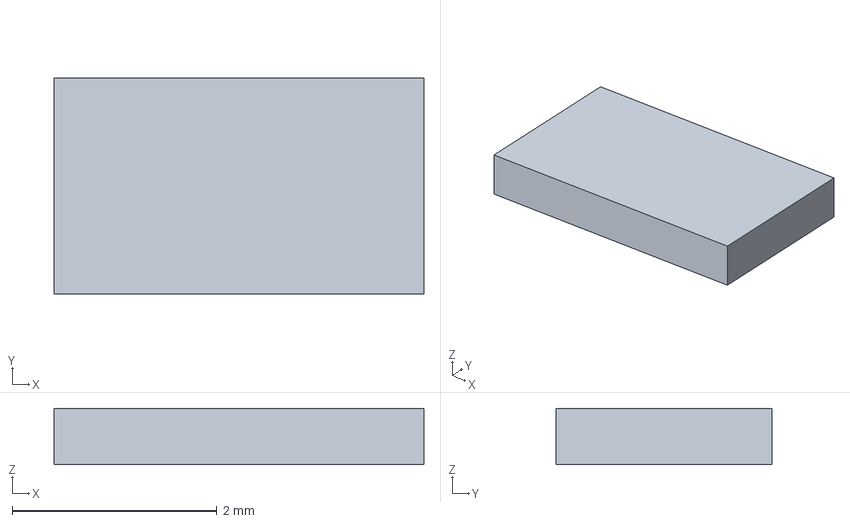
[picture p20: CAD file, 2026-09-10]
docs/engineering/rvb22/candidate/cad/models/ENVELOPE_R_0603_1608Metric_RVB22_R156.step
3.61 x 2.11 x 0.55 mm

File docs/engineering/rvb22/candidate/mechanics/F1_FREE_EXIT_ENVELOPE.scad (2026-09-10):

// Installation template ONLY. Coordinates are local to the actual mated plug wire-exit plane.
// Local +X is the natural wire-exit direction; it is not a PCB or carrier coordinate.
// Transform this template using the actual mating plug before checking dashboard/tool/cable clashes.
// No tie, twist, bend or significant terminal bias is permitted in the first25.4mm.
// Controlled free length25.4..30mm; following bend radius>=30mm; total harness wire path<=300mm.
// This envelope is external to the basic carrier bounding box and does not prove installed fit.
$fn=64;
module f1_relaxed_exit_envelope(length_mm=30,bundle_diameter_mm=6) {
 assert(length_mm>=25.4 && length_mm<=30);
 assert(bundle_diameter_mm>0 && bundle_diameter_mm<=6);
 color([1,.65,0,.25]) rotate([0,90,0]) cylinder(h=length_mm,r=bundle_diameter_mm/2);
}
// Deliberately no fixed installation placement: actual plug exit/axis must be supplied.

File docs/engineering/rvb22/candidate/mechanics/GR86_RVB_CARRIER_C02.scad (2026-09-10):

// Recovered C02. PCB bottomZ0. This is source geometry, not native solid/actual vehicle fit.
$fn=64;
include <MECH_GEOMETRY.scad>
part="assembly";
board_t=1.60;sleeve_t=1.90;base_top=-6;base_bottom=-9;
under_module_clearance=7; //X-case C206 is outside the carrier; no material added here.
module base(){difference(){union(){
 translate([-5,-12,base_bottom])cube([71.5,67,3]);
 for(p=mounts)translate([p[0]-3.5,p[1]-3.5,base_top])cube([7,7,6]);
 translate([-13,-12,base_bottom])cube([8,11,3]);
 translate([-13,42.5,base_bottom])cube([8,12.5,3]);
 }
 translate([13.5,-9.5,base_bottom-1])linear_extrude(5)offset(r=1)translate([1,1])square([39,7]);
 translate([13.5,41.8,base_bottom-1])linear_extrude(5)offset(r=1)translate([1,1])square([39,7]);
 translate([0,2,base_bottom-1])linear_extrude(5)offset(r=2)translate([2,2])square([55.5,33]);
 for(p=mounts)translate([p[0],p[1],base_bottom-1])cylinder(d=2.2,h=12);
 for(p=[[-9,-6],[-9,47.5],[57,-8],[57,50.5]])translate([p[0],p[1],base_bottom-1])cylinder(d=3.4,h=5);
 for(p=[[-2.5,31],[-2.5,37],[63,16],[63,22],[63,30],[63,36]])translate([p[0],p[1],base_bottom-1])linear_extrude(5)hull(){translate([-.75,0])circle(r=.75);translate([.75,0])circle(r=.75);}
}}
module sleeve(p){translate([p[0],p[1],0])difference(){cylinder(d=4,h=sleeve_t);translate([0,0,-1])cylinder(d=2.2,h=sleeve_t+2);}}
module washer(p){translate([p[0],p[1],sleeve_t])difference(){cylinder(d=6,h=.5);translate([0,0,-1])cylinder(d=2.2,h=3);}}
if(part=="base"||part=="assembly")color("ivory")base();
if(part=="hardware"||part=="assembly")for(p=mounts){color("silver")sleeve(p);color("silver")washer(p);}
if(part=="assembly"){
 color([0,.4,.2,.5])difference(){linear_extrude(board_t)polygon(outline);for(p=mounts)translate([p[0],p[1],-1])cylinder(d=4.4,h=4);}
 color([1,.4,0,.1])translate([0,0,board_t])cube([94.454766,41.288863,16]);
 color([1,0,0,.1])translate([68.029766,-1.025,-6])cube([41.25,48.05,25]);
 for(p=mounts)color([.2,.2,1,.1])translate([p[0],p[1],3.9])cylinder(d=6,h=20);
}

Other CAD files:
docs/engineering/rvb22/candidate/cad/models/ENVELOPE_R_0603_1608Metric_RVB22_R157.step
docs/engineering/rvb22/candidate/cad/models/ENVELOPE_TI_PWP0016A_TPS2660.step
docs/engineering/rvb22/candidate/cad/models/ENVELOPE_R_0603_1608Metric_RVB22_R155.step
docs/engineering/rvb22/candidate/cad/models/ENVELOPE_TI_DRB0008J_TCAN3403.step
docs/engineering/rvb22/candidate/mechanics/GR86_RVB_CARRIER_C03.scad
docs/engineering/rvb22/candidate/mechanics/GR86_RVB_CARRIER_C03_THERMAL.scad
docs/engineering/rvb22/candidate/cad/models/ENVELOPE_TI_DDA0008B_4214849B.step
docs/engineering/rvb22/candidate/cad/models/ENVELOPE_TPS3808_DBV0006A.step
docs/engineering/rvb22/candidate/cad/models/ENVELOPE_WSLP0603_MANUFACTURER.step
docs/engineering/rvb22/candidate/mechanics/HARNESS_CORRIDORS_C03.scad
docs/engineering/rvb22/candidate/mechanics/MECH_GEOMETRY.scad
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

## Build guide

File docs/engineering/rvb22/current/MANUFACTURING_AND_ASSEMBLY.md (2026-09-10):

# I22 manufacturing and assembly effectivity

The controlling electrical source is I20, PCB SHA256 `b6c704c0c97685a68ba708d320347148e5136c182c221d86627ff5b319954b3c`. The filled PCB is `62c08e7050fe95df0a576ece85a051b4049e9684bf8ea5f73e8949657363276b`. The current source is in `iterations/I20_controlled_handoff/candidate_kicad`; matching native exports are in `runtime/hosted/run22/extracted/native_I06_hosted`. The legacy folder name in the native artifact does not change its I20 hash identity.

Native run 34420381540 has zero ERC, DRC, warning, unconnected or parity findings. I21 verified all 774 archived outputs and all 101 CAD/32 firmware inputs. I22 separately verifies unchanged source identities and its new engineering evidence; it does not claim a new native build. Independent copper reconstruction agrees with all four copper Gerbers, 338 plated and ten NPTH drills, and the expanded schematic netlist. This is a review candidate. Thermal engineering and supplier/first-article acceptance remain open.

| Item | Current instruction |
|---|---|
| Assembly | 153 fitted references. The 151 automated placement rows match the native board; F101 and U401 are manual exceptions. Keep both in the fitted BOM. |
| Placement datum | X equals PCB X. Placement Y equals 41.288863 mm minus PCB Y. Side and rotation are checked explicitly. |
| Filled/capped vias | 49 total: 48 at U201 exposed pad 41, plus one at R153. Use the I20 source coordinates and the current via-in-pad list. Do not use the historical 13-via list. Fill, cap and planarize for soldering. |
| Plated wall | 15 µm minimum finished wall is a model/construction requirement. An average plating specification does not establish the minimum. No resin conductivity credit is used. |
| PCB outline | 88.254766 × 61.275846 mm overall board bounds, including the C206 tab. ESP32 module overhang and mated harness/service envelopes are additional. |
| C206 | T598X477M006ATE025, F.Cu at (82, −4) mm on the grounded FR4 tab. Preserve clearance, polarity and the new long branch. The tab's 30 g static case passes its declared hot-FR4 bound; this is not a fatigue result. |
| Precision feedback | R155 TNPU060311K8HWEA00, 11.8 kΩ; R156 TNPU06034K99HWEA00, 4.99 kΩ. The current analysis includes 0.02% tolerance, 2 ppm/K and independent 0.1% drift. |
| Bulk damping | R158 WSLP0603R0820FEA, 82 mΩ. Historical 47 mΩ instructions are superseded. |
| F101 process | Littelfuse 0885001.DR. Exclude from the global paste/PnP process. Its recommended 255–260°C process conflicts with the ESP32 module's 235–250°C range; use a qualified local solder process after global reflow. |
| Models | Every fitted reference has a resolved model. Many are conservative manufacturer-height/allocated-XY envelopes; they are not asserted to be detailed supplier solids. |
| Branding | Approved Compact TW artwork, one-color F.SilkS, 8 mm. Current native polygon comparison agrees with the original SVG within the recorded geometric tolerance. |

The controlling carrier is C05 with W02 wing flexures and T03 central flexure, in `iterations/I15_service_mechanics/candidate_mechanics`. Each flex member uses 200 annealed, unbonded C110 laminae, 0.010–0.011 mm each, with bonded terminals only. Total thickness is 2.0–2.2 mm. Do not substitute a solid bonded stack or the older 40-foil construction: their reaction forces differ. Support the cold terminals as specified. Material conductivity, hot strength, friction, retained clamp tension, creep/fatigue and the maximum 220 g carrier mass remain explicit construction conditions.

The C05 support relief and 150 mm coax S-route are required. The selected assembly is now explicitly Adafruit 851 with the Adafruit 960 puck. Use 150 ±3 mm to the SMA shoulder, nominal cable OD 1.8 mm, receiving-envelope maximum OD 2.0 mm, 0.5 mm lateral route uncertainty and 15 mm bend radius. The miniature mated plug allocation is 3.4 ×5.3 ×3.25 mm. Preserve its negative-Y exit and independent carrier restraint. The supplied plug dimensions and retention remain acceptance conditions. The published 851 operating ceiling is 60°C, below the 65°C modeled air case; see `ACCESSORY_REVIEW.md`.

The populated clearance model adds the complete 1.71 mm stack to each maximum component height: 0.25 mm solder, 0.51 mm capture freedom, 0.75 mm warp and 0.20 mm local deflection. This corrects the previous 1.20 mm code allowance. Component XY envelopes include 0.30 mm; flexure geometry includes the full 2.2 mm packet, 0.50 mm lateral bow and 0.30 mm position allowance. Carrier base/support XY adds 0.15 mm. Fastener/landing boxes are included. All 1,154 populated-board and 776 mated checks pass; the smallest modeled separation is 0.120 mm from R408 to the T03 flexure, followed by 0.230 mm at L406. These bounds are construction requirements. Exceeding any of them requires a new clearance check before assembly.

All 12 IC/module top/bottom orientations and 151 numbered signal lands now have independently transcribed manufacturer drawing overlays against native placement output. U401 is a manual placement: PCB centre (54.5, 9.0) mm, F.Cu, rotation 0°; its corresponding placement Y is 32.288863 mm. Pin 1 is at PCB (46.7, 2.25) mm in the top view. The legacy PA1616D footprint suffix `v06` does not identify the revision of the current Adafruit-linked V.05 PDF; I22 verifies geometry and pin numbering directly. Do not infer a manufacturer revision from that library filename.

| Exposed pad | Required net | Current mask/paste interpretation |
|---|---|---|
| U121 pad 9 | GND | Manufacturer mask window; paste is 58.85% of exposed mask area. Four nearby pad vias lie outside the paste apertures. |
| U151 pad 17 | GND | Manufacturer mask window; paste is 63.17% of exposed mask area. Six pad vias lie outside the paste apertures. |
| U201 pad 41 | GND | Nine 0.9 mm mask/paste windows within 3.9 mm buried copper. The 48 affected vias require fill, cap and planarization. |
| U301 pad 9 | GND | Multiple same-net returns, including two vias 0.4 mm outside the pad edge. The drawing does not mandate via-in-pad. |
| U501 pad 17 | OIL_EFUSE_RTN | Preserve the TPS2660 RTN topology. Paste is 61.54% of exposed mask area; it is not an instruction to short RTN to system ground. |

The package audit records compatible alternative lead-land dimensions where KiCad IPC lands differ from the manufacturer's example. These orientation and copper/mask checks do not substitute for stencil/reflow or independent human assembly review. Keep DRW-03 and the process gates open.

The current drill reconciliation contains 338 plated holes and ten NPTH holes: 63 ×0.2 mm and 259 ×0.3 mm vias, 12 ×1.02 mm connector holes, and four ×1.1 mm header holes. Nominal via annular ring is at least 0.15 mm. The 1.6 mm board acceptance interval is 1.44–1.76 mm. JLCPCB's published through-hole tolerance is +0.13/−0.08 mm; a public capability is not acceptance of this exact order, and no unsupported NPTH tolerance is assigned. The maximum nominal finished-hole aspect ratio is 8.8; allowing the full negative diameter tolerance raises that geometric ratio to 14.67. Supplier drill-tool/preplate construction and exact connector/hardware fit remain DFM-02 work. The published average wall does not satisfy a 15 µm minimum-wall requirement.

All 322 vias pass the declared normal-load self-heating screen at 2 A in each individual via, with no sharing credit, 1.76 mm board thickness, 15 µm minimum wall and −0.08 mm finished-hole allowance. Maximum calculated via self-rise is 5.103 K against a 10 K budget. Absolute board/package temperature, fault survival and supplier plating acceptance remain separate requirements.

All 776 declared mated-body checks and 37 probe approaches pass. The probe contract is a 0.30 mm needle, 0.10 mm position allowance and at least 5 mm slender exposed shaft. Remove the carrier for bottom access. The listed nearest ground contacts are suitable for DC access; use differential or short-return probes for fast signals. Keep the connector's latch and programming-tool service volumes clear.

Harness effectivity remains the GR86 ASC mapping per Timurrr and the single full-current F1.1 return. Leave F1.2 unpopulated in the harness. Use switched, fused accessory power and retain the relaxed free exit, strain relief and controlled termination/profile conditions. The named Honeywell sensor is a 150 psi sealed-gauge, 5 V ratiometric device.

Historical fabrication, mechanical and assembly records remain evidence of earlier iterations. This document and the exact I20 manifests govern the current candidate. Any geometry, material, stackup, part, cable, solder process or firmware change requires impact review and regenerated affected evidence.

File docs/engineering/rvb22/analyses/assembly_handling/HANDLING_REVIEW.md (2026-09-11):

# Current-source correction: convergence 01

R155 and R156 are TNPU060311K8HWEA00 and TNPU06034K99HWEA00, not the prior TNPW entries. The canonical JSON/CSV have been rebuilt from the actual fitted PCB inventory: 153 fitted references, 74 exact MPNs. No numeric TNPU MSL or production peak was invented. The immutable prior table is preserved in `../convergence_01/support/HANDLING_I22.json`. This is source/process preparation, not an assembler qualification.

The I04 board has 74 fitted manufacturer part numbers and 153 fitted references. All 74 now have a primary-source handling or process-scope entry. Moisture classification is established for 58 part numbers: 28 have numeric MSL values, and 30 have a manufacturer designation of Not Applicable or unlimited floor life. These are component source findings, not 58 assembly acceptance passes.

The remaining 16 numeric classifications are explicitly identified: eight TDK CGA parts, two Panasonic ERA parts, PMEG2010BEA, the GPS module, U.FL, F1, F101 and the local pin headers. Current TDK and Panasonic documents give storage, soldering and cleaning requirements without a numeric MSL. The live Nexperia API advertises an exact PMEG chemical report, but that report could not be retrieved. The other parts retain their specific local or module handling conditions. None is assigned MSL1 by analogy.

The exact-part TDK page review distinguishes six general-termination parts from two soft-termination parts. The two soft parts contain resin and use the linked soft-termination specification; they are not classified as resinless capacitors. Both specifications support the recorded storage and soldering controls. The downloaded midvoltage-derating document applies to a different product and is excluded from the controlling mapping.

The process records now preserve these distinctions:

- MIC5504's exact Microchip material API gives MSL1. Its datasheet lead-local solder temperature is not a whole-body reflow allowance.
- LTC4367 uses the manufacturer's explicit MS8 MSL1 package table; that table does not supply a numeric body peak.
- STD25NF20's exact linked material declaration specifies MSL1, 260°C classification and three cycles.
- The Murata LQ family is MSL1. L406's exact reference specification recommends 245 ±3°C, limits peak to 260°C for 10 seconds, and permits two reflows.
- Vishay exact resistor quality rows retain their manufacturer nonnumeric classifications. The power-shunt profile uses the restrictive 250°C/20-second prose where its table separately allows 260°C.
- The GPS module requires pre-baking before SMT reflow and second-pass placement for double-sided reflow. Its source does not provide a bake time or temperature; no generic bake is invented.
- U.FL retains its 250°C board-surface limit, cycle count, local solder limit, storage and solderability rules.
- Panasonic ERA storage is 5–35°C and 45–85% RH, with one-year stock control. Its flux and cleaning restrictions are carried separately from solder temperature.
- F1's applicable Molex 43045 application specification allows 260°C wave/reflow and recommends 25.4 mm relaxed wire exit before a tie, bend or twist for a 12-circuit housing. Matched contact plating and independent current-path restrictions require comparison with the harness. Root and mechanics were notified. The source gives no local-wave duration; another connector's duration is not substituted.

The existing 243–245°C global peak allocation is below the retrieved component maximum temperatures. This alone is not a complete compatible oven recipe: dwell definitions, ramp, paste wetting, board temperature spread, moisture exposure, cleaning and local-process acceptance remain to be reconciled by the assembler using a measured profile. Nexperia's recommended 20–30 seconds within 5°C of the peak must not be mechanically treated as the same definition as every component's 10-second peak limit. No physical process result is inferred.

Reproduce with `build_primary_expansion.py`, then `build_handling_register.py --pcb <I04 PCB>`, then `verify_handling_expansion.py`. The final verification passes 105 checks, including exact Vishay row extraction, current R153 MPN, all eight TDK source mappings, retained local routing, source hashes and inventory counts. `HANDLING_SOURCE_MANIFEST.json` binds the controlling artifacts and downloaded sources. Web-only observations are labeled factual observations, never recreated manufacturer PDFs.

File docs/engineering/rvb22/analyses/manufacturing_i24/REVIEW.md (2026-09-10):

# I24 independent manufacturing reconstruction

Final source PCB SHA256: `5b373f6033fdbd18f126f8ca054b619abada2568778c5a8fc303c4e756fb06c8`.

Native filled PCB SHA256: `11533ea91c3bc4c61dd7066e0001914a72bc90b27afb38d321c43b8feb90e3b1`.

The separate Shapely/Gerbonara analysis passes all 133 net connectivity checks across 4,378 copper objects, with no disconnected pad nets or padless islands. All four native copper Gerbers match the PCB's line, flash and region geometry; each zone-union difference is exactly zero at parser precision. All 338 plated and 10 non-plated drill hits match the board geometry within the unchanged 0.00050001 mm export-rounding tolerance.

Independent schematic comparison matches 502 PCB pad identities to 502 schematic nodes in both directions with no missing nodes or net mismatches. All 141 two-terminal components have distinct node identities. Native outputs retain all 14 passing postconditions and zero ERC, DRC, unconnected or schematic-parity findings.

The unchanged critical-signal screen checks 313 outer signal segments. All 12 RF segments retain zero adjacent-plane gaps. Six CAN_TX_MCU adjacent-plane findings remain; the sum of simultaneous both-ground-plane gaps is zero. Detailed per-UUID results are available under `reference.all_checked_segment_results` in `RESULTS.json`; return-path disposition is owned separately under `analyses/return_i24`.

This verifies intended CAD geometry and matched exports. It does not establish fabricated copper, plating, solder, installed harness contacts, or manufacturing release. Reproduction arguments and file hashes are recorded in `EXECUTION.json`.

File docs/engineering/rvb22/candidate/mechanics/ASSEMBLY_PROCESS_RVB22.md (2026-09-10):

# RVB22 assembly and fabrication correction

This source-controlled instruction supersedes RVB21 process steps 6–9 only where explicitly changed below. Receiving, exact-part moisture clocks, cleaning compatibility, inspection and executed traveler records remain applicable. The actual orderable BOM, board hash and regenerated manufacturing files must accompany the job. This is a specified process, not a completed factory traveler.

**F101 remains Littelfuse 0885001.DR, LCSC C2879865, factory fitted quantity one.** Do not substitute a different fuse to resolve soldering. The 885 primary datasheet recommends 255–260°C reflow; ESP32-S3-WROOM-1 permits a 235–250°C whole-board peak, so no common recommended interval exists. RVB22 adopts a later factory local operation instead of claiming the old profile compatible.

1. Bottom SMT first. Top SMT second, with U201 installed only on the second full-board pass. Use a developed profile with component-body peak target 243–245°C, subject to every selected part's full ramp, soak, liquidus duration, cooling and cycle limits. L406 and ESP must remain within their own published limits. A target is not an executed thermocouple record.
2. Omit F101 from both global paste layers and automatic placement/CPL; preserve it in the fitted factory BOM and add it to the secondary operation list. `rebuild_mechanics.py` makes these source edits and provides the matching `RevB:Fuse_Littelfuse-NANO2-885` library footprint so a library update cannot restore the old paste accidentally.
3. After both whole-board passes, factory fit F101 with a masked local mini-wave/selective operation conforming to Littelfuse's published **260°C peak and at most 3 seconds** wave exposure, or a documented manufacturer-supported equivalent. Shield/support the board and verify adjacent components, module, plastics and solder joints stay within cumulative limits. Tool setpoint and hot-air temperature are not component-body temperatures. This instruction does not authorize an arbitrary 350°C iron process. Factory must accept the actual local SMD geometry/process; generic availability of manual assembly does not establish that acceptance.
4. F1/J202/J203 remain factory secondary solder operations under their exact component requirements. U401 remains the sole owner-installed component. No later whole-board oven pass is introduced.
5. F101 MSL1 is supported by the exact 885 datasheet; it is not evidence that the full assembly is MSL1. The new KEMET T598X477M006ATE025 C206 is MSL3, X/7343-43, maximum body 4.3mm. Preserve its actual dry-pack label and cumulative floor-life/bake rules through both passes and any local rework.

## Fabrication correction

Use the authorized four-layer 1.6mm JLC041621-7628 stack, FR4 Tg170, nominal copper 70/30/30/70µm and dielectric 0.203/1.030/0.203mm, ENIG, green LDI mask and white legend. Manufacturing thermal analyses state their minimum-copper assumptions separately; nominal stack values do not guarantee minimum plated copper.

The **12 U201 pad41 vias require filled, capped and planarized via-in-pad fabrication**. The prior drawing note calling for tenting/no-fill is superseded. Preserve the existing nine U201 paste windows; stencil 0.10–0.12mm remains a process choice to be checked with the fine-pitch/large-pad deposits. No F101 global paste is permitted. The updated PCB is 88.254766×61.275846mm; its bounding box fits a120×75mm one-up panel with15.872617mm horizontal and6.862077mm vertical half-margins. Tabs, tooling and fiducials must remain outside four captured ears, the thermal wings and antenna projection. This bounding-box calculation does not itself design or approve panel tabs.

## Source evidence

- `baseline/GR86_CCA_RevB/evidence/manufacturer/littelfuse_885.pdf`, pages2–3: reflow, wave process, package, MSL1.
- `baseline/GR86_CCA_RevB/evidence/manufacturer/espressif_esp32_s3_wroom1.pdf`: module process and mechanical limits.
- `sources/KEM_T2073_T59X.pdf`: exact family orderable X-case, 4.3mm, MSL3 and thermal/ripple scope.
- RVB21 per-MPN process/lifecycle matrix remains a source list, not evidence of completed incoming or reflow acceptance.

## Final I04 via-in-pad addition and R153

The final compact R153 is **Vishay WSLP0603R0100FEA**, maximum body1.774×1.014×0.533mm, with the exact manufacturer1.02mm square lands at±0.76mm centres. It supersedes WSL1206R0100FEA for this reference only. Exact-part process/MSL and BOM source are governed by the final receiving matrix.

The filled-and-capped schedule is now **13 vias total**: the existing12 U201 pad41 vias, plus a thirteenth source-rail via at **X41.4,Y21.0mm**, net **+3V3**, copper diameter0.6mm and drill0.3mm, associated with R153 pad2. This is not a GND via. Record its final UUID from the root rail delta in the manufacturing schedule.

This thirteenth via partly overlaps the R153 copper land. Fill its complete hole, copper-cap it and planarize it with the surrounding land before final finish. Preserve the intended land soldermask/paste opening over the planar cap; a tented via beneath an open pad aperture is not the specified construction. Any annulus outside the pad may remain mask covered. Require no recess, unfilled hole or raised cap that prevents the small resistor from seating or causes solder loss. Native mask/paste and final fabrication DFM must verify the exact land/via registration. The existing12 U201 thermal vias and nine paste windows remain their own unchanged subgroup.

Final I04 R153 centroid isX41.0,Y21.0mm; pad2 centroid isX41.76,Y21.0mm. C157 remainsX36.2,Y22.0mm. The resulting nearest copper-land gap is1.48mm, replacing the rejected0.20mm compact-courtyard trial.

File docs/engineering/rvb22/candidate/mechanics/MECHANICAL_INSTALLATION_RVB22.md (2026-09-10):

# RVB22 C03/T01 installation instruction

This instruction controls the final C03 thermal carrier. Earlier C02/C03 coordinates remain historical in the redline history and comparison models. Use `GR86_RVB_CARRIER_C03_THERMAL.scad`, `MECH_GEOMETRY.scad`, `THERMAL_CONTACT_T01.scad` and `HARNESS_CORRIDORS_C03.scad` together.

## Board capture and structure

Four new outboard ears and4.4mm NPTH holes positively restrain the board inX/Y with shoulder sleeves; washers captureZ. Sleeves are4.00±0.05mm OD,2.2mm ID and1.90±0.05mm long; washer OD≤6mm. PCB thickness1.44–1.76mm gives0.09–0.51mm Z freedom. Do not replace a capture with a friction pad. The1mm total motion/tolerance allocation leaves0.75mm to the nearest original courtyard. The thermal contact has its separately controlled antenna clearance.

All four M3 carrier mounts are required: (−9,−6), (−9,47.5), (57,−11.5), (57,54.5)mm. The3mm insulating FR4 carrier has main boundsX−7..66.5,Y−15..58mm, with left mounting wings extending toX−13. Its central and thermal-wing windows remain open. The right mounting-hole minimum edge ligament is1.65mm; the minimum window ligament is1.35156mm after the stated0.15mm tolerance allocation.

The structural screen uses E≥10GPa, flexural allowable≥150MPa, bearing allowable≥50MPa and local shear allowable≥15MPa as engineering acceptance requirements. These are not invented supplier certificate values. The100g base assembly/20g static case produces97.29MPa worst single-ear bending stress; a126g total including thermal hardware and the≤0.086g added slot reinforcement produces122.58MPa. The rounded126g bound supersedes the125g thermal-hardware screen. The outboard beam and kinematic CTE calculations do not establish vibration modes or solder-fatigue life. The maximum modeled C206 far-edge deflection is0.1601mm within a0.20mm allocation.

## Envelope and service

The final thermal assembly's basic bounding box is**108.454766×73×36.50mm**, including carrier, thermal landing and its fastener allowances. It includes the ESP's6mm PCB-antenna overhang. Actual dashboard cavity, mating plugs, extraction tools, cable bends, antenna exclusion and cooling airspace require additional clearance; no actual vehicle fit is asserted.

Reserve at least7mm clear depth beneath the module region. C206's maximum4.3mm body plus0.25mm solder,0.51mm capture freedom,0.75mm warp and0.20mm local deflection leave0.99mm. C206 lies beyond the carrier's X66.5 edge. Other populated package/lead/solder heights and model-path gaps are enumerated in `FINAL_COMPONENT_ENVELOPES.json`; a full native populated-solid check remains an execution gate.

For U.FL service, disconnect power and F1, release the vehicle mounts and thermal-landing bolts, then remove the carrier captures on the bench while supporting the PCB and cold terminal together. Provide≥20mm tool access below J401 after carrier removal. Do not pull the cable or peel the hot terminal to remove the carrier. Replacing the thermal adhesive requires its controlled preparation and contact acceptance again.

## Harness restraint

Primary F1 harness slots are centred at **X−4,Y31/37mm** in a local8mm spine (X−8..0,Y28..40). Auxiliary coax slots are **X62.5,Y33/39mm** in the retained right insertX58.5..66.5,Y30..42. The old right slotsY16/22 are removed. Nominal slots are **3.9×1.6mm obrounds**, with finished length3.8–4.0mm and height1.5–1.7mm, no burrs,±0.1mm position and±0.1mm carrier-edge allocation. All324 strap-corner/tolerance cases fit the actual64-facet SCAD slot; the former3×1.5mm obround failed despite having sufficient bounding-box width and height. The2mm nominal webs retain1.8mm after tolerances. At30N on one lip and2.85mm minimum carrier thickness, nominal shear demand is5.848MPa; a3×notch sensitivity requires17.544MPa allowable. This local requirement is distinct from the15MPa gross carrier-screen assumption; actual hot/wet notched laminate acceptance remains necessary.

Select **HellermannTyton T18R0HSC2 /111-01905**, with the conservative105°C continuous limit. The maximum strap is2.7mm wide and1.3mm thick; the maximum head requires a5.2×5.2×3.9mm reserved volume. Its catalogue80N tensile strength does not prove installed hot grip.

The primary round bundle must be3–6mm loaded diameter for the evaluated retention case. ReserveX−7.5..−0.5,Y25..42,Z−16.3..−9mm for the6mm maximum bundle plus1.3mm strap. Park the heads beside the bundle atX−12.5..−7.3, centred onY31/37, Z−12.9..−9mm; do not stack a3.7mm head underneath the bundle. Preserve the CAN pair's15–25mm twist and30mm minimum bend radius; the bend sweep needs additional external space. The AVSS CAN jacket must remain within its80°C wire heat-class limit, including heat received from the board.

The independent retention report uses the actual wrap: θ=4atan(D/s), with exit spacing≤7.9mm andµTθ≥10N. For loadedD≥3mm and retainedT=20N, requireµ≥0.3445 and hot loop strength≥60N. The corresponding jacket pressure must also be acceptable; the report provides the inverse table. These are controlled material/assembly conditions, not measured friction or creep values. A loose outer sleeve that permits individual-wire slip is insufficient. A qualified positive harness shoulder may replace the friction requirement, but none is represented as fitted.

The12-circuit F1 mating harness needs **25.4–30mm of relaxed wire from the actual plug wire-exit plane before the first bend, tie or twist**, then the≥30mm minimum bend radius. The first carrier anchor must lie after that free section along the installed wire path. Exact plug-exit coordinates and the external loop remain installation inputs; the basic assembly box and carrier coordinates do not prove this free-exit fit. `F1_FREE_EXIT_ENVELOPE.scad` is a local-coordinate template requiring an installation transform. Keep terminals free to float and unstrained. [Molex430450001-AS,pp2–3](https://www.molex.com/content/dam/molex/molex-dot-com/products/automated/en-us/applicationspecificationspdf/430/43045/430450001-AS-000.pdf)

At the right anchors, retain≤2.8mm jacket/strap build with localized3.9mm head volumes. The right path is for the U.FL service loop; external coax pull is carried by the captured insulating SMA bulkhead. Any accessory cable routed near the approximately90°C thermal spine must have an applicable temperature rating; the tie rating does not supply the cable's rating. Exact Adafruit adapter applicability remains controlled by the interface report.

## Thermal and RF conditions

T01 contacts the board underside atX66.6..72,Y11.8..28.8mm through insulating3M8805 and soldermask. Its specified tape/mask/40-foil packet/landing conditions budget9.967K/W, modeled as10K/W to a landing≤70°C. The actual antenna startsX88.254766; after0.3mm positioning and0.5mm foil-bow allocation, metal clearance is15.454766mm. This is a documented revision of the old broader external-metal exclusion. No direct shield-can contact or galvanic PCB-to-chassis bond is introduced.

The controlling environment is a dashboard installation with65°C local bulk-air/radiant screen. The user's120°F estimate is not a hotsoak measurement. No engine-compartment exposure is assumed. The full-load thermal sensitivities retain the failing low-conductivity cases. Actual native copper/interlayer/package heat flow must meet the T01 inverse requirements before claiming full-load thermal safety. The local ESP ambient limit, capacitor hot-ripple conditions and installed cable temperature limits remain applicable.

Keep water paths away from the open electronics and preserve the windows, antenna clearance and removable service architecture. The separate SMA and puck isolators prevent exposed coax metal from becoming an unintended chassis return. Do not isolate the Honeywell threaded housing from its required ground. Exact puck shape, rigid capture features, cable exit and vehicle cavity remain applicability conditions.

The current primary height coverage is **153 of153 fitted references**, combining16 earlier bounds with137 newly sourced bounds across67 exact MPNs. Use `../../analyses/assembly_handling/PRIMARY_BODY_HEIGHT_ADDENDUM.json` and the supersession metadata in `FINAL_COMPONENT_ENVELOPES.json`. The original140 missing-height physical-reference list is historical; it included three nonfitted references. The final targeted primary lookups bound the last four fitted references: D1041.2mm, F1 including latch9.27mm, J4011.45mm and U2021.45mm. Only three nonfitted references retain unbound heights in the raw physical inventory. The original position/courtyard table and raw height fields are preserved at `history_before_height_addendum/FINAL_COMPONENT_ENVELOPES.json`; the addendum controls current height evidence.

The gross front reserve is16mm above the PCB top, as modeled by `translate([0,0,board_t])cube([94.454766,41.288863,16])` in the C03 carrier source. Newly sourced maxima include U401 overall6.9mm, L1214.8mm and J202/J2038.94mm above the component seating underside, with solder/stand-off still treated separately. The7mm reserve specified earlier is for the underside module/C206 region. These height bounds do not close mating, lead, cable, service, board motion or native populated-solid collisions;18 missing model references remain. If the placement inventory is regenerated, run `python apply_height_supersession.py` afterward to reapply the controlled addendum without losing its distinctions.

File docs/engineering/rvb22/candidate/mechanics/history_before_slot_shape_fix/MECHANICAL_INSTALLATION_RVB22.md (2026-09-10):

# RVB22 C03/T01 installation instruction

This instruction controls the final C03 thermal carrier. Earlier C02/C03 coordinates remain historical in the redline history and comparison models. Use `GR86_RVB_CARRIER_C03_THERMAL.scad`, `MECH_GEOMETRY.scad`, `THERMAL_CONTACT_T01.scad` and `HARNESS_CORRIDORS_C03.scad` together.

## Board capture and structure

Four new outboard ears and4.4mm NPTH holes positively restrain the board inX/Y with shoulder sleeves; washers captureZ. Sleeves are4.00±0.05mm OD,2.2mm ID and1.90±0.05mm long; washer OD≤6mm. PCB thickness1.44–1.76mm gives0.09–0.51mm Z freedom. Do not replace a capture with a friction pad. The1mm total motion/tolerance allocation leaves0.75mm to the nearest original courtyard. The thermal contact has its separately controlled antenna clearance.

All four M3 carrier mounts are required: (−9,−6), (−9,47.5), (57,−11.5), (57,54.5)mm. The3mm insulating FR4 carrier has main boundsX−7..66.5,Y−15..58mm, with left mounting wings extending toX−13. Its central and thermal-wing windows remain open. The right mounting-hole minimum edge ligament is1.65mm; the minimum window ligament is1.35156mm after the stated0.15mm tolerance allocation.

The structural screen uses E≥10GPa, flexural allowable≥150MPa, bearing allowable≥50MPa and local shear allowable≥15MPa as engineering acceptance requirements. These are not invented supplier certificate values. The100g base assembly/20g static case produces97.29MPa worst single-ear bending stress; a125g total including thermal hardware produces121.61MPa. The outboard beam and kinematic CTE calculations do not establish vibration modes or solder-fatigue life. The maximum modeled C206 far-edge deflection is0.1601mm within a0.20mm allocation.

## Envelope and service

The final thermal assembly's basic bounding box is**108.454766×73×36.50mm**, including carrier, thermal landing and its fastener allowances. It includes the ESP's6mm PCB-antenna overhang. Actual dashboard cavity, mating plugs, extraction tools, cable bends, antenna exclusion and cooling airspace require additional clearance; no actual vehicle fit is asserted.

Reserve at least7mm clear depth beneath the module region. C206's maximum4.3mm body plus0.25mm solder,0.51mm capture freedom,0.75mm warp and0.20mm local deflection leave0.99mm. C206 lies beyond the carrier's X66.5 edge. Other populated package/lead/solder heights and model-path gaps are enumerated in `FINAL_COMPONENT_ENVELOPES.json`; a full native populated-solid check remains an execution gate.

For U.FL service, disconnect power and F1, release the vehicle mounts and thermal-landing bolts, then remove the carrier captures on the bench while supporting the PCB and cold terminal together. Provide≥20mm tool access below J401 after carrier removal. Do not pull the cable or peel the hot terminal to remove the carrier. Replacing the thermal adhesive requires its controlled preparation and contact acceptance again.

## Harness restraint

Primary F1 harness slots are centred at **X−3.5,Y31/37mm** in the widened7mm left spine. Auxiliary coax service slots are **X63,Y33/39mm**. The old right slots atY16/22 are removed to clear the thermal packet. Nominal slots are3×1.5mm rounded: require finished width2.9–3.1mm, height1.4–1.6mm and no burrs. The primary slots retain at least1.95mm side webs. At an allocated30N local lip load, nominal shear is5.128MPa in a3mm×1.95mm web.

Select **HellermannTyton T18R0HSC2 /111-01905**, with the conservative105°C continuous limit. The maximum strap is2.7mm wide and1.3mm thick; the maximum head requires a5.2×5.2×3.9mm reserved volume. Its catalogue80N tensile strength does not prove installed hot grip.

The primary round bundle must be3–6mm loaded diameter for the evaluated retention case. ReserveX−7..0,Y25..42,Z−16.3..−9mm for the6mm maximum bundle plus1.3mm strap. Park the heads beside the bundle atX−12..−6.8, centred onY31/37, Z−12.9..−9mm; do not stack a3.7mm head underneath the bundle. Preserve the CAN pair's15–25mm twist and30mm minimum bend radius; the bend sweep needs additional external space. The AVSS CAN jacket must remain within its80°C wire heat-class limit, including heat received from the board.

The independent retention report uses the actual wrap: θ=4atan(D/s), with exit spacing≤7.6mm andµTθ≥10N. For loadedD≥3mm and retainedT=20N, requireµ≥0.333 and hot loop strength≥60N. The corresponding jacket pressure must also be acceptable; the report provides the inverse table. These are controlled material/assembly conditions, not measured friction or creep values. A loose outer sleeve that permits individual-wire slip is insufficient. A qualified positive harness shoulder may replace the friction requirement, but none is represented as fitted.

At the right anchors, retain≤2.8mm jacket/strap build with localized3.9mm head volumes. The right path is for the U.FL service loop; external coax pull is carried by the captured insulating SMA bulkhead. Any accessory cable routed near the approximately90°C thermal spine must have an applicable temperature rating; the tie rating does not supply the cable's rating. Exact Adafruit adapter applicability remains controlled by the interface report.

## Thermal and RF conditions

T01 contacts the board underside atX66.6..72,Y11.8..28.8mm through insulating3M8805 and soldermask. Its specified tape/mask/40-foil packet/landing conditions budget9.967K/W, modeled as10K/W to a landing≤70°C. The actual antenna startsX88.254766; after0.3mm positioning and0.5mm foil-bow allocation, metal clearance is15.454766mm. This is a documented revision of the old broader external-metal exclusion. No direct shield-can contact or galvanic PCB-to-chassis bond is introduced.

The controlling environment is a dashboard installation with65°C local bulk-air/radiant screen. The user's120°F estimate is not a hotsoak measurement. No engine-compartment exposure is assumed. The full-load thermal sensitivities retain the failing low-conductivity cases. Actual native copper/interlayer/package heat flow must meet the T01 inverse requirements before claiming full-load thermal safety. The local ESP ambient limit, capacitor hot-ripple conditions and installed cable temperature limits remain applicable.

Keep water paths away from the open electronics and preserve the windows, antenna clearance and removable service architecture. The separate SMA and puck isolators prevent exposed coax metal from becoming an unintended chassis return. Do not isolate the Honeywell threaded housing from its required ground. Exact puck shape, rigid capture features, cable exit and vehicle cavity remain applicability conditions.

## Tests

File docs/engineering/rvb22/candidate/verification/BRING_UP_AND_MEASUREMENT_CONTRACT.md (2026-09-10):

# RVB22 bring-up, current limits and measurement contract

Status: controlled engineering procedure for the revised source. This document specifies checks; it does not record hardware results. Native CAD/export and target-build gates remain separate. Source-derived pad coordinates and hashes are in BRINGUP_ACTUAL_NODE_INDEX.json. The annotated schematic text delta must be applied after the power source delta.

| Controlled condition | Bound and measurement location |
|---|---|
| Normal supply | 9.5–16V at board input; 24V is a disconnect/survival condition, not normal regulation |
| Input UV falling | 7.369491–7.709308V at REV_BLOCKED_12V, R102.1 after input diode |
| Input UV rising | 7.669066–8.194934V at the same sense node |
| Input OV trip / recovery | 19.554833–20.450296V / 18.283539–19.644817V at the same sense node;32ms recovery is typical, not a guaranteed maximum |
| Main source rail | Adjustable3.37V nominal; calculated source interval3.297890–3.442858V before distribution drop. R15523.7k/R15610k0.1%,25ppm/K,125K allocation and100nA FB; R15710k selects adjustable operation |
| Main load / distribution | ≤0.75A main allocation. Evaluate actual branched source geometry;0.05Ω distribution is the current model target, not a measured board value. The target implies local DC minimum3.260390V at0.75A |
| Normal main transient | Local rail above3.116050V and below3.6V, without unintended supervisor reset. A3.0V module limit alone is insufficient to establish reset margin |
| Supervisor | Falling threshold3.023950–3.116050V; conservative rising maximum3.193951V; CT-open delay12–28ms. External EN reset does not uniquely identify the cause |
| New local storage | C206 KEMET T598X477M006ATE025,470µF6.3V X-case; minimum210.56µF/maximum806.52µF stacked screen; full main bank maximum945.67µF. Case≤125°C and rail≤3.6V. Rated4.2V category/recommended3.78V at125°C does not relax the IC rail limit |
| Damping branch | R158 Vishay WSLP0603R0820FEA82mΩ1%,75ppm/K;80.57115–83.44115mΩ at125°C screen,0.4W rating at70°C. The capacitor25mΩ ESR is a maximum; do not invent a nonzero ESR minimum. Actual tapped-loop model remains the validation authority |
| Main startup | Final explicit R15882mΩ/L15115µH equivalent model:4,096 finite cases,0 recovery failures/UVLO restarts; maximum EN34.8895ms. Startup5V maximum5.211487V; post-EN5V4.922314–5.139656V. Selected50ns refinement gives post-EN main≥3.222890V. These are controller/source hypotheses, not guaranteed silicon behavior; GPS/oil data remain invalid until device health and settling are established |
| GPS rail | Source tolerance3.201–3.399V; module operating3.0–4.3V and ripple≤50mVpp. Probe at module VCC/GND with a short local loop |
| Sensor excitation | Remote Honeywell B-to-A4.75–5.25V, not merely board OIL_5V-to-GND. Normal6.5±1mA is specified at25°C;15mA hot current is an allocated sensitivity |
| Oil turn-off | U501 OUT-to-RTN≥−0.3V. Conditional source model requires OUT-to-GND≥−0.2V with privateRTN motion≤+0.1V; C532 actual network includes its C504 terminal and In1 shared-copper stitches. Use the final nodal model, not the superseded isolated-branch assumption |

## Staged energization

1. Record PCB/assembly/firmware/harness identities and native/export status. Check fitted parts and polarity, empty reserved F1 cavities, correct fixture face and absence of alternate chassis bonds. Disconnect vehicle and sensor. Open R109 to isolate converters; begin protection-only at a20mA current limit. Sweep normal9.5–16V before limited-energy UV/OV characterization. The calculated protection quiescent budget is below0.491mA at16V;0.6mA is an investigation threshold, not a tested unit acceptance result.
2. Restore R109 and open R128 to isolate the downstream5V load. Begin U121 source-only at12V/100mA. Investigate steady raw current above10mA with the downstream branch disconnected. This allowance includes switching/core/ripple-network losses and is not the IC quiescent-current specification.
3. With U121 isolated by R128, inject5.00V into the downstream5V side, initially0.10A, ceiling0.90A. Never parallel an active external source with an enabled converter. Restore R151 as required; open R153 for U151 source-only operation. Investigate source-only injected5V current above25mA. This is an FPWM diagnostic allocation, not the nonswitching40µA IQ value.
4. Restore the intended main bank. Capture source rail, local rail,5V and EN during startup. Allocate pre-reset main load≤0.20A. Record current-limit entry, recovery and any UVLO/EN restarts. Stop and investigate sustained current limiting, wrong rail, repeated hiccup or no recovery after50ms. The50ms stop is a troubleshooting rule, not a guaranteed startup time.
5. Apply0.05/0.15/0.20A initial loads, then the allocated0.5A step with rise≥1µs while total main load stays≤0.75A. Probe U151 source bank, C206/local ESP rail and EN simultaneously. Compare the recorded waveform with the final finite loop model and its assumed controller response. Preserve adverse longer-response cases; do not turn a short-response simulation into a die guarantee.
6. Add GPS and oil branches separately. R401 is the GPS isolation point. Verify remote sensor excitation, transfer and invalid-data behavior before controlled fault injection. Use only the reviewed limited-energy fixture, never arbitrary battery-to-signal shorts. Capture U501 OUT/GND and OUT/RTN differentially; an oscilloscope ground clip must not bond privateRTN to board GND.
7. Integrate on a12V current-limited bench supply, ordinarily≤0.8A input within the declared thermal envelope. Test CAN on a representative three-node terminated bench with the board in passive receive operation. Confirm GNSS supported operating mode/readback and phone profile. A bench pass does not establish the installed vehicle takeoff or traffic semantics.

## Discharge, partial power and consumption

R1541k bleeds the local main rail. After switch-off observe initially10s, then independently verify TP151, TP203 and C206.1 below0.2V before changing connections. Open R153 creates separate source/local islands; one dead test point does not prove the other island is discharged. GPS-only fixtures need their own1k bleed and voltage check. Before oil calibration, verify TP505 and TP510 below0.2V; use a floating SHDN-to-RTN dry contact and isolated4.75–5.25V stimulus limited to2mA. Do not parallel stimulus and live excitation.

Protection-only current is calculated from U10190µA VIN+110µA VOUT maxima, R111 and threshold-divider low resistance, plus100µA explicit leakage/gate allowance. At16V the result is0.490985mA. Source-only U12110mA raw and U15125mA injected5V are investigation allowances reviewed against switching losses, not guaranteed worst-case silicon numbers. At5V and an80% conversion allocation, main input current is0.129107A at0.15A load,0.172143A at0.20A and0.645536A at0.75A using the maximum main source voltage. Add actual GPS/oil/logic currents separately. Do not compare those loaded values with source-only limits.

## Pin-local loops and instrument loading

| Loop or victim | Pin-local access and purpose |
|---|---|
| U121 input commutation | C123 VIN/GND and U121 VIN/PGND; short loop, identify source impedance and switching current |
| U121 output/COT feedback | L121, output bank and actual ripple-injection R/C network; check feedback ripple and5V recovery together |
| U151 input / internal supply | C152 VIN-to-PGND within manufacturer placement constraint; C153 VCC-localGND; differential C154 BST-to-SW. Do not ground the SW node |
| U151 source and feedback | C155/C156/C157 source-to-localGND, R155/R156 quiet feedback return; compare source and local rail to expose distribution drop |
| ESP local storage | C201/C204, C206 and R158 series branch; local Kelvin voltage and case temperature. C2064.3mm body clearance is mechanical, not a thermal measurement |
| Reset | U202 sense, SUP_RESET_RAW and ESP_EN; record actual threshold/delay and any probe loading. Open-drain service reset only |
| Oil output/return | C532 OUT/GND, U501 OUT/RTN, shared star and remote B/A. Actual same-net overlaps are part of the model topology |
| Analog settling | Op-amp output,220Ω/22nF ADC input and100pF feedback; probe input capacitance/resistance must be included in settling interpretation |
| GNSS | Module VCC/GND and RF supply-noise correlation; local ripple≤50mVpp target. RF connector probes require their calibrated loading model |

Use differential probes where grounds differ; state bandwidth, probe capacitance, offset, DMM uncertainty and current measurement burden. Include uncertainty when comparing to a threshold: no numerical result at the nominal limit is an automatic pass. Schematic/source annotations define current loops and access; measured waveforms, thermal acceptance and supplier assembly records remain separate evidence.

Final startup authority: lanes/power/COUPLED_STARTUP_ENVELOPE.json and C206_CURRENT_THERMAL_ENVELOPE.json. The capacitor post-EN RMS in that startup model is≤0.0194354A; separate actual-tap edge/switching sensitivity reaches0.479947A and17.276mW at75mΩ during its modeled50µs response interval. Startup pulse energy is approximately0.396214mJ in C206 and0.440808mJ in R158; inverse transient thermal conditions and supplier pulse capability remain explicit. Do not equate an interval-average loss with a manufacturer pulse rating.

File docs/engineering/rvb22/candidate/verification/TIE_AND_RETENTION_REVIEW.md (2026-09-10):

# RDA07 cable restraint

Select HellermannTyton **T18R0HSC2 /111-01905**, PA66HS, with a conservative105°C continuous limit. Its80N catalogue minimum tensile strength does not establish hot jacket grip. [Manufacturer](https://www.hellermanntyton.us/products/cable-ties/t18r/111-01905)

MECH22-31 corrects a real fit error: the maximum2.7×1.3mm rectangular strap did not fit the rounded ends of the former3×1.5mm slots. Current nominal slots are3.9×1.6mm, with finished dimensions3.8–4.0×1.5–1.7mm. All324 corner/tolerance cases also fit the actual64-facet SCAD slot. Reserve5.2×5.2×3.9mm head volumes. Primary centers areX−4,Y31/37; auxiliary centersX62.5,Y33/39. Local8mm spines give2mm nominal and1.8mm allocated worst webs after size, position and edge tolerances. At30N on one leg and2.85mm minimum carrier thickness, nominal shear demand is5.848MPa; a3×notch sensitivity requires17.544MPa allowable, not supplied by a bulk flexural rating.

The primary corridor accepts a3–6mm loaded round bundle plus1.3mm strap. For10N axial grip, θ=4atan(D/s) and µTθ≥10N. With exit spacing≤7.9mm, loadedD≥3mm and retainedT=20N, requireµ≥0.3444 and hot loop strength≥60N. These are required properties, not measured friction, creep or tension. Band pressure2T/(wD) reaches5.797MPa atD3mm andw2.3mm; the jacket must tolerate this without damage. Every loaded conductor must be captured; a loose outer sleeve is insufficient. A positively attached shoulder rated20N at service temperature may substitute for friction, but none is claimed present.

F1 is a12-circuit Molex Micro-Fit housing. Reserve≥25.4mm relaxed wire from the actual mated plug wire-exit plane before any bend, tie or twist, then the controlled≥30mm bend radius. This is an external installation envelope, not demonstrated by the carrier anchor coordinates. The actual plug exit and harness path must place the first anchor outside it. Keep the80°C AVSS CAN wire at the left anchor; follow the controlled harness contract for the straight F1 exit,15–25mm twist pitch thereafter and ASC end treatment. [Molex application specification430450001-AS,pp2–3](https://www.molex.com/content/dam/molex/molex-dot-com/products/automated/en-us/applicationspecificationspdf/430/43045/430450001-AS-000.pdf)

External coax pull follows the captured insulated SMA bulkhead into the carrier; U.FL retains only a service loop. A right-side accessory jacket near90°C requires its own applicable rating. The specific acceptance remnant is source-backed jacket friction/pressure and retained hot tension, or an installed10N pull check without individual-wire slip, insulation damage or connector load.

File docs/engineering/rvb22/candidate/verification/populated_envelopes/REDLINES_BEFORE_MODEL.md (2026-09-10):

# Populated envelope analysis scope

The I08 source corrections are under native evaluation. Existing primary evidence covers the maximum height of all 153 fitted references. This analysis may use conservative courtyard/Fab prisms to screen contact/carrier/service clashes where exact native models are missing, but must retain the assumption that the maximum component/lead/solder XY envelope lies within the adopted bound. Nominal KiCad generic models alone do not establish manufacturer tolerances.

Predeclared redlines:

1. Bind the complete fitted inventory, side, source XY and primary maximum height to the current source; exclude DNP and bare test/mount features deliberately.
2. Include mounting float, board-thickness bound, solder/stand-off and carrier/contact volume. Treat a failed conservative bound as a review redline, not necessarily a physical collision.
3. Check both carrier and the folded thermal contact, not only its board contact rectangle. Include mated connector/cable/service volumes separately.
4. Native STEP file existence is not populated coverage. Inventory missing or mismatched model bodies explicitly.
5. Preserve the manufacturer-XY, material/retention and installed-dashboard conditions when an estimate substitutes for measured or supplier geometry.

RVB22-MECH-NATIVE-02: Actual T01 foil polygon extends to X73.1mm; T01 RF specification uses X72mm. With0.3mm placement and0.5mm bow, actual geometric antenna clearance is88.254766-73.1-0.8=14.354766mm, below the15mm allocation. Retain as a design correction requirement; do not waive by using contact extent as packet extent.

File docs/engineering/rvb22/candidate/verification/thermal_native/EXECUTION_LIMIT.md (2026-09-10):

# Native thermal execution status

The retry completed all1.0/0.5/0.25mm results; REFINE­MENT_EXIT.json records return0. The first0.25mm attempt ended without a captured result; that failure is retained in the earlier checkpoint. Completed refinements are energy-balanced but changes increase, so no grid-independent or package-temperature closure is claimed.

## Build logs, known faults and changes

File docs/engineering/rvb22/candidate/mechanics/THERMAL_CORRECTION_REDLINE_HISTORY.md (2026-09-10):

# Thermal iteration redlines recorded before edits

MECH22-23: Wing-only thermal path fails the4.790W continuous allocation under low emissivity/low pressure; thermal contacts through wing necks alone are not sufficient.

MECH22-24: ESP32-S3-WROOM-1-N8R2 85C rating is ambient immediately outside module, not case maximum. Correct the comparison; this does not waive component/junction temperature limits.

MECH22-25: Evaluate a direct, insulated PCB-back thermal contact outside the manufacturer15mm antenna exclusion but inside the previous broader hardware exclusion. Candidate strip X68.3..72.0,Y11.5..28.0; RF review required before adoption. Uniform-sheet model remains a sensitivity, not native copper proof.

MECH22-26: The position model puts all main-rail heat into the U201 exposed-pad footprint and assumes perfect layer coupling. This is an explicit local-deposition sensitivity, not package heat-flow evidence; resolve with bounds or source-verified package model before claiming a temperature pass.

MECH22-27: C02's right chassis holes have only0.65mm to a thermal window. Correct before final carrier: move them to(57,−11.5)/(57,54.5), extend main carrierY−15..58. Record new fit envelope; do not conceal the increase or reuse the old local ligament value.

MECH22-28: Final I03 connector courtyard check found the enlarged thermal strip atY11.0 overlapping J401 by0.294mm². Move the strip toY11.8..28.8 (17mm foil width); constrain coax exit toward−Y and update thermal area/budget/model. This finding came from the final source, not an imagined physical defect.

MECH22-29: Exact heat-stabilized T18R tie has a head up to5×5×3.7mm, exceeding the old2.8mm blanket underside allowance. Allocate local5.2×5.2×3.9mm head volumes and move the thermal-variant right pair fromY30/36 toY33/39 so heads clear the thermal packet. Keep jacket loops within2.8mm; selected tie/installed grip is handled by independent review.

MECH22-30: The independent retained-tension model requires more left-slot web than C03's1mm nominal. Widen the insulating left spine fromX−5..0 toX−7..0 and shift primary slots toX−3.5. With finished slot width≤3.1mm, each minimum web becomes1.95mm. This is a carrier-only pretension-load correction; PCB and overall mounting envelope stay unchanged.

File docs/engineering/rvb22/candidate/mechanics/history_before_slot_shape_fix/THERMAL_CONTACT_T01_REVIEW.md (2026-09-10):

# T01 thermal correction, bound to final I03

**A concrete insulated thermal strap is staged, with a10K/W design budget from PCB-back contact to the mounting landing. Actual-source full-load thermal safety remains unpassed.** The required native copper/interlayer/package calculation is an explicit execution gate. This correction does not quietly assume an isothermal PCB or reduce the allocated load.

## Geometry and construction

The contact isX66.6..72.0,Y11.8..28.8mm, area91.8mm², on the PCB underside. The initial enlargedY11.0 candidate intersected J401's final courtyard; it was rejected and moved before adoption. Final-source courtyard clearance is0.32mm toR408,0.50mm toJ401 and0.50mm toL406. Maintain contact cut/placement error within0.20mm relative to the PCB. These are courtyard bounds; populated connector/cable/solder solids still require native execution.

Use3M8805 nominal0.127mm electrically insulating adhesive film against the existing soldermask. The selected film's published thermal impedance is typical, and applies to its stated test surfaces; it is not a guaranteed installed value. Forty annealedC110 copper laminae, each0.050–0.055mm thick and17mm wide, form an unbonded flexible packet with bonded terminals only. The specified maximum developed heat path is34mm; the drawn centreline is27.824mm. Weld/braze the terminal packets before attaching the film to the assembled board. Do not bond the free foils into a rigid laminated beam.

The formed packet descends outside the carrier's right edge and turns beneath it. `THERMAL_CONTACT_T01.scad` is its volume envelope, not a claim of a manufactured laminated solid. The landing is a2mm aluminium plate atX51..66.5,Y4..35.8,Z−15.327..−13.327mm, withM3 holes at(54,7.5)/(54,32.3). The heads are away from the foil and cable anchors. The bolt/washer/nut allowance increases the basic thermal assembly envelope to**108.454766×73×36.50mm**, before vehicle mating/tool/cable/airspace volumes. All original board captures remain required. The100g base assembly allowance must include the strap or be raised to125g; the125g/20g one-ear flexural screen is121.61MPa versus the declared150MPa material requirement.

`GR86_RVB_CARRIER_C03_THERMAL.scad` removes only the auxiliary right slots atY16/22, which would otherwise route cable ties through the thermal packet. It keeps the primary left pair (finalX−3.5,Y31/37) and moves the right pair toY33/39 to clear the selected tie heads. Jacket loops remain≤2.8mm, with localized5.2×5.2×3.9mm head volumes. Route the U.FL cable away from the strip toward−Y. The final physical bundle may not cross the foil, sharp metal edges or ventilation windows.

The contact does not provide primary PCB retention. Adhesion, peel, hot creep and packet spring force require the actual surface/process specification. 3M's published70°C static and dynamic shear data and heat-aged room-temperature tests do not establish a90°C installed creep guarantee. This material/process acceptance condition is retained rather than inferred from room-temperature tensile strength.

## Finite thermal budget

| Segment | Allocated conditions | Rθ, K/W |
|---|---|---:|
| Existing soldermask | thickness≤30µm, k≥0.2W/mK, full91.8mm² contact |1.634|
| 3M8805 installed film/contact | published typical3.486K/W; installed requirement≤4 |4.000|
| Copper packet | length≤34mm, width17mm, total thickness≥2mm, k≥300W/mK |3.333|
| Bonded terminals and cold landing | combined installed requirement |1.000|
| Total | round up for model |**10.000**|

Film/contact, mask conductivity and cold-landing values are explicit engineering acceptance allocations, not manufacturer maxima. Copper Development Association reportsC11000 approximately391W/mK at20°C; the300W/mK allocation retains substantial margin but is still a specified hot-material minimum. The landing is constrained to≤70°C under load. At65°C surrounding structure, a≤1K/W landing-to-structure path could carry the entire4.815W allocation with≤4.815K rise. Its actual metal/contact geometry must provide that path; a small isolated bracket in65°C air is not assumed to remain70°C.

The original4.790W heat corner mixed minimum5V for conversion current and maximum5V for input power. Power analysis also provides the physically coupled4.5321W case for0.75A main/50mA GPS/7.5mA oil and allocated80% converter efficiencies. This iteration adds25mW magnetic-loss headroom, retaining both4.5571W coupled and4.815W conservative screens. No published average-current number is turned into an enforced firmware limit.

`THERMAL_CONTACT_T01_MODEL.json` evaluates4.815W with actual source-region locations,0.5mm finite-volume mesh,70kPa,65°C bulk air/radiant surroundings,ε0.3,70°C landing and10K/W contact. It sweeps equivalent continuous copper96/120/140/160µm. These values are conductivity sensitivities, **not native filled-copper measurements**. The model idealizes perfect interlayer coupling and deposits all main-rail heat at the U201 exposed-pad region. Unspecified module-to-shield conductance is never credited. The previous models' carrier/shadow geometry remains conservative C02 geometry; no extra C03 carrier area is credited.

A source-position result below125°C at C206 is insufficient alone: add capacitor self-heating and any residual package/interlayer thermal rise. KEMET'sX-case ripple table implies60K/W only under its reference mounting condition; it is not a universal PCB mounting resistance. Above105°C, its31.25mW hot ripple-power limit must be used with the actual hot ESR. The power lane owns that electrical RMS bound.

The manufacturer85°C ESP32-S3-WROOM-1-N8R2 limit refers to ambient immediately outside the module, not shield/case temperature. Installation must maintain the local module-air boundary within its rating; the selected70kPa/65°C bulk-air model is an installation condition, not a measured dashboard result. Current hardware does not expose software control of all CAN/GPS/oil loads, so ESP deep sleep alone cannot be credited as an enforced whole-board thermal limit.

## RF, isolation and service

Actual antenna geometry begins atX88.254766. MetalX≤72 plus0.3mm module/cut/placement and0.5mm permitted flex bow retains**15.454766mm**, meeting the official Espressif≥15mm housing-clearance recommendation. This is a controlled revision of the old broaderX68.029766 external-metal exclusion. It does not prove unchanged antenna match, throughput or range. The strap is chassis bonded at the cold end and electrically insulated from PCB copper; it makes no shield-can contact. Filmεr and trace-to-metal loading remain bounded by the RF lane.

For U.FL service, disconnect power/F1, release the vehicle mounts and thermal-landing bolts, then remove the carrier captures on the bench while supporting the board and cold terminal together. Provide≥20mm free tool access below J401 after carrier removal. Do not peel the hot terminal or pull the cable to remove the carrier. Replacing the adhesive requires its controlled surface preparation and thermal-contact acceptance again.

Primary references: [3M8800-series technical data](https://multimedia.3m.com/mws/media/122119O/3m-thermally-conductive-adhesive-transfer-tapes-8800-series.pdf), [C11000 material data](https://alloys.copper.org/alloy/C11000), [Espressif module placement guidance](https://docs.espressif.com/projects/esp-hardware-design-guidelines/en/latest/esp32s3/pcb-layout-design.html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), [KEMETT59X family data](https://content.kemet.com/datasheets/KEM_T2073_T59X.pdf).

## Executed inverse result

At4.815W, the final strip produces C206-region maxima131.585/124.093/119.702/116.349°C for96/120/140/160µm ideal continuous copper respectively. Thus the first sampled sheet condition leaving at least an allocated3K for capacitor/body rise is140µm, equivalent0.04236W/K per square at the assumed300W/mK copper conductivity. Its remaining2.298K corresponds to only0.885K/W additional local module-path resistance;160µm leaves5.651K or2.177K/W. These tight budgets expose why unmodeled interlayer/package resistance cannot be ignored. No guaranteed temperature pass is declared.

The final left-spine widening to7mm receives no extra cooling credit in the retained thermal models. It only increases the tie-slot load-bearing webs.

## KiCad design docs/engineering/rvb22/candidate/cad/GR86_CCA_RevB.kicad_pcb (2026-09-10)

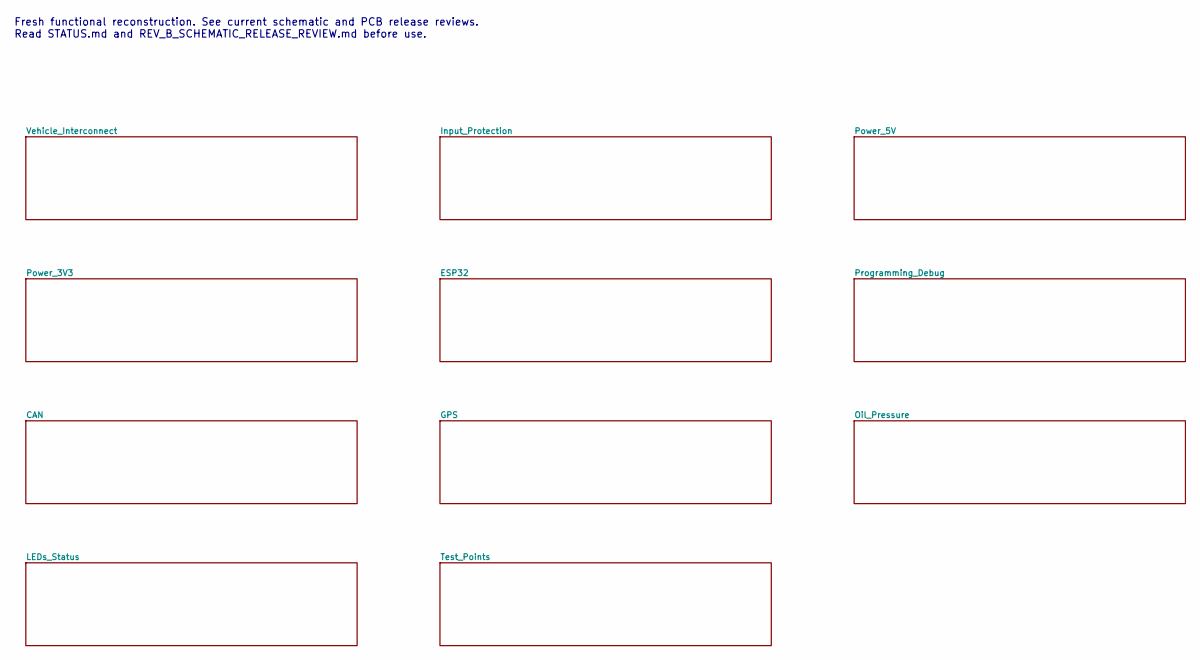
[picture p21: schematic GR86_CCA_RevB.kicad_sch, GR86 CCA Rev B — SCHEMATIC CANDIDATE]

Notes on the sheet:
Fresh functional reconstruction. See current schematic and PCB release reviews. Read STATUS.md and REV_B_SCHEMATIC_RELEASE_REVIEW.md before use.

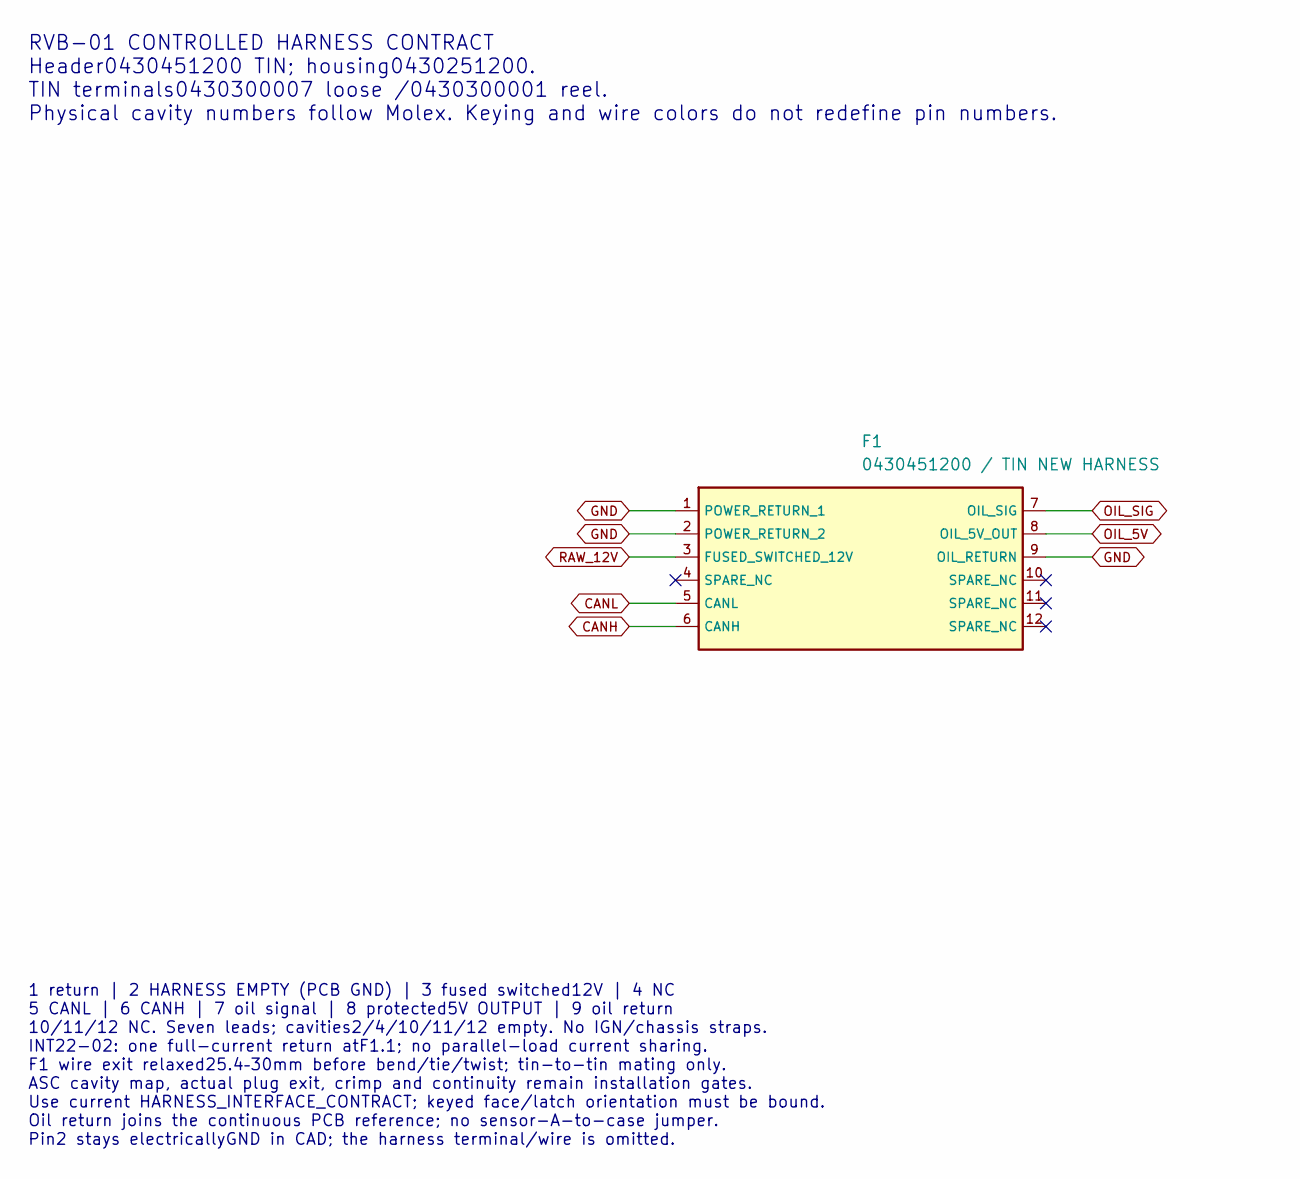
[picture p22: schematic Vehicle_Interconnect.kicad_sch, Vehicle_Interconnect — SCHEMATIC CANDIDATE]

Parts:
F1: 0430451200 / TIN NEW HARNESS; Molex_Micro-Fit_3.0_43045-1200_2x06_P3.00mm_Horizontal_RVB2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; MPN 0430451200; LCSC C277636

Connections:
CANH: F1.6 (CANH); also elsewhere on the board
CANL: F1.5 (CANL); also elsewhere on the board
GND: F1.1 (POWER_RETURN_1), F1.2 (POWER_RETURN_2), F1.9 (OIL_RETURN); also elsewhere on the board
OIL_5V: F1.8 (OIL_5V_OUT); also elsewhere on the board
OIL_SIG: F1.7 (OIL_SIG); also elsewhere on the board
RAW_12V: F1.3 (FUSED_SWITCHED_12V); also elsewhere on the board

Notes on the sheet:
RVB-01 CONTROLLED HARNESS CONTRACT Header0430451200 TIN; housing0430251200. TIN terminals0430300007 loose /0430300001 reel. Physical cavity numbers follow Molex. Keying and wire colors do not redefine pin numbers.
1 return | 2 HARNESS EMPTY (PCB GND) | 3 fused switched12V | 4 NC 5 CANL | 6 CANH | 7 oil signal | 8 protected5V OUTPUT | 9 oil return 10/11/12 NC. Seven leads; cavities2/4/10/11/12 empty. No IGN/chassis straps. INT22-02: one full-current return atF1.1; no parallel-load current sharing. F1 wire exi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

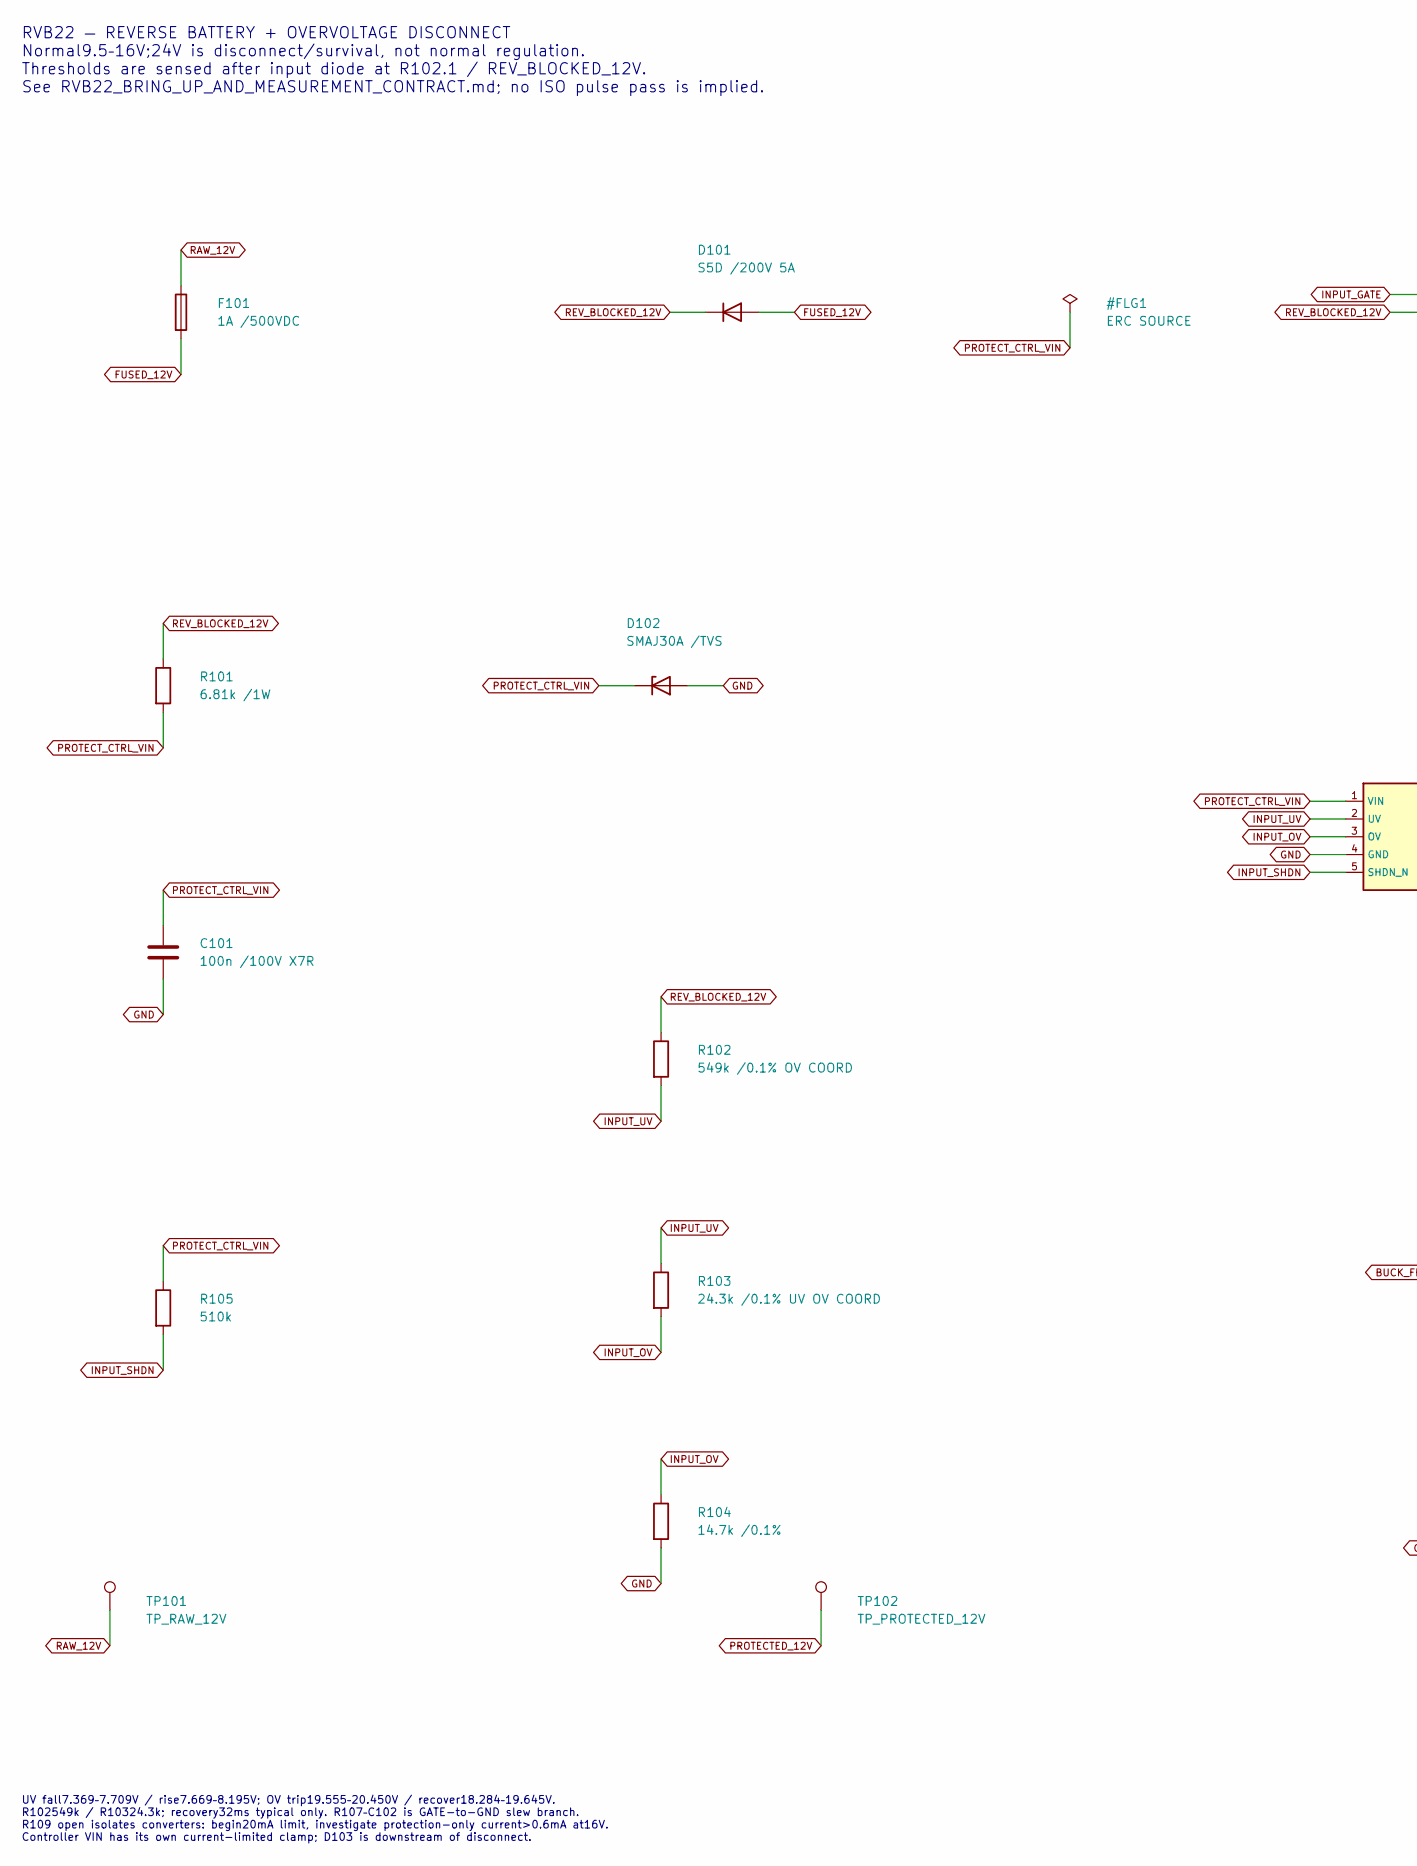
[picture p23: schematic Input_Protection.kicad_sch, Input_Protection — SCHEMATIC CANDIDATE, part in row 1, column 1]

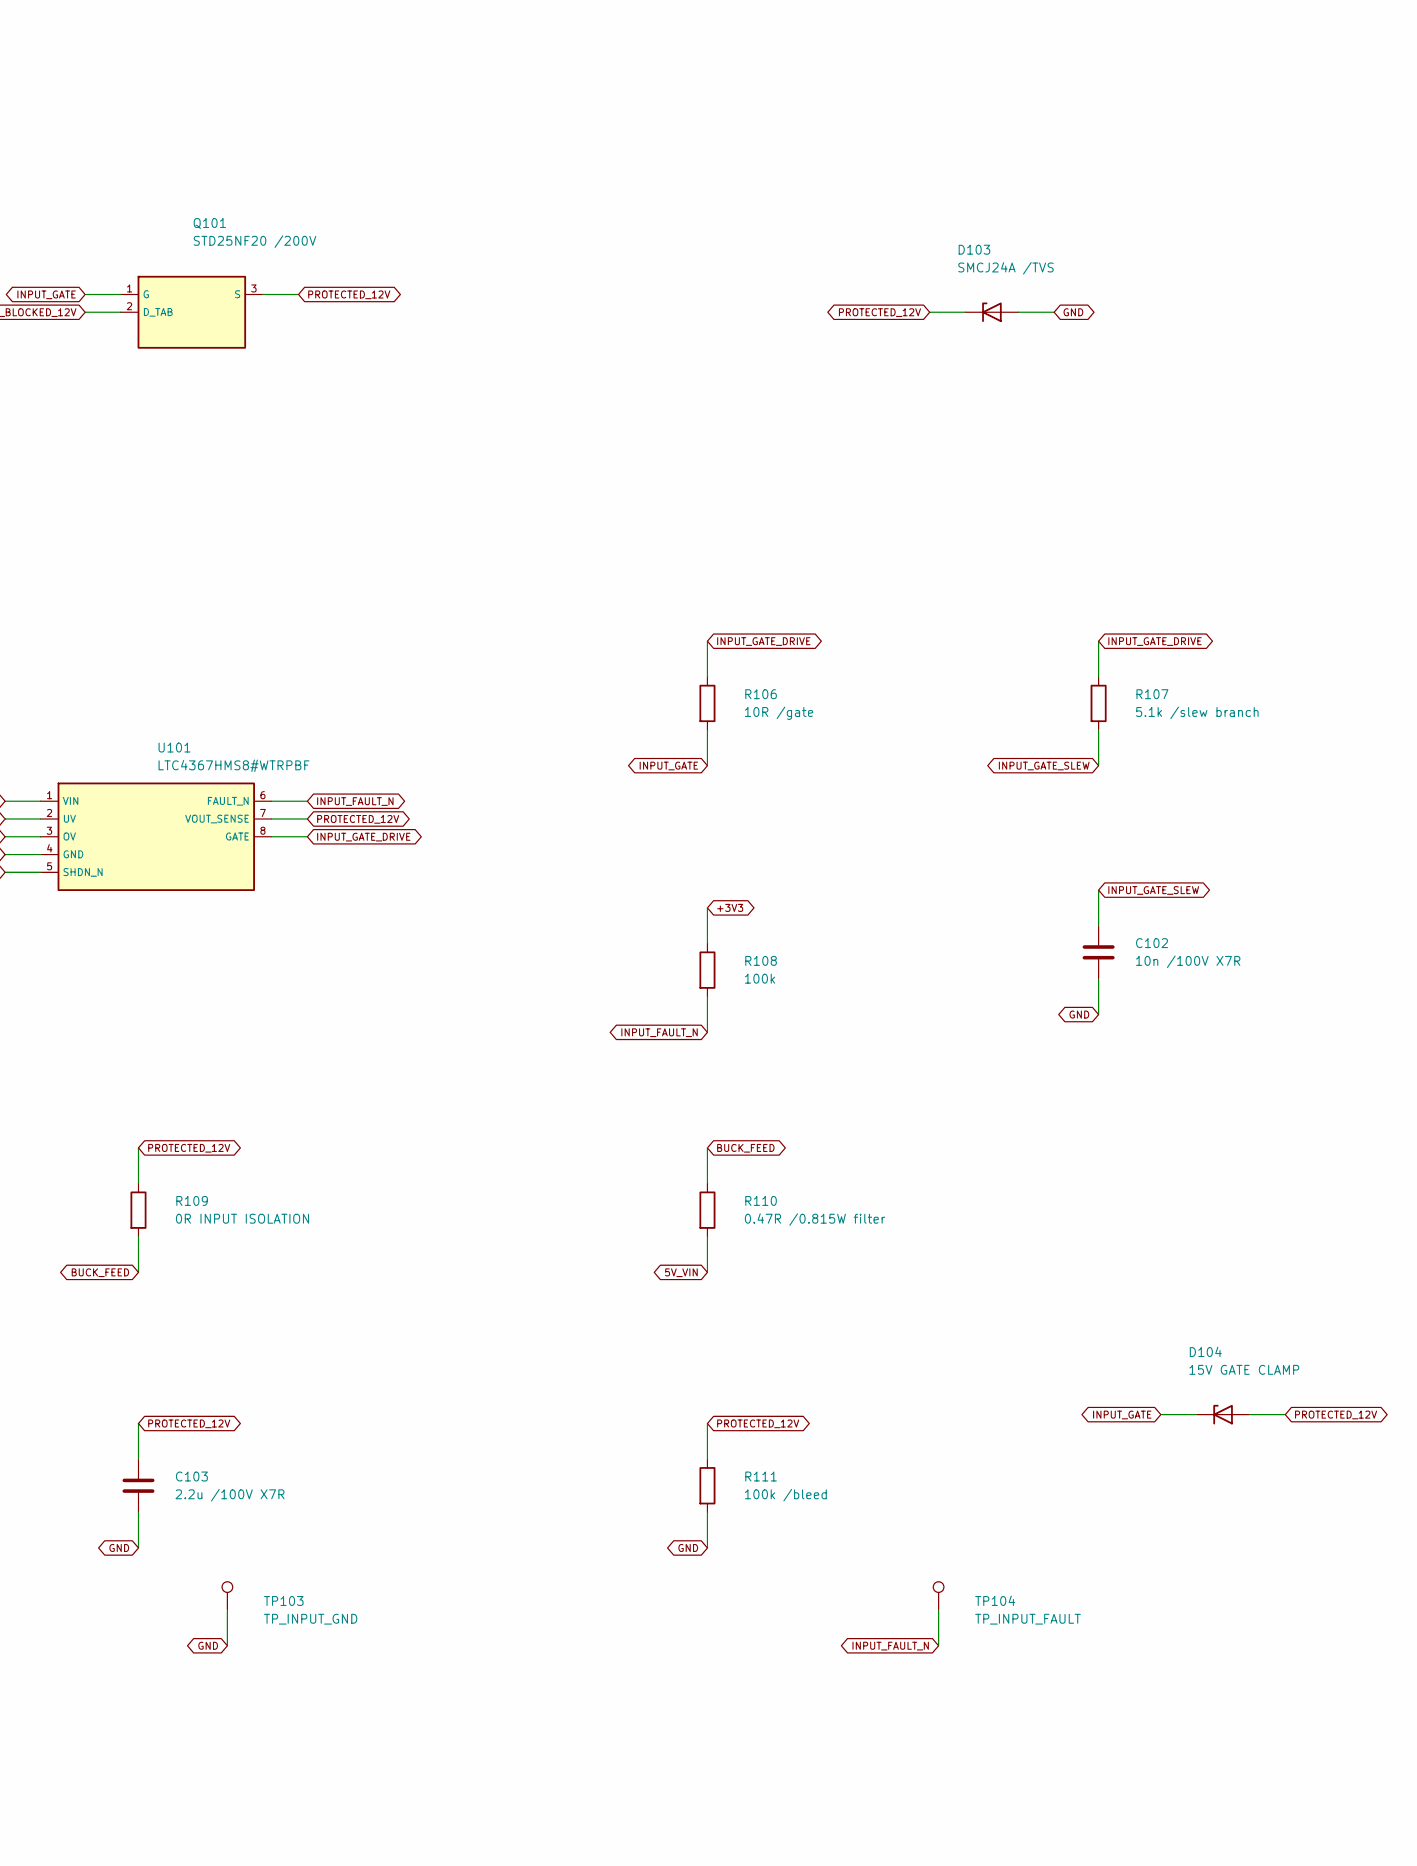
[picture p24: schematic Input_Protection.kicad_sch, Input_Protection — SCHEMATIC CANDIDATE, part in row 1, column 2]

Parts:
C101: 100n /100V X7R; C_0805_2012Metric; MPN CGA4J2X7R2A104K125AA; LCSC C342919
C102: 10n /100V X7R; C_0603_1608Metric; MPN CGA3E2X7R2A103K080AE; LCSC C3858696
C103: 2.2u /100V X7R; C_1210_3225Metric; MPN CGA6N3X7R2A225K230AB; LCSC C342652
D101: S5D /200V 5A; D_SMC; MPN S5DHE3_A/H; LCSC C17442489
D102: SMAJ30A /TVS; D_SMA; MPN SMAJ30AHE3_A/H; LCSC C1978408
D103: SMCJ24A /TVS; D_SMC_RVB22_D103; MPN SMCJ24AHE3_A/H; LCSC C1981952
D104: 15V GATE CLAMP; D_SOD-123F; MPN BZT52H-B15-QX; LCSC C7507926
F101: 1A /500VDC; Fuse_Littelfuse-NANO2-885; MPN 0885001.DR; LCSC C2879865
Q101: STD25NF20 /200V; TO-252-2; MPN STD25NF20; LCSC C388326
R101: 6.81k /1W; R_2512_6332Metric; MPN CRCW25126K81FKEG; LCSC C4207450
R102: 549k /0.1% OV COORD; R_1206_3216Metric; MPN TNPW1206549KBEEA
R103: 24.3k /0.1% UV OV COORD; R_0603_1608Metric; MPN TNPW060324K3BEEA
R104: 14.7k /0.1%; R_0603_1608Metric; MPN ERA3AEB1472V; LCSC C2074591
R105: 510k; R_1206_3216Metric; MPN CRCW1206510KFKEA; LCSC C843859
R106: 10R /gate; R_0603_1608Metric; MPN CRCW060310R0FKEA; LCSC C844919
R107: 5.1k /slew branch; R_0603_1608Metric; MPN CRCW06035K10FKEA; LCSC C844933
R108: 100k; R_0603_1608Metric; MPN CRCW0603100KFKEA; LCSC C844916
R109: 0R INPUT ISOLATION; R_1206_3216Metric; MPN CRCW12060000Z0EA; LCSC C190124
R110: 0.47R /0.815W filter; R_2512_6332Metric; MPN WSL2512R4700FEA; LCSC C4273015
R111: 100k /bleed; R_1206_3216Metric; MPN CRCW1206100KFKEA; LCSC C844863
TP101: TP_RAW_12V; TestPoint_Pad_D1.5mm; MPN BARE PCB PAD
TP102: TP_PROTECTED_12V; TestPoint_Pad_D1.5mm; MPN BARE PCB PAD
TP103: TP_INPUT_GND; TestPoint_Pad_D1.5mm; MPN BARE PCB PAD
TP104: TP_INPUT_FAULT; TestPoint_Pad_D1.5mm; MPN BARE PCB PAD
U101: LTC4367HMS8#WTRPBF; MSOP-8_3x3mm_P0.65mm; MPN LTC4367HMS8#WTRPBF

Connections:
5V_VIN: R110.2; also elsewhere on the board
+3V3: R108.1; also elsewhere on the board
BUCK_FEED: R109.2, R110.1
FUSED_12V: D101.2 (A), F101.2
GND: C101.2, C102.2, C103.2, D102.2 (A), D103.2 (A), R104.2, R111.2, TP103.1, U101.4 (GND); also elsewhere on the board
INPUT_FAULT_N: R108.2, TP104.1, U101.6 (FAULT_N)
INPUT_GATE: D104.1 (K), Q101.1 (G), R106.2
INPUT_GATE_DRIVE: R106.1, R107.1, U101.8 (GATE)
INPUT_GATE_SLEW: C102.1, R107.2
INPUT_OV: R103.2, R104.1, U101.3 (OV)
INPUT_SHDN: R105.2, U101.5 (SHDN_N)
INPUT_UV: R102.2, R103.1, U101.2 (UV)
PROTECTED_12V: C103.1, D103.1 (K), D104.2 (A), Q101.3 (S), R109.1, R111.1, TP102.1, U101.7 (VOUT_SENSE)
PROTECT_CTRL_VIN: C101.1, D102.1 (K), R101.2, R105.1, U101.1 (VIN)
RAW_12V: F101.1, TP101.1; also elsewhere on the board
REV_BLOCKED_12V: D101.1 (K), Q101.2 (D_TAB), R101.1, R102.1

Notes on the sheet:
RVB22 — REVERSE BATTERY + OVERVOLTAGE DISCONNECT Normal9.5–16V;24V is disconnect/survival, not normal regulation. Thresholds are sensed after input diode at R102.1 / REV_BLOCKED_12V. See RVB22_BRING_UP_AND_MEASUREMENT_CONTRACT.md; no ISO pulse pass is implied.
UV fall7.369–7.709V / rise7.669–8.195V; OV trip19.555–20.450V / recover18.284–19.645V. R102549k / R10324.3k; recovery32ms typical only. R107–C102 is GATE-to-GND slew branch. R109 open isolates converters: begin20mA limit, investigate protection-only current>0.6mA at16V. Controller VIN has its own c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

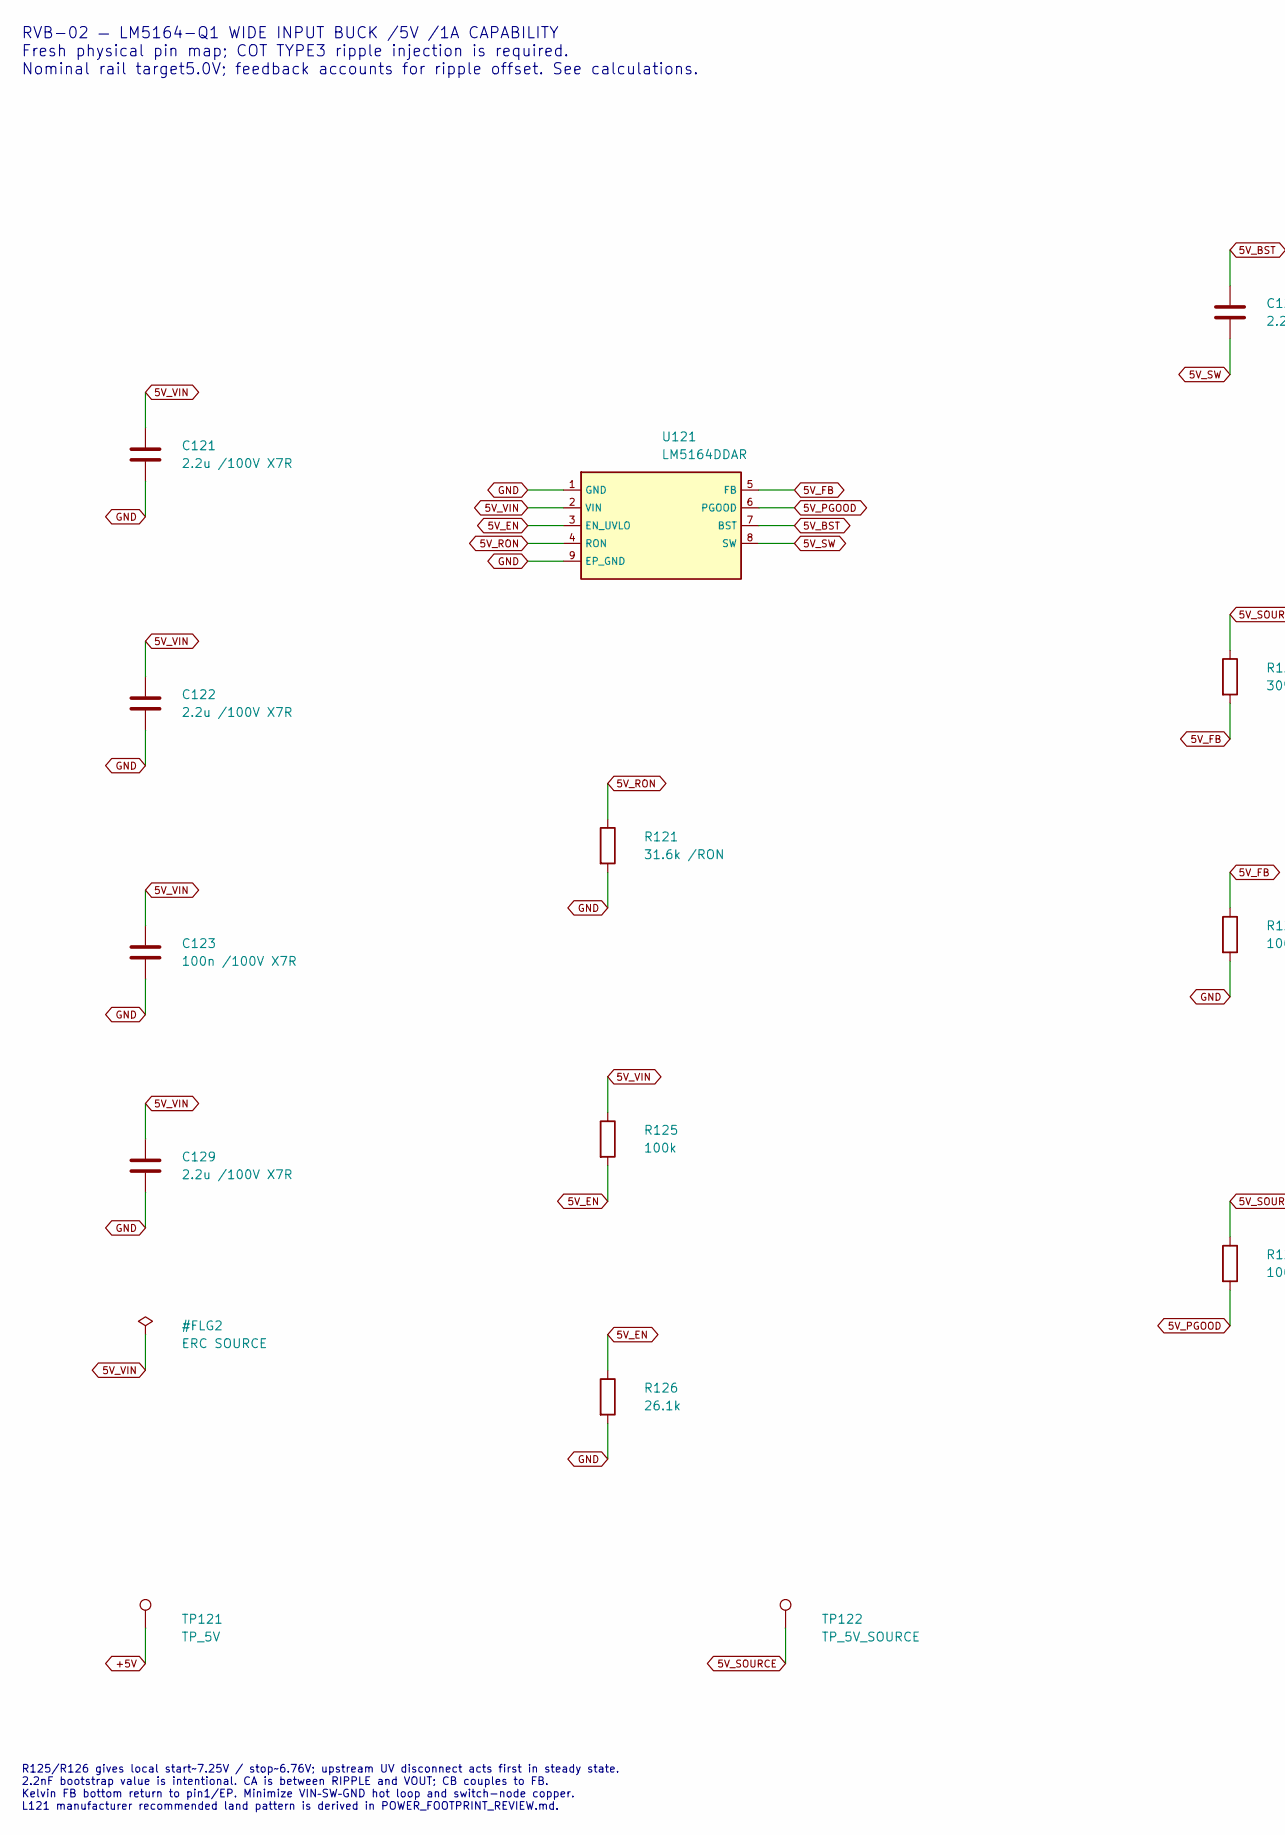
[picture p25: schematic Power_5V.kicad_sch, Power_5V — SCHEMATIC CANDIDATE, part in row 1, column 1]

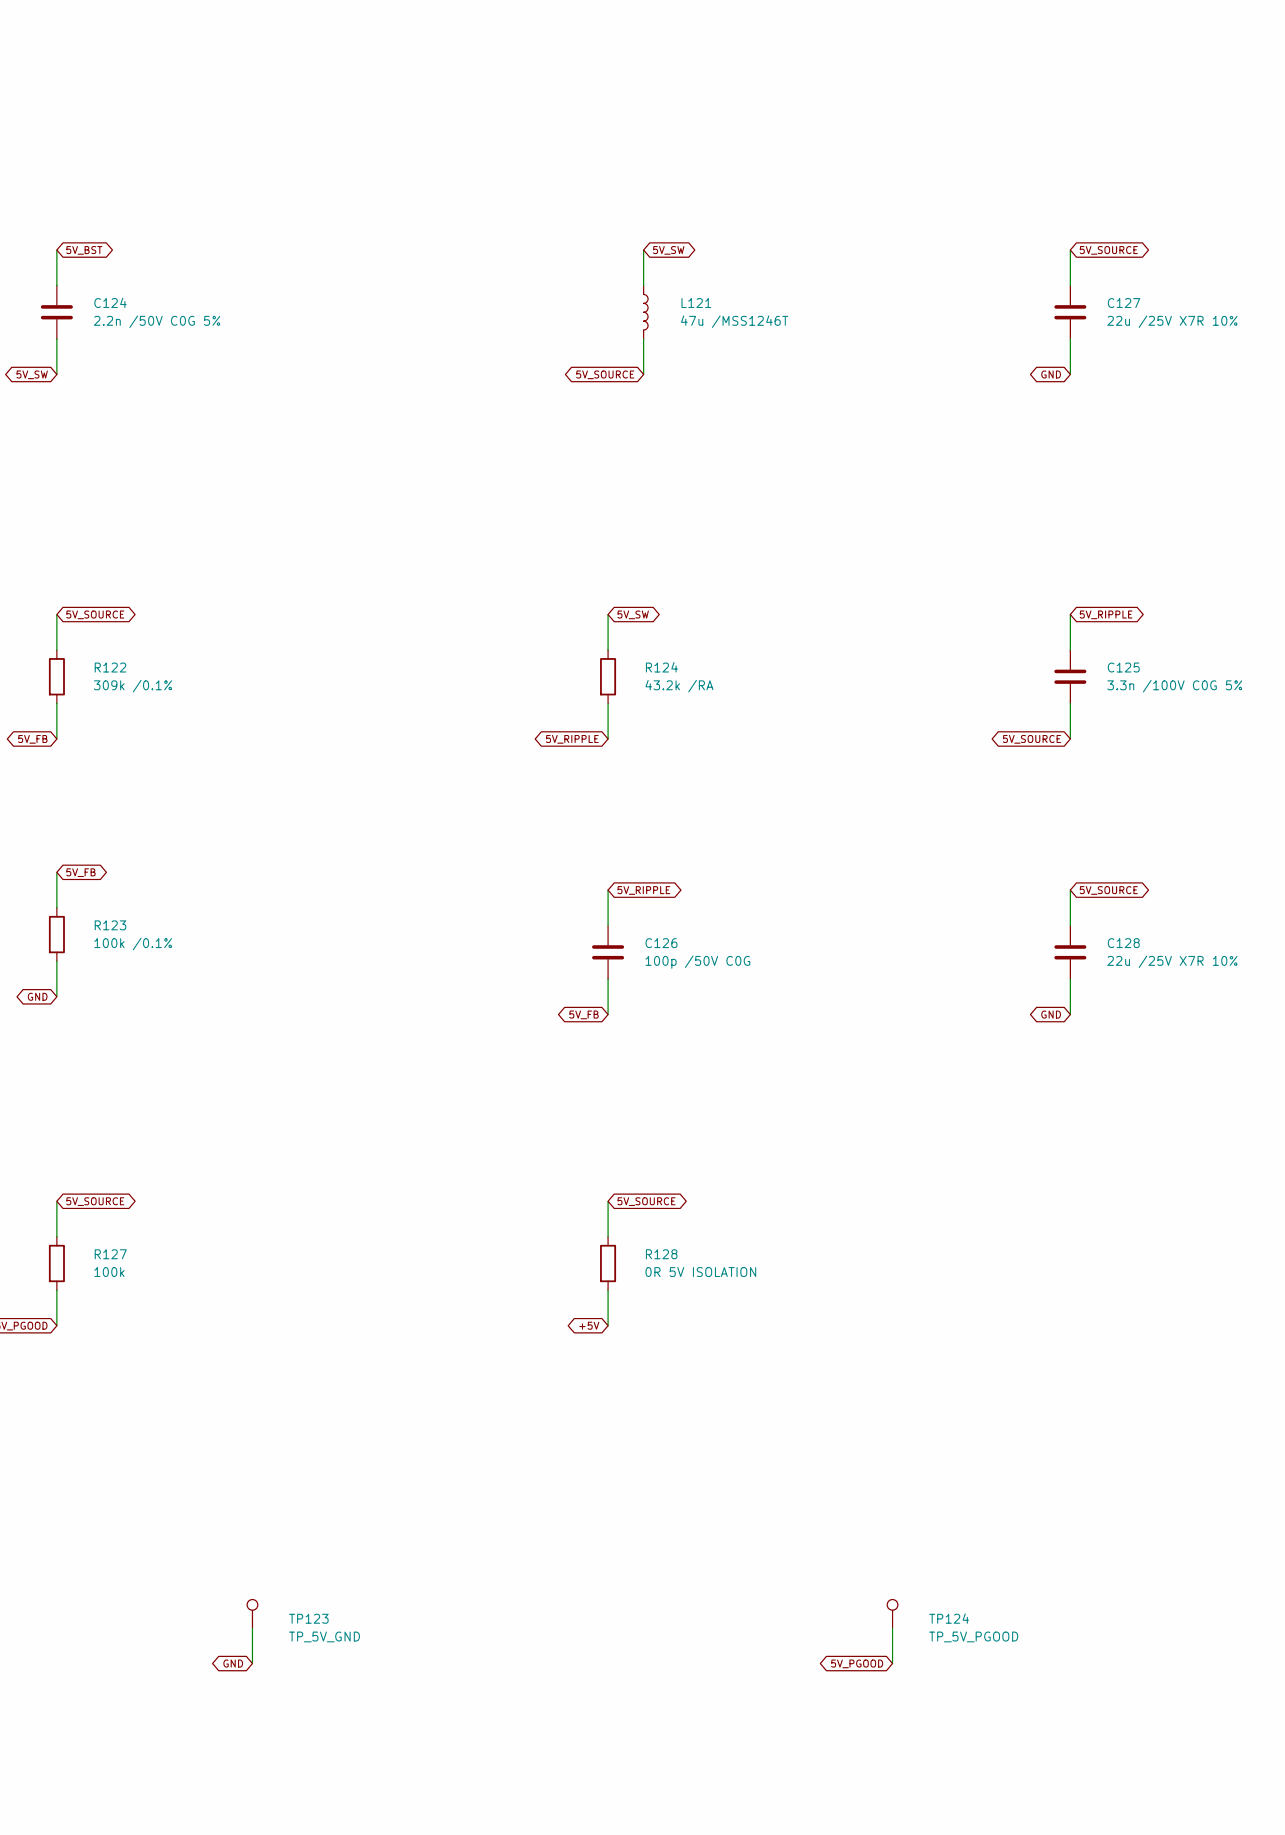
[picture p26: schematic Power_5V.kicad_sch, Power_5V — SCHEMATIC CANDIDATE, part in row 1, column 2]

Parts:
C121, C122, C129: 2.2u /100V X7R; C_1210_3225Metric; MPN CGA6N3X7R2A225K230AB; LCSC C342652
C123: 100n /100V X7R; C_0805_2012Metric; MPN CGA4J2X7R2A104K125AA; LCSC C342919
C124: 2.2n /50V C0G 5%; C_0603_1608Metric; MPN CGA3E2C0G1H222J080AA; LCSC C2169200
C125: 3.3n /100V C0G 5%; C_0603_1608Metric; MPN CGA3E2C0G2A332J080AA; LCSC C2171993
C126: 100p /50V C0G; C_0603_1608Metric; MPN CGA3E2C0G1H101J080AA; LCSC C76709
C127, C128: 22u /25V X7R 10%; C_1210_3225Metric; MPN MCAST32MSB7226KPNA01; LCSC C5372271
L121: 47u /MSS1246T; Coilcraft_MSS1246T_12x12_RVB22_L121; MPN MSS1246T-473MLC
R121: 31.6k /RON; R_0603_1608Metric; MPN TNPW060331K6BEEA; LCSC C843870
R122: 309k /0.1%; R_0805_2012Metric; MPN TNPW0805309KBEEA; LCSC C1710754
R123: 100k /0.1%; R_0603_1608Metric; MPN TNPW0603100KBEEA; LCSC C844888
R124: 43.2k /RA; R_0603_1608Metric; MPN TNPW060343K2BEEA; LCSC C2089718
R125: 100k; R_1206_3216Metric; MPN CRCW1206100KFKEA; LCSC C844863
R126: 26.1k; R_0603_1608Metric; MPN ERA3AEB2612V; LCSC C491123
R127: 100k; R_0603_1608Metric; MPN CRCW0603100KFKEA; LCSC C844916
R128: 0R 5V ISOLATION; R_1206_3216Metric; MPN CRCW12060000Z0EA; LCSC C190124
TP121: TP_5V; TestPoint_Pad_D1.5mm; MPN BARE PCB PAD
TP122: TP_5V_SOURCE; TestPoint_Pad_D1.5mm; MPN BARE PCB PAD
TP123: TP_5V_GND; TestPoint_Pad_D1.5mm; MPN BARE PCB PAD
TP124: TP_5V_PGOOD; TestPoint_Pad_D1.5mm; MPN BARE PCB PAD
U121: LM5164DDAR; TI_DDA0008B_4214849B; MPN LM5164DDAR; LCSC C477928

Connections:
5V_BST: C124.1, U121.7 (BST)
5V_EN: R125.2, R126.1, U121.3 (EN_UVLO)
5V_FB: C126.2, R122.2, R123.1, U121.5 (FB)
5V_PGOOD: R127.2, TP124.1, U121.6 (PGOOD)
5V_RIPPLE: C125.1, C126.1, R124.2
5V_RON: R121.1, U121.4 (RON)
5V_SOURCE: C125.2, C127.1, C128.1, L121.2, R122.1, R127.1, R128.1, TP122.1
5V_SW: C124.2, L121.1, R124.1, U121.8 (SW)
5V_VIN: C121.1, C122.1, C123.1, C129.1, R125.1, U121.2 (VIN); also elsewhere on the board
+5V: R128.2, TP121.1; also elsewhere on the board
GND: C121.2, C122.2, C123.2, C127.2, C128.2, C129.2, R121.2, R123.2, R126.2, TP123.1, U121.1 (GND), U121.9 (EP_GND); also elsewhere on the board

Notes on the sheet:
RVB-02 — LM5164-Q1 WIDE INPUT BUCK /5V /1A CAPABILITY Fresh physical pin map; COT TYPE3 ripple injection is required. Nominal rail target5.0V; feedback accounts for ripple offset. See calculations.
R125/R126 gives local start~7.25V / stop~6.76V; upstream UV disconnect acts first in steady state. 2.2nF bootstrap value is intentional. CA is between RIPPLE and VOUT; CB couples to FB. Kelvin FB bottom return to pin1/EP. Minimize VIN–SW–GND hot loop and switch-node copper. L121 manufacturer recomm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

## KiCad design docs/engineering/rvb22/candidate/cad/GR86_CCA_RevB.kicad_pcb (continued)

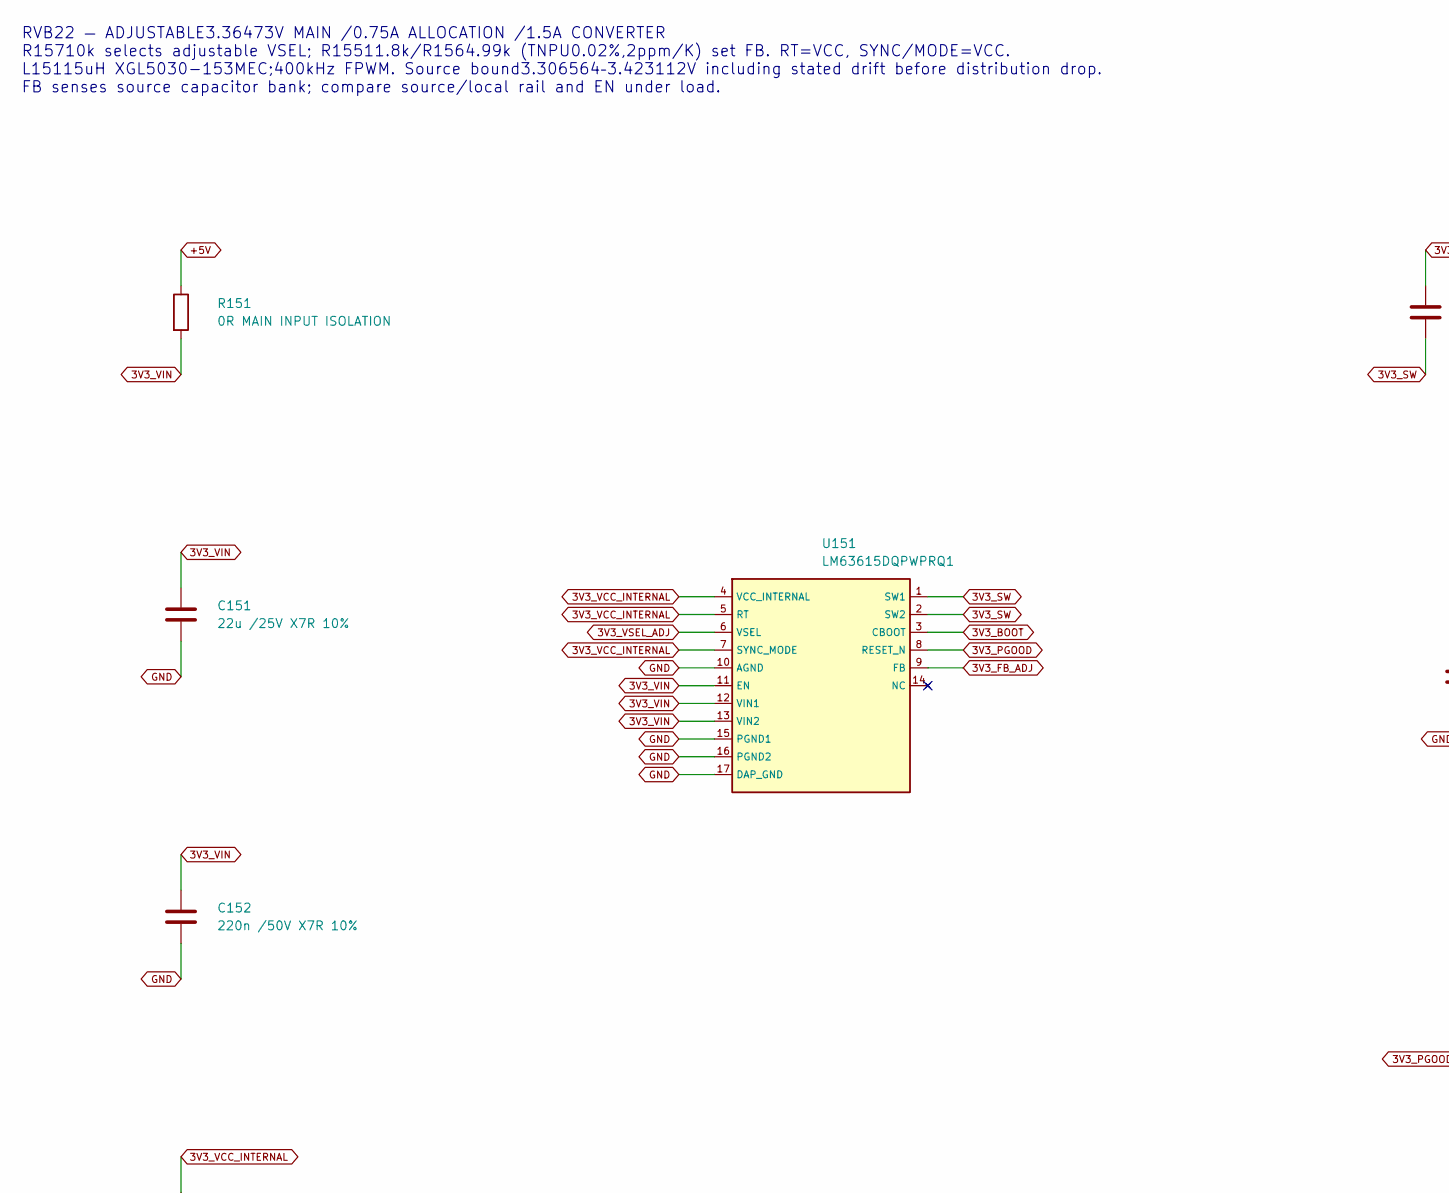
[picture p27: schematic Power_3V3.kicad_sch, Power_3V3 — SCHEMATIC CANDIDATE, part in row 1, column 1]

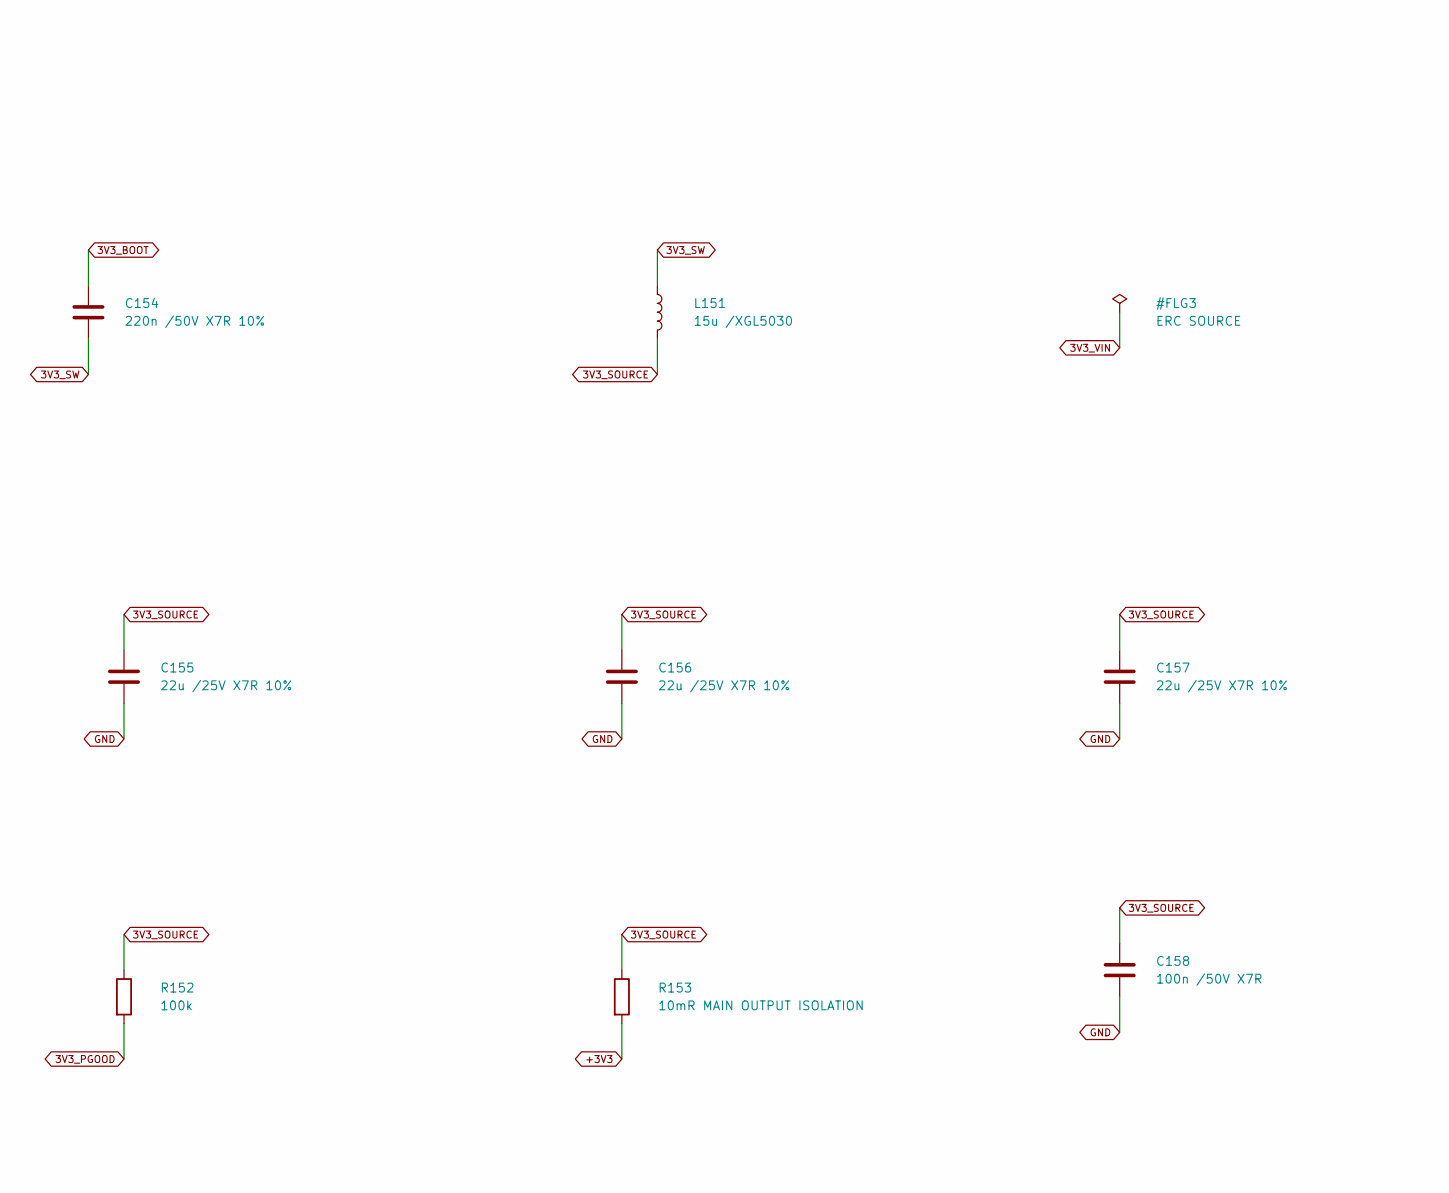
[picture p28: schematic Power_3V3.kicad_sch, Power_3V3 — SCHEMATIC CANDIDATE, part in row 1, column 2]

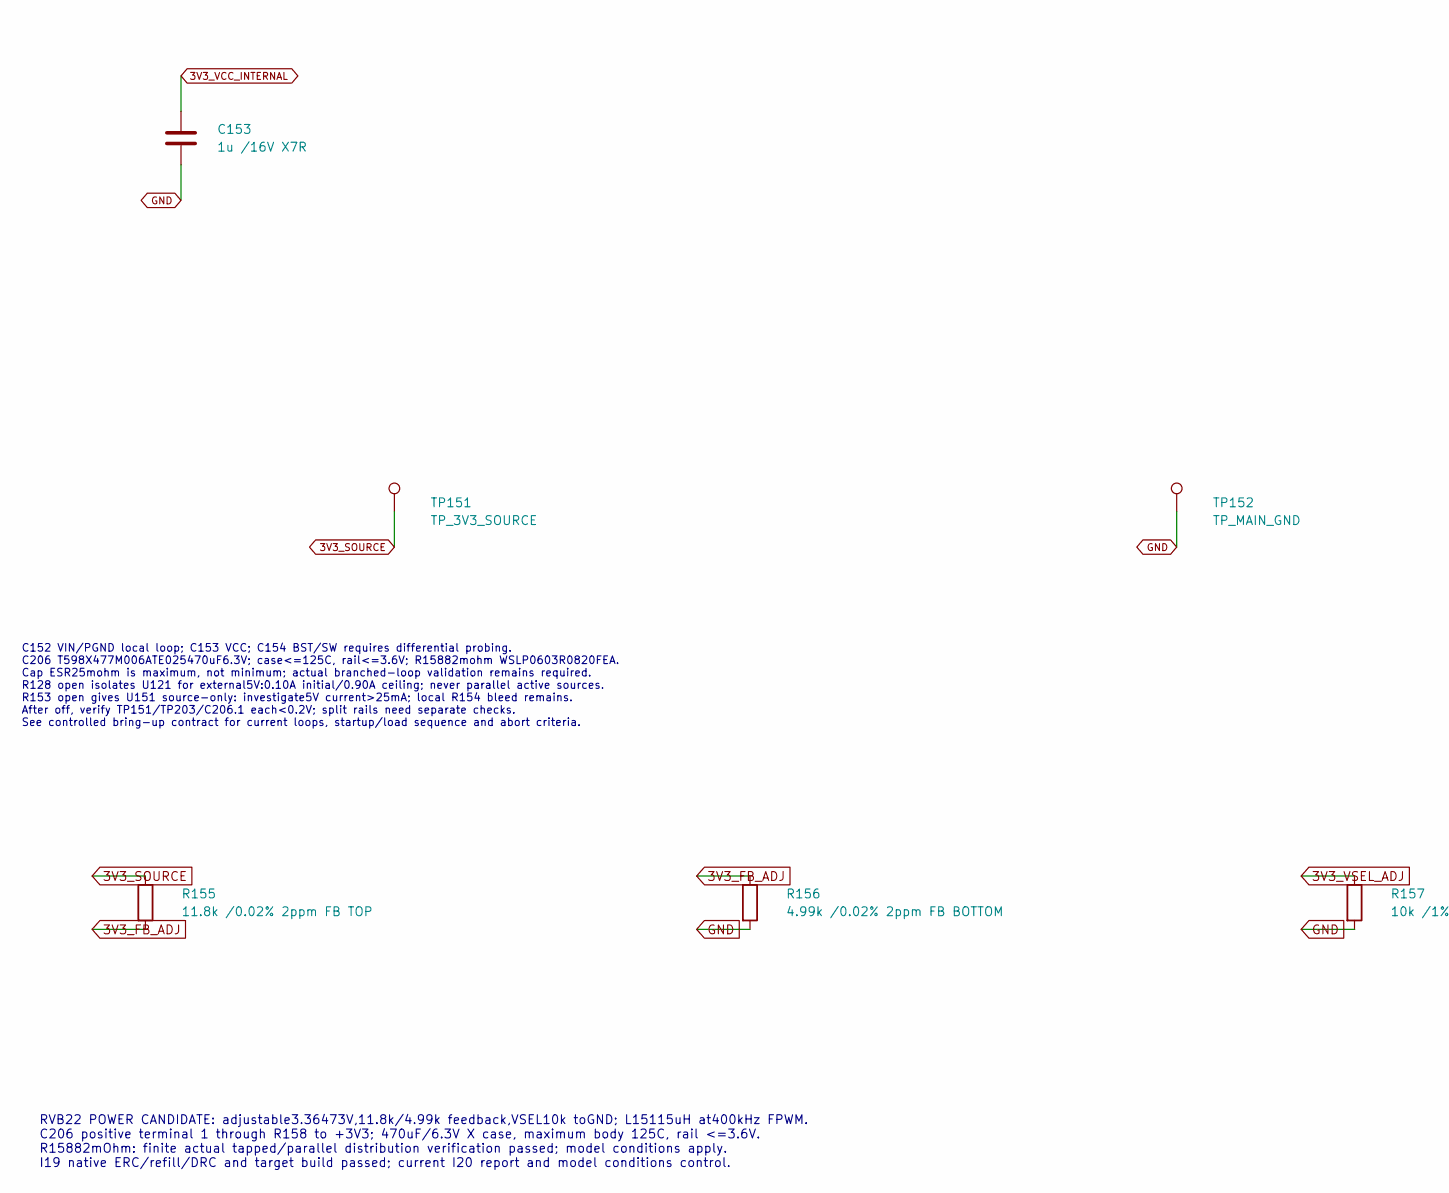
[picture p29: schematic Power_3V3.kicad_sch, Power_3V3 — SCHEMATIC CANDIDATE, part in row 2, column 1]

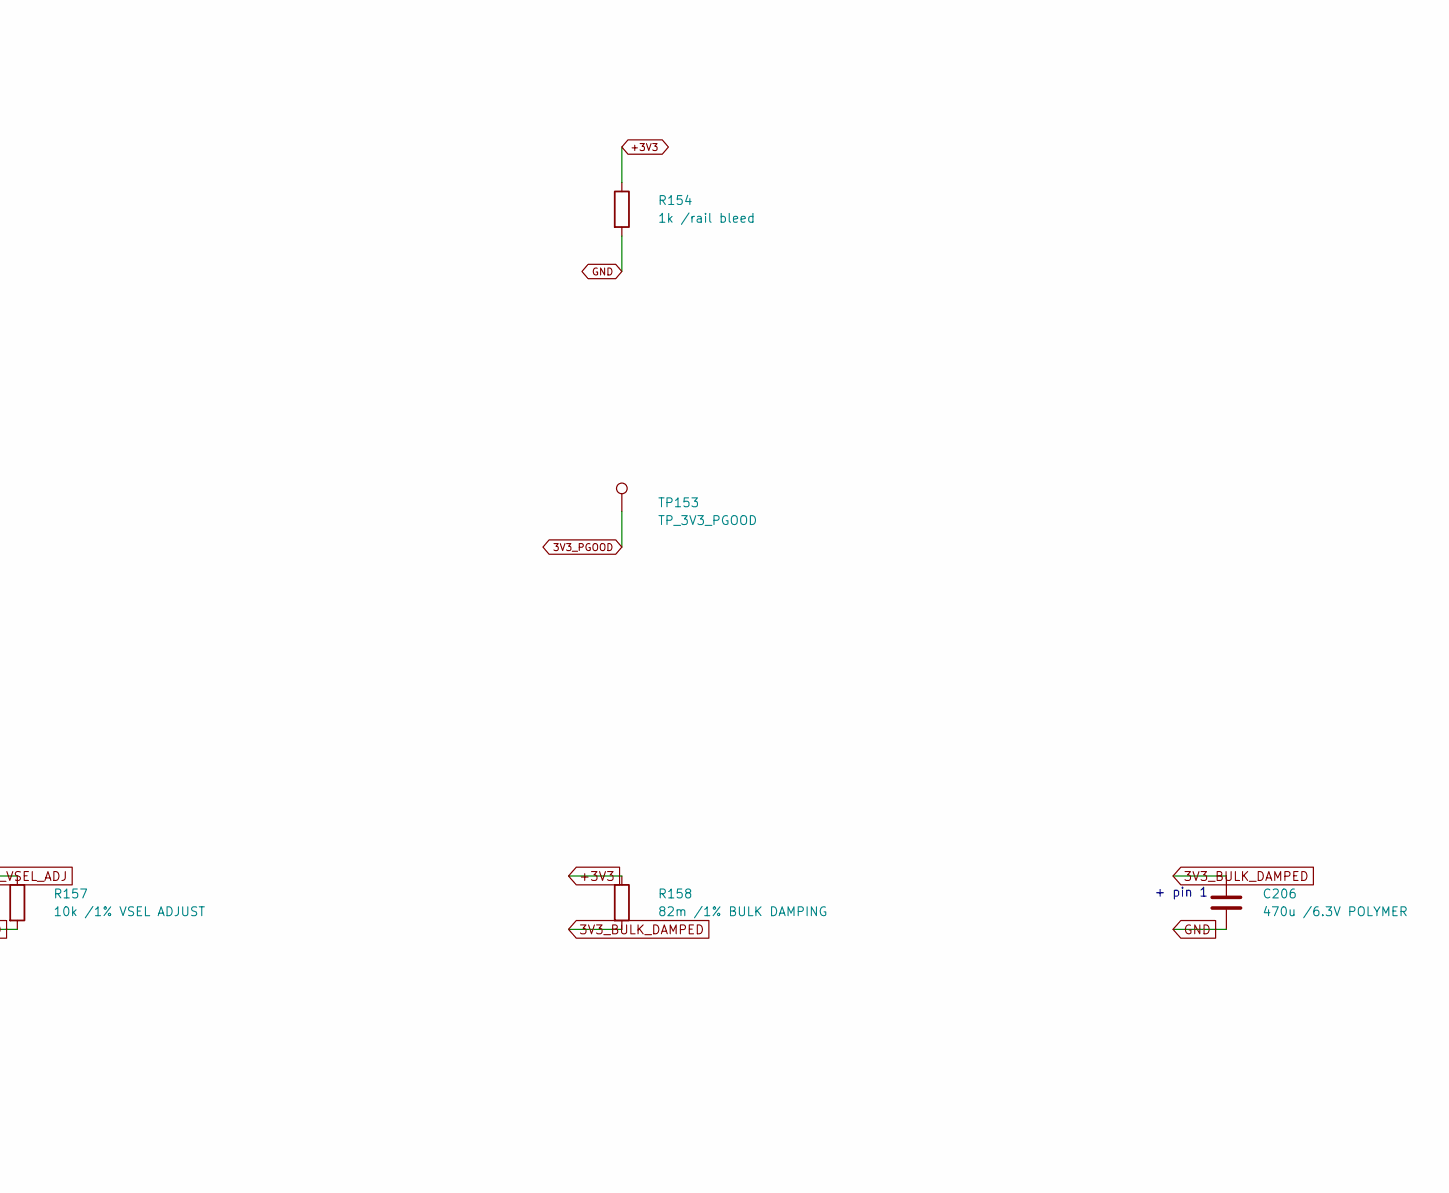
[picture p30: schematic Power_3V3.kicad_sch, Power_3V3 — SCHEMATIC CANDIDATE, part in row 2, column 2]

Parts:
C151, C155, C156, C157: 22u /25V X7R 10%; C_1210_3225Metric; MPN MCAST32MSB7226KPNA01; LCSC C5372271
C152: 220n /50V X7R 10%; C_0603_1608Metric; MPN CGA3E3X7R1H224K080AB; LCSC C342967
C153: 1u /16V X7R; C_0603_1608Metric; MPN GCM188R71C105KA64D; LCSC C161212
C154: 220n /50V X7R 10%; C_0603_1608Metric_RVB22_C154; MPN CGA3E3X7R1H224K080AB; LCSC C342967
C158: 100n /50V X7R; C_0603_1608Metric; MPN GCM188R71H104KA57D; LCSC C85864
C206: 470u /6.3V POLYMER; KEMET_T598_X_7343_Median_RVB22_C206; MPN T598X477M006ATE025
L151: 15u /XGL5030; L_Coilcraft_XAL5030-XXX; MPN XGL5030-153MEC
R151: 0R MAIN INPUT ISOLATION; R_1206_3216Metric; MPN CRCW12060000Z0EA; LCSC C190124
R152: 100k; R_0603_1608Metric; MPN CRCW0603100KFKEA; LCSC C844916
R153: 10mR MAIN OUTPUT ISOLATION; WSLP0603_MANUFACTURER_R153; MPN WSLP0603R0100FEA
R154: 1k /rail bleed; R_0603_1608Metric; MPN CRCW06031K00FKEA; LCSC C844920
R155: 11.8k /0.02% 2ppm FB TOP; R_0603_1608Metric_RVB22_R155; MPN TNPU060311K8HWEA00
R156: 4.99k /0.02% 2ppm FB BOTTOM; R_0603_1608Metric_RVB22_R156; MPN TNPU06034K99HWEA00
R157: 10k /1% VSEL ADJUST; R_0603_1608Metric_RVB22_R157; MPN CRCW060310K0FKEA
R158: 82m /1% BULK DAMPING; WSLP0603_MANUFACTURER; MPN WSLP0603R0820FEA
TP151: TP_3V3_SOURCE; TestPoint_Pad_D1.5mm; MPN BARE PCB PAD
TP152: TP_MAIN_GND; TestPoint_Pad_D1.5mm; MPN BARE PCB PAD
TP153: TP_3V3_PGOOD; TestPoint_Pad_D1.5mm; MPN BARE PCB PAD
U151: LM63615DQPWPRQ1; HTSSOP-16-1EP_4.4x5mm_P0.65mm_EP3.4x5mm_Mask2.46x2.31mm_RVB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; MPN LM63615DQPWPRQ1; LCSC C2867799

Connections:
3V3_BOOT: C154.1, U151.3 (CBOOT)
3V3_BULK_DAMPED: C206.1, R158.2
3V3_FB_ADJ: R155.2, R156.1, U151.9 (FB)
3V3_PGOOD: R152.2, TP153.1, U151.8 (RESET_N)
3V3_SOURCE: C155.1, C156.1, C157.1, C158.1, L151.2, R152.1, R153.1, R155.1, TP151.1
3V3_SW: C154.2, L151.1, U151.1 (SW1), U151.2 (SW2)
3V3_VCC_INTERNAL: C153.1, U151.4 (VCC_INTERNAL), U151.5 (RT), U151.7 (SYNC_MODE)
3V3_VIN: C151.1, C152.1, R151.2, U151.11 (EN), U151.12 (VIN1), U151.13 (VIN2)
3V3_VSEL_ADJ: R157.1, U151.6 (VSEL)
+3V3: R153.2, R154.1, R158.1; also elsewhere on the board
+5V: R151.1; also elsewhere on the board
GND: C151.2, C152.2, C153.2, C155.2, C156.2, C157.2, C158.2, C206.2, R154.2, R156.2, R157.2, TP152.1, U151.10 (AGND), U151.15 (PGND1), U151.16 (PGND2), U151.17 (DAP_GND); also elsewhere on the board

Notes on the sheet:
RVB22 — ADJUSTABLE3.36473V MAIN /0.75A ALLOCATION /1.5A CONVERTER R15710k selects adjustable VSEL; R15511.8k/R1564.99k (TNPU0.02%,2ppm/K) set FB. RT=VCC, SYNC/MODE=VCC. L15115uH XGL5030-153MEC;400kHz FPWM. Source bound3.306564–3.423112V including stated drift before distribution drop. FB senses sou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
C152 VIN/PGND local loop; C153 VCC; C154 BST/SW requires differential probing. C206 T598X477M006ATE025470uF6.3V; case<=125C, rail<=3.6V; R15882mohm WSLP0603R0820FEA. Cap ESR25mohm is maximum, not minimum; actual branched-loop validation remains required. R128 open isolates U121 for external5V:0.10A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
+ pin 1
RVB22 POWER CANDIDATE: adjustable3.36473V,11.8k/4.99k feedback,VSEL10k toGND; L15115uH at400kHz FPWM. C206 positive terminal 1 through R158 to +3V3; 470uF/6.3V X case, maximum body 125C, rail <=3.6V. R15882mOhm: finite actual tapped/parallel distribution verification passed; model conditions apply.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

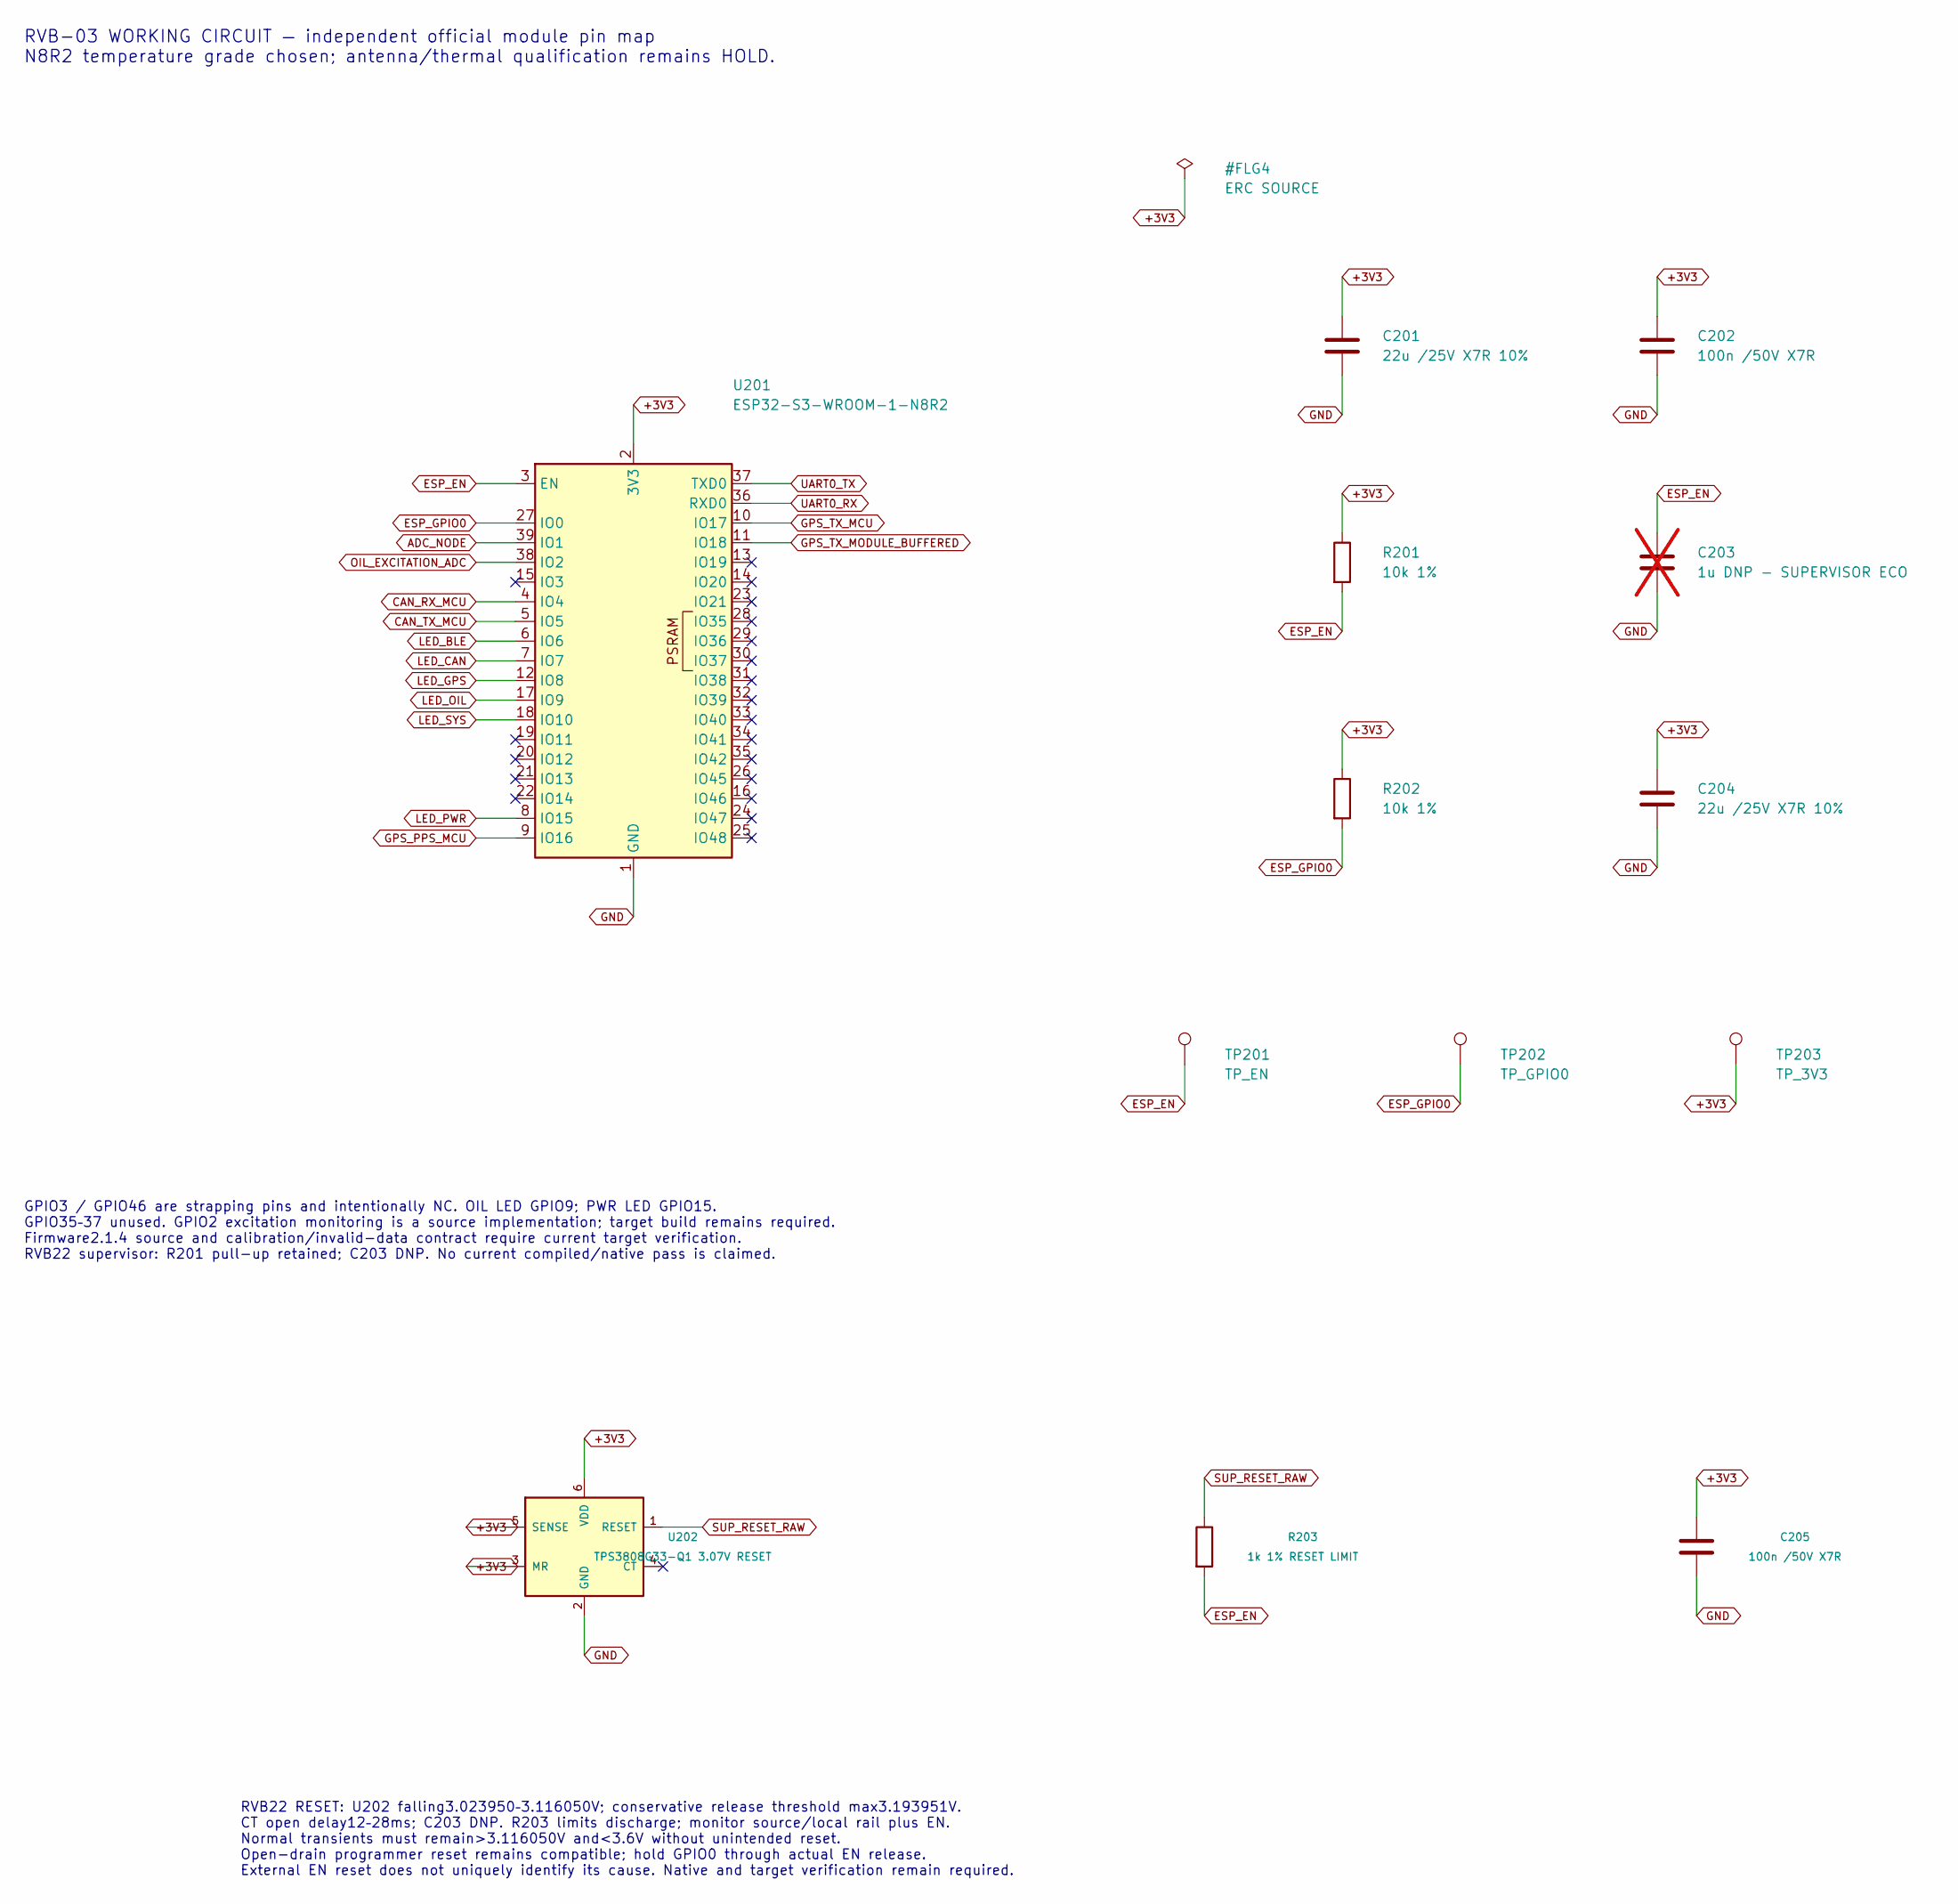
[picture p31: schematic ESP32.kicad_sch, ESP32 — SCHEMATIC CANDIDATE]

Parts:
C201, C204: 22u /25V X7R 10%; C_1210_3225Metric; MPN MCAST32MSB7226KPNA01; LCSC C5372271
C202: 100n /50V X7R; C_0603_1608Metric; MPN GCM188R71H104KA57D; LCSC C85864
C203: 1u DNP - SUPERVISOR ECO; C_0603_1608Metric; MPN GCM188R71C105KA64D; LCSC C161212; not fitted
C205: 100n /50V X7R; C_0603_1608Metric_RVB22_C205; MPN GCM188R71H104KA57D; LCSC C85864
R201, R202: 10k 1%; R_0603_1608Metric; MPN CRCW060310K0FKEA; LCSC C844918
R203: 1k 1% RESET LIMIT; R_0603_1608Metric_RVB22_R203; MPN CRCW06031K00FKEA; LCSC C844920
TP201: TP_EN; TestPoint_Pad_D1.5mm; MPN BARE PCB PAD
TP202: TP_GPIO0; TestPoint_Pad_D1.5mm; MPN BARE PCB PAD
TP203: TP_3V3; TestPoint_Pad_D1.5mm; MPN BARE PCB PAD
U201: ESP32-S3-WROOM-1-N8R2; ESP32-S3-WROOM-1_RVB22_U201_TH48; MPN ESP32-S3-WROOM-1-N8R2; LCSC C2913204
U202: TPS3808G33-Q1 3.07V RESET; TPS3808_DBV0006A; MPN TPS3808G33QDBVRQ1

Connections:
+3V3: C201.1, C202.1, C204.1, C205.1, R201.1, R202.1, TP203.1, U201.2 (3V3), U202.3 (MR), U202.5 (SENSE), U202.6 (VDD); also elsewhere on the board
ADC_NODE: U201.39 (IO1); also elsewhere on the board
CAN_RX_MCU: U201.4 (IO4); also elsewhere on the board
CAN_TX_MCU: U201.5 (IO5); also elsewhere on the board
ESP_EN: C203.1, R201.2, R203.2, TP201.1, U201.3 (EN); also elsewhere on the board
ESP_GPIO0: R202.2, TP202.1, U201.27 (IO0); also elsewhere on the board
GND: C201.2, C202.2, C203.2, C204.2, C205.2, U201.1 (GND), U201.40 (GND), U201.41 (GND), U202.2 (GND); also elsewhere on the board
GPS_PPS_MCU: U201.9 (IO16); also elsewhere on the board
GPS_TX_MCU: U201.10 (IO17); also elsewhere on the board
GPS_TX_MODULE_BUFFERED: U201.11 (IO18); also elsewhere on the board
LED_BLE: U201.6 (IO6); also elsewhere on the board
LED_CAN: U201.7 (IO7); also elsewhere on the board
LED_GPS: U201.12 (IO8); also elsewhere on the board
LED_OIL: U201.17 (IO9); also elsewhere on the board
LED_PWR: U201.8 (IO15); also elsewhere on the board
LED_SYS: U201.18 (IO10); also elsewhere on the board
OIL_EXCITATION_ADC: U201.38 (IO2); also elsewhere on the board
SUP_RESET_RAW: R203.1, U202.1 (RESET)
UART0_RX: U201.36 (RXD0); also elsewhere on the board
UART0_TX: U201.37 (TXD0); also elsewhere on the board

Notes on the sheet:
RVB-03 WORKING CIRCUIT — independent official module pin map N8R2 temperature grade chosen; antenna/thermal qualification remains HOLD.
GPIO3 / GPIO46 are strapping pins and intentionally NC. OIL LED GPIO9; PWR LED GPIO15. GPIO35–37 unused. GPIO2 excitation monitoring is a source implementation; target build remains required. Firmware2.1.4 source and calibration/invalid-data contract require current target verification. RVB22 super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
RVB22 RESET: U202 falling3.023950–3.116050V; conservative release threshold max3.193951V. CT open delay12–28ms; C203 DNP. R203 limits discharge; monitor source/local rail plus EN. Normal transients must remain>3.116050V and<3.6V without unintended reset. Open-drain programmer reset remains compatib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

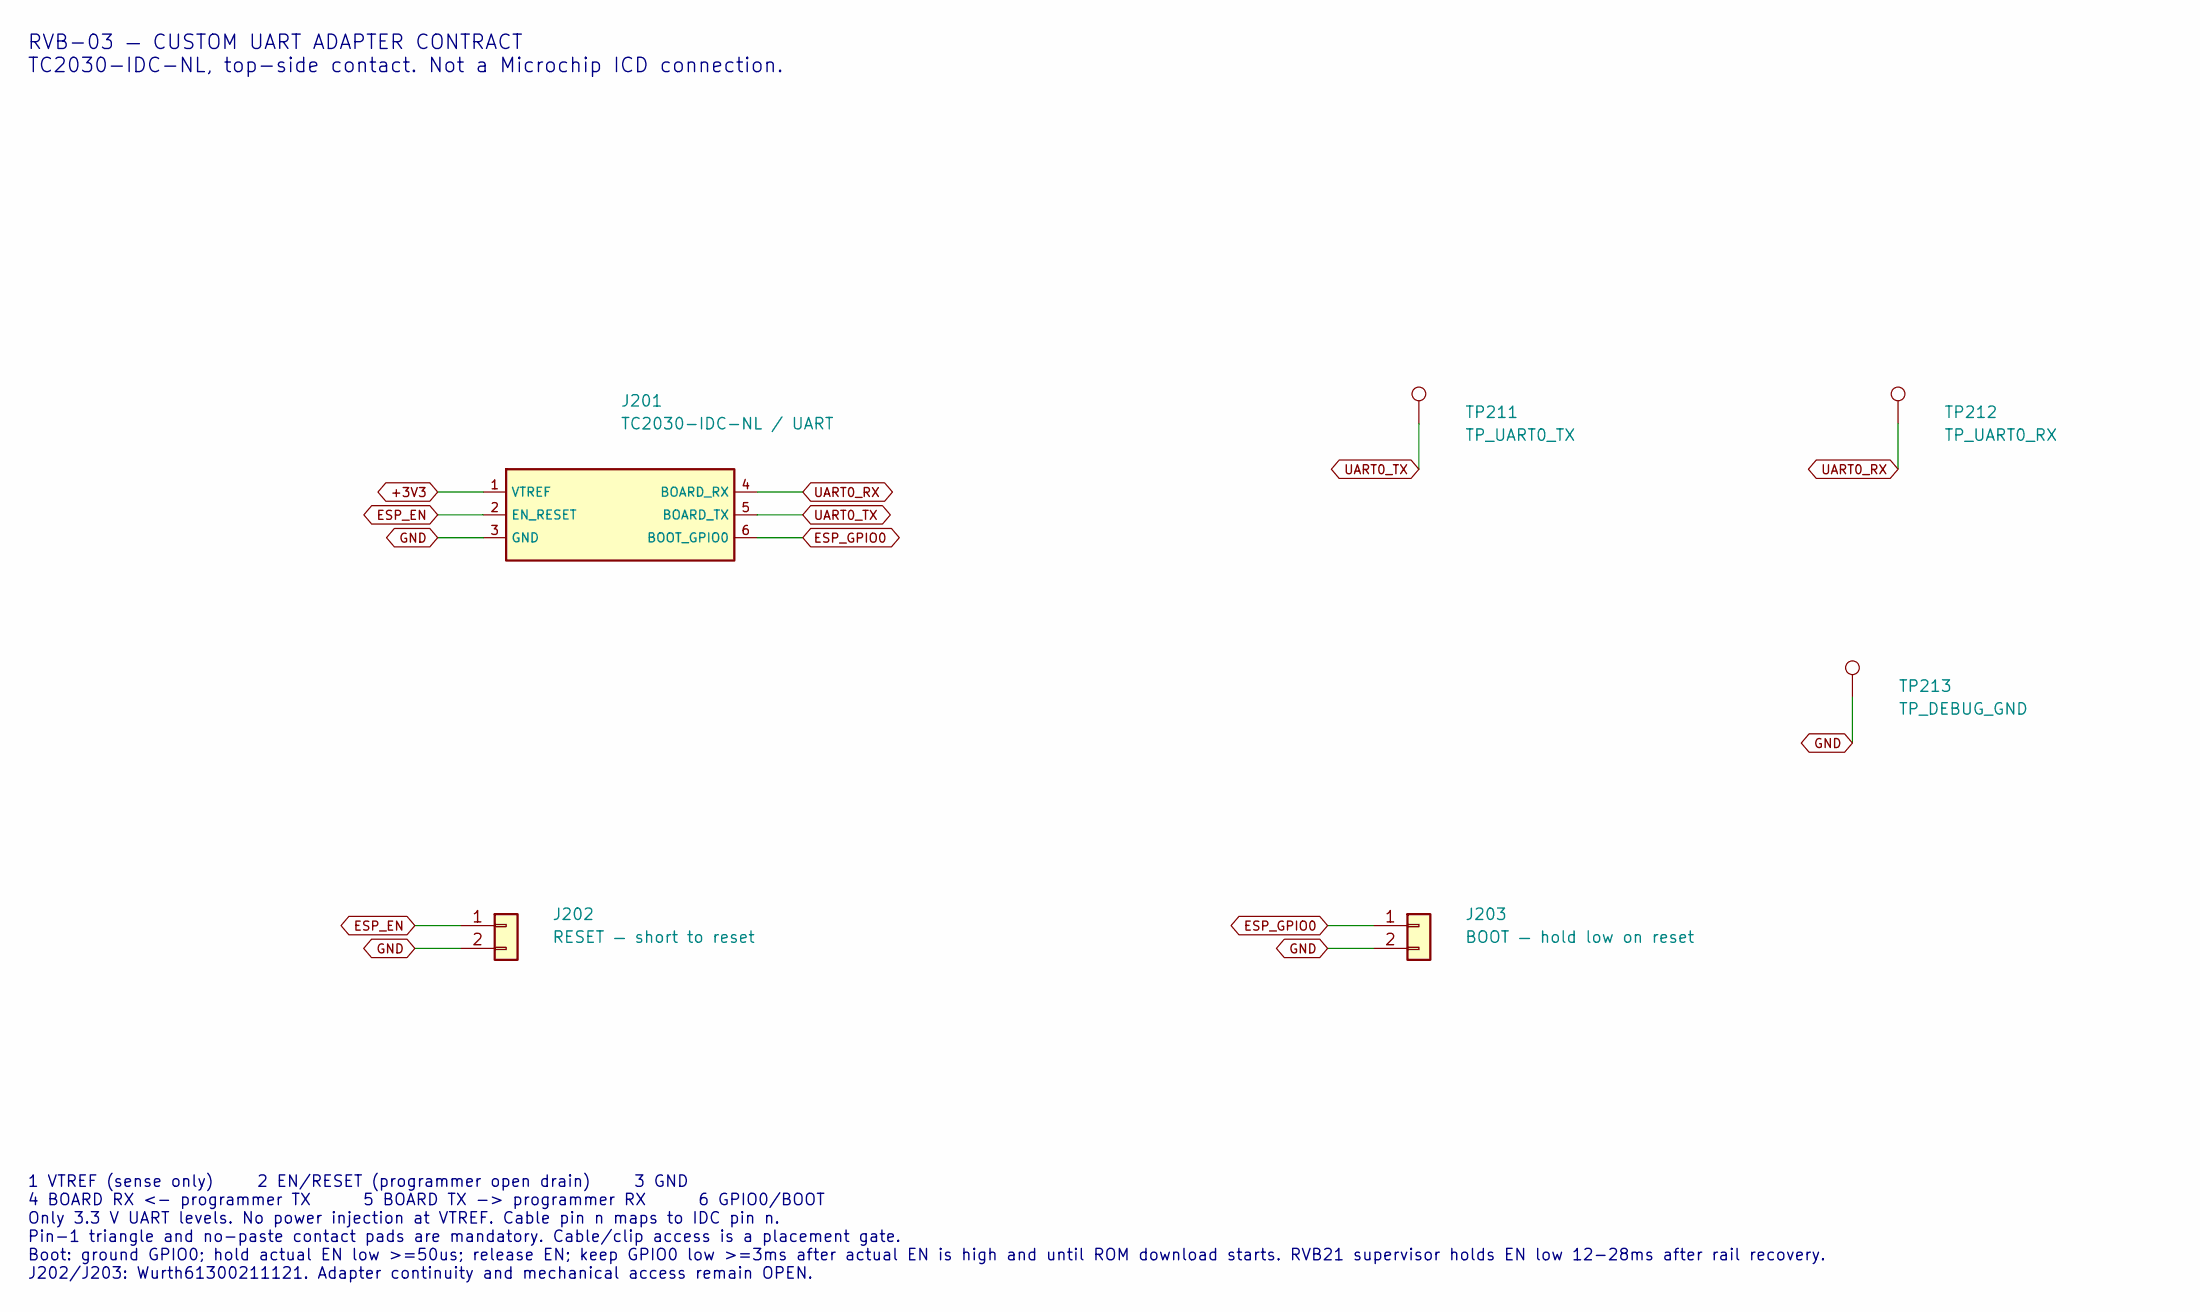
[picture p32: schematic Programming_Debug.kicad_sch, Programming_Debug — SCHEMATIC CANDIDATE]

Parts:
J201: TC2030-IDC-NL / UART; Tag-Connect_TC2030-IDC-NL_2x03_P1.27mm_Vertical; MPN TC2030-IDC-NL (tool, not assembled comp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
J202: RESET — short to reset; Wurth_61300211121_1x02; MPN 61300211121; LCSC C2915055
J203: BOOT — hold low on reset; Wurth_61300211121_1x02; MPN 61300211121; LCSC C2915055
TP211: TP_UART0_TX; TestPoint_Pad_D1.5mm; MPN BARE PCB PAD
TP212: TP_UART0_RX; TestPoint_Pad_D1.5mm; MPN BARE PCB PAD
TP213: TP_DEBUG_GND; TestPoint_Pad_D1.5mm; MPN BARE PCB PAD

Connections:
+3V3: J201.1 (VTREF); also elsewhere on the board
ESP_EN: J201.2 (EN_RESET), J202.1; also elsewhere on the board
ESP_GPIO0: J201.6 (BOOT_GPIO0), J203.1; also elsewhere on the board
GND: J201.3 (GND), J202.2, J203.2, TP213.1; also elsewhere on the board
UART0_RX: J201.4 (BOARD_RX), TP212.1; also elsewhere on the board
UART0_TX: J201.5 (BOARD_TX), TP211.1; also elsewhere on the board

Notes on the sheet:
RVB-03 — CUSTOM UART ADAPTER CONTRACT TC2030-IDC-NL, top-side contact. Not a Microchip ICD connection.
1 VTREF (sense only) 2 EN/RESET (programmer open drain) 3 GND 4 BOARD RX <- programmer TX 5 BOARD TX -> programmer RX 6 GPIO0/BOOT Only 3.3 V UART levels. No power injection at VTREF. Cable pin n maps to IDC pin n. Pin-1 triangle and no-paste contact pads are mandatory. Cable/clip access is a place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


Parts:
C301: 100n /50V X7R; C_0603_1608Metric; MPN GCM188R71H104KA57D; LCSC C85864
C302: 1u /16V X7R; C_0603_1608Metric; MPN GCM188R71C105KA64D; LCSC C161212
D301: ESD2CAN24DBZRQ1; SOT-23; MPN ESD2CAN24DBZRQ1; LCSC C5736151
R301: 0R DNP; R_0603_1608Metric; MPN CRCW06030000Z0EA; not fitted
R302: 1k; R_0603_1608Metric; MPN CRCW06031K00FKEA; LCSC C844920
R303: 10k 1%; R_0603_1608Metric; MPN CRCW060310K0FKEA; LCSC C844918
R306: 120R 1% DNP; R_1206_3216Metric; MPN CRCW1206120RFKEA; not fitted
SJ301: BENCH TERM OPEN; SolderJumper-2_P1.3mm_Open_Pad1.0x1.5mm; MPN BARE PCB OPEN SOLDER LINK
TP301: TP_CANH; TestPoint_Pad_D1.5mm; MPN BARE PCB PAD
TP302: TP_CANL; TestPoint_Pad_D1.5mm; MPN BARE PCB PAD
TP303: TP_CAN_TXD; TestPoint_Pad_D1.5mm; MPN BARE PCB PAD
TP304: TP_CAN_RXD; TestPoint_Pad_D1.5mm; MPN BARE PCB PAD
TP305: TP_CAN_GND; TestPoint_Pad_D1.5mm; MPN BARE PCB PAD
U301: TCAN3403DRBRQ1; TI_DRB0008J_TCAN3403; MPN TCAN3403DRBRQ1; LCSC C32921356

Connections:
+3V3: C301.1, C302.1, R303.1, U301.3 (VCC), U301.5 (VIO); also elsewhere on the board
CANH: D301.1 (IO1), R306.1, TP301.1, U301.7 (CANH); also elsewhere on the board
CANL: D301.2 (IO2), SJ301.2 (B), TP302.1, U301.6 (CANL); also elsewhere on the board
CAN_RXD: R302.1, TP304.1, U301.4 (RXD)
CAN_RX_MCU: R302.2; also elsewhere on the board
CAN_TERM_LINK: R306.2, SJ301.1 (A)
CAN_TXD: R301.2, R303.2, TP303.1, U301.1 (TXD)
CAN_TX_MCU: R301.1; also elsewhere on the board
GND: C301.2, C302.2, D301.3 (GND), TP305.1, U301.2 (GND), U301.8 (STB), U301.9 (EP_GND); also elsewhere on the board

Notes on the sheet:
RVB-04 — VEHICLE RECEIVE DEFAULT / TCAN3403DRBRQ1 R301 DNP inhibits TX. R306 DNP + SJ301 open leave vehicle termination open.
Pin 5 is VIO on TCAN3403; it is NOT VREF or SHDN. Pin 8 STB is hard low for full-bandwidth RX. Standby mode is not used as a silent receive mode. External R303 holds TXD recessive. Vehicle firmware must use listen-only. Isolated bench ACK testing needs R301 fitted and normal mode. CCA receives pass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

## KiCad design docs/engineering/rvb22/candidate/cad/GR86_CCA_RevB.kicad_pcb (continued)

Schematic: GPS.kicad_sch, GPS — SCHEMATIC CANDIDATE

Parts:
C401, C402: 22u /25V X7R 10%; C_1210_3225Metric; MPN MCAST32MSB7226KPNA01; LCSC C5372271
C403, C404, C405: 100n /50V X7R; C_0603_1608Metric; MPN GCM188R71H104KA57D; LCSC C85864
D401: SEARCH (blink / no fix); LED_0603_1608Metric; MPN APT1608SGC; LCSC C5875754
D402: TPD1E05U06DPYR; TI_DPY0002A_TPD1E05U06_SMDMask; MPN TPD1E05U06DPYR; LCSC C436349
J401: U.FL-R-SMT-1(80); Hirose_UFL_R_SMT_1_80_RevB; MPN U.FL-R-SMT-1(80); LCSC C88374
L406: 1.6nH 5% RF MATCH; Murata_LQW18AS_1608; MPN LQW18AS1N6J0ZD
R401: 0R GPS ISOLATION; R_0603_1608Metric; MPN CRCW06030000Z0EA; LCSC C844915
R402, R403, R404: 220R; R_0603_1608Metric; MPN AA0603FR-07220RL; LCSC C2100485
R405: 1k; R_0603_1608Metric; MPN CRCW06031K00FKEA; LCSC C844920
R407, R408, R409: 100k; R_0603_1608Metric; MPN CRCW0603100KFKEA; LCSC C844916
R410: 10k /UART idle; R_0603_1608Metric; MPN CRCW060310K0FKEA; LCSC C844918
R411: 100k /off-state; R_0603_1608Metric; MPN CRCW0603100KFKEA; LCSC C844916
TP401: TP_GPS_TX; TestPoint_Pad_D1.5mm; MPN BARE PCB PAD
TP402: TP_GPS_RX; TestPoint_Pad_D1.5mm; MPN BARE PCB PAD
TP403: TP_GPS_PPS; TestPoint_Pad_D1.5mm; MPN BARE PCB PAD
TP404: TP_GPS_3V3; TestPoint_Pad_D1.5mm; MPN BARE PCB PAD
TP405: TP_GPS_GND; TestPoint_Pad_D1.5mm; MPN BARE PCB PAD
U401: PA1616D; CDTop_PA1616D_20Pad_v06; MPN PA1616D
U402, U404: SN74LVC2G125DCUR; VSSOP-8_2.3x2mm_P0.5mm; MPN SN74LVC2G125DCUR; LCSC C21404
U403: MIC5504-3.3YM5-TR; SOT-23-5; MPN MIC5504-3.3YM5-TR; LCSC C88419

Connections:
+3V3: C404.1, R410.1, U402.8 (VCC); also elsewhere on the board
+5V: R401.1; also elsewhere on the board
GND: C401.2, C402.2, C403.2, C404.2, C405.2, D401.1 (K), D402.2 (GND_A), J401.2 (Ext), R407.2, R408.2, R409.2, R411.2, TP405.1, U401.3 (GND), U401.8 (GND), U401.12 (GND), U401.19 (GND), U402.1 (1OE_N), U402.4 (GND), U402.7 (2OE_N), U403.2 (GND), U404.1 (1OE_N), U404.4 (GND), U404.7 (2OE_N); also elsewhere on the board
GPS_3V3: C402.1, C403.1, C405.1, TP404.1, U401.1 (VCC), U403.5 (VOUT), U404.8 (VCC)
GPS_5V_IN: C401.1, R401.2, U403.1 (VIN), U403.3 (EN)
GPS_ANT_RF_BIASED: L406.1, U401.11 (EX_ANT_BIASED)
GPS_EXT_ANT: D402.1 (IO_K), J401.1 (In), L406.2
GPS_FIX_RAW: R409.1, U401.5 (3D_FIX), U404.5 (2A)
GPS_PPS_BUFFER: R403.1, U402.3 (2Y)
GPS_PPS_MCU: R403.2; also elsewhere on the board
GPS_PPS_RAW: R408.1, TP403.1, U401.13 (PPS_2V8), U402.5 (2A)
GPS_RX_BUFFER: R404.1, U404.6 (1Y)
GPS_RX_MODULE: R404.2, TP402.1, U401.10 (RX0)
GPS_SEARCH_BUFFER: R405.1, U404.3 (2Y)
GPS_SEARCH_LED_A: D401.2 (A), R405.2
GPS_TX_BUFFER: R402.1, U402.6 (1Y)
GPS_TX_MCU: R410.2, R411.1, U404.2 (1A); also elsewhere on the board
GPS_TX_MODULE_BUFFERED: R402.2; also elsewhere on the board
GPS_TX_RAW: R407.1, TP401.1, U401.9 (TX0), U402.2 (1A)

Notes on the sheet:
RVB-05 GPS — TX/RX CROSSED; LEVEL BUFFERS; DEDICATED3.3V PA1616D pin1 is upper-left in the manufacturer top view. No electrical pad21.
U402 receives GPS TX/PPS on main3V3; U404 drives GPS RX on GPS3V3. Exact TI input VIH2.0V. R410/R411 set GPIO17 UART idle; GPIO17 may drive LOW briefly at power-up, so firmware renegotiates after boot. GPS-only fixture:1k bleed on main3V3, verify main rail<=0.2V before asserting off-domain behavior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
UART default and external-antenna ESD

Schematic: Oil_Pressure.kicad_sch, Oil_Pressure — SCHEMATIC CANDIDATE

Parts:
C501, C513, C523: 22n /50V X7R; C_0603_1608Metric; MPN CGA3E2X7R1H223K080AE; LCSC C2176922
C502, C531: 100n /50V X7R; C_0603_1608Metric; MPN GCM188R71H104KA57D; LCSC C85864
C503: 100n /100V X7R; C_0805_2012Metric; MPN CGA4J2X7R2A104K125AA; LCSC C342919
C504, C505, C506: 10u /50V X7R; KEMET_C1210_10u50V; MPN C1210C106K5RACTU; LCSC C2167688
C511, C512, C521, C522: 1u /16V X7R; C_0603_1608Metric; MPN GCM188R71C105KA64D; LCSC C161212
C514, C524: 100p /50V C0G5%; C_0603_1608Metric; MPN CGA3E2C0G1H101J080AA; LCSC C76709
C532: 10n /50V C0G 5% OUT HF; C_0603_1608Metric; MPN GRM1885C1H103JA01D
D501: ESD2CAN24DBZRQ1; SOT-23; MPN ESD2CAN24DBZRQ1; LCSC C5736151
D502: SS16 /60V Schottky; D_SMA; MPN SS16HE3_B/H; LCSC C266798
D511, D512, D521, D522: PMEG2010BEA,115; Nexperia_SOD323_PMEG2010BEA; MPN PMEG2010BEA,115; LCSC C455041
R501: 27.4k /0.1%; R_0603_1608Metric; MPN TNPW060327K4BEEA; LCSC C2079063
R502, R504: 10k /0.1%; R_0603_1608Metric; MPN TNPW060310K0BEEA; LCSC C844890
R503: 36.5k /0.1%; R_0603_1608Metric; MPN TNPW060336K5BEEA; LCSC C2089518
R505: 118k /0.1%; R_0805_2012Metric; MPN TNPW0805118KBEEA; LCSC C1709453
R506: 100k; R_0603_1608Metric; MPN CRCW0603100KFKEA; LCSC C844916
R507: 4.7R /1% pulse HP; R_2512_6332Metric; MPN CRCW25124R70FKEGHP; LCSC C2075852
R511, R521: 1M /0.1%; R_0805_2012Metric; MPN TNPW08051M00BEEA; LCSC C844679
R512, R522: 4.02k /0.1%; R_0603_1608Metric; MPN TNPW06034K02BEEA; LCSC C844459
R513, R523: 124k /0.1%; R_0805_2012Metric; MPN TNPW0805124KBEEA; LCSC C1709494
R514, R524: 1k /0.1%; R_0603_1608Metric; MPN TNPW06031K00BEEA; LCSC C844891
R515, R525: 220R /1%150ppm; R_0603_1608Metric; MPN AA0603FR-07220RL; LCSC C2100485
TP501: TP_OIL_SIG; TestPoint_Pad_D1.5mm; MPN BARE PCB PAD
TP502: TP_OIL_FILTERED; TestPoint_Pad_D1.5mm; MPN BARE PCB PAD
TP503: TP_ADC_NODE; TestPoint_Pad_D1.5mm; MPN BARE PCB PAD
TP504: TP_OIL_GND; TestPoint_Pad_D1.5mm; MPN BARE PCB PAD
TP505: TP_OIL_5V; TestPoint_Pad_D1.5mm; MPN BARE PCB PAD
TP506: TP_OIL_EXC_ADC; TestPoint_Pad_D1.5mm; MPN BARE PCB PAD
TP507: TP_OIL_SHDN; TestPoint_Pad_D1.5mm; MPN BARE PCB PAD
TP508: TP_OIL_POWER_FAULT; TestPoint_Pad_D1.5mm; MPN BARE PCB PAD
TP509: TP_OIL_EFUSE_RTN; TestPoint_Pad_D1.5mm; MPN BARE PCB PAD
TP510: TP_OIL_EFUSE_OUT; TestPoint_Pad_D1.5mm; MPN BARE PCB PAD
U501: TPS26600PWPR; TI_PWP0016A_TPS2660; MPN TPS26600PWPR; LCSC C544399
U502: OPA2333AIDR; SOIC-8_3.9x4.9mm_P1.27mm; MPN OPA2333AIDR; LCSC C38732

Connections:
+3V3: C531.1, D511.1 (K), D521.1 (K), R506.1, U502.8 (VPOS); also elsewhere on the board
+5V: C502.1, R501.1, R503.1, U501.1 (IN1), U501.2 (IN2); also elsewhere on the board
ADC_NODE: C513.1, D511.2 (A), D512.1 (K), R513.1, R515.2, TP503.1; also elsewhere on the board
GND: C502.2, C503.2, C504.2, C505.2, C506.2, C511.2, C512.2, C513.2, C521.2, C522.2, C523.2, C531.2, C532.2, D501.3 (GND), D502.2 (A), D512.2 (A), D522.2 (A), R512.2, R514.2, R522.2, R524.2, TP504.1, U501.9 (GND), U502.4 (VNEG); also elsewhere on the board
OIL_5V: C503.1, D501.2 (IO2), R507.2, R521.1, TP505.1; also elsewhere on the board
OIL_AMP_OUT: C514.1, R515.1, U502.1 (OUT_A)
OIL_DVDT: C501.1, U501.12 (DVDT)
OIL_EFUSE_OUT: C504.1, C505.1, C506.1, C532.1, D502.1 (K), R507.1, TP510.1, U501.15 (OUT1), U501.16 (OUT2)
OIL_EFUSE_RTN: C501.2, R502.2, R504.2, R505.2, TP509.1, U501.8 (RTN), U501.17 (EP_RTN)
OIL_EXCITATION_ADC: C523.1, D521.2 (A), D522.1 (K), R523.1, R525.2, TP506.1; also elsewhere on the board
OIL_EXC_AMP_OUT: C524.1, R525.1, U502.7 (OUT_B)
OIL_EXC_FB: C524.2, R523.2, R524.1, U502.6 (INB_N)
OIL_EXC_FILTERED: C521.1, C522.1, R521.2, R522.1, U502.5 (INB_P)
OIL_FB: C514.2, R513.2, R514.1, U502.2 (INA_N)
OIL_FILTERED: C511.1, C512.1, R511.2, R512.1, TP502.1, U502.3 (INA_P)
OIL_ILIM: R505.1, U501.11 (ILIM)
OIL_OVP: R503.2, R504.1, U501.5 (OVP)
OIL_POWER_FAULT_N: R506.2, TP508.1, U501.14 (FLT_N)
OIL_SHDN: TP507.1, U501.7 (SHDN)
OIL_SIG: D501.1 (IO1), R511.1, TP501.1; also elsewhere on the board
OIL_UVLO: R501.2, R502.1, U501.3 (UVLO)

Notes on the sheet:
RVB-06 — HONEYWELL150psi /RATIOMETRIC5V /GPIO1 ADC Connector signal → 1:249.76 attenuator → precision gain125 → low-impedance ADC drive. OIL5V excitation is current limited and reverse-current blocked; no direct5V-to-ADC path.
RTN is a private eFuse reference; do not short it to GND. Its thermal pad also goes to RTN. MODE floats for circuit-breaker/auto-retry. SHDN uses its internal2–3.4V pullup; TP permits temporary low-to-RTN reset. UVLO is externally programmed: grounding it would select a14.9V default and disable a5V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
RVB22 C532 OUT-to-GND HF bypass:10nF C0G50V; never privateRTN. Direct U501 OUTpad16 feed also joins C504 OUTland and existing In1 OUTcopper; use actual non-tree nodal model. Preserve C504/C505/C506 bulk and C514 feedback. New-loop25nH/common-star10nH are allocations; native fill and hardware remain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

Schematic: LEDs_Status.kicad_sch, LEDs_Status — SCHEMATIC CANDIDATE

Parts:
D601: PWR; LED_0603_1608Metric; MPN APT1608SGC; LCSC C5875754
D602: BLE; LED_0603_1608Metric; MPN APT1608SGC; LCSC C5875754
D603: CAN; LED_0603_1608Metric; MPN APT1608SGC; LCSC C5875754
D604: GPS; LED_0603_1608Metric; MPN APT1608SGC; LCSC C5875754
D605: SYS; LED_0603_1608Metric; MPN APT1608SGC; LCSC C5875754
D606: OIL; LED_0603_1608Metric; MPN APT1608SGC; LCSC C5875754
R601: 1k / GPIO15; R_0603_1608Metric; MPN CRCW06031K00FKEA; LCSC C844920
R602: 1k / GPIO6; R_0603_1608Metric; MPN CRCW06031K00FKEA; LCSC C844920
R603: 1k / GPIO7; R_0603_1608Metric; MPN CRCW06031K00FKEA; LCSC C844920
R604: 1k / GPIO8; R_0603_1608Metric; MPN CRCW06031K00FKEA; LCSC C844920
R605: 1k / GPIO10; R_0603_1608Metric; MPN CRCW06031K00FKEA; LCSC C844920
R606: 1k / GPIO9; R_0603_1608Metric; MPN CRCW06031K00FKEA; LCSC C844920

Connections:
GND: D601.1 (K), D602.1 (K), D603.1 (K), D604.1 (K), D605.1 (K), D606.1 (K); also elsewhere on the board
LED_BLE: R602.1; also elsewhere on the board
LED_BLE_A: D602.2 (A), R602.2
LED_CAN: R603.1; also elsewhere on the board
LED_CAN_A: D603.2 (A), R603.2
LED_GPS: R604.1; also elsewhere on the board
LED_GPS_A: D604.2 (A), R604.2
LED_OIL: R606.1; also elsewhere on the board
LED_OIL_A: D606.2 (A), R606.2
LED_PWR: R601.1; also elsewhere on the board
LED_PWR_A: D601.2 (A), R601.2
LED_SYS: R605.1; also elsewhere on the board
LED_SYS_A: D605.2 (A), R605.2

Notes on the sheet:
STATUS INDICATORS — ACTIVE HIGH GPIO3/GPIO46 strapping pins are free of external LED loads in Rev B. Firmware Rev B contract moves OIL to GPIO9 and PWR to GPIO15.
1000ohm current limiting. See qualification/LED_STRAP_REVIEW.md. Indicators represent firmware state and do not replace physical rail/bus measurements.

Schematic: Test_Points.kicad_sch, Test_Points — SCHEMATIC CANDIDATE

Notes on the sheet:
TEST AND ISOLATION DIRECTORY Probe points are placed on the functional sheets beside their circuits. Bring-up removes rail0ohm links before testing each source independently. R301 TXD and R306 termination are DNP; SJ301 is open for vehicle tap use. L406 RF matching inductor is factory fitted in RVB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



Board: 4 copper layers, 88.3 x 61.3 mm, 199 parts (103 on the bottom side), 92 nets.

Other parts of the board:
MH901, MH902, MH903, MH904: 4.4mm NPTH; MountingHole_4.4mm_Outboard

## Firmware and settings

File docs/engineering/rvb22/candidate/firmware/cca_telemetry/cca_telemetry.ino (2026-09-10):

// ===== GR86 CCA Telemetry: stability-first RaceChrono bridge =====
//
// This sketch intentionally favors deterministic recovery over aggressive retries:
// - BLE advertising is event-driven and never stop/start-cycled from loop().
// - RaceChrono uses its standard unencrypted 0x1FF8 protocol (no passkey/token shim).
// - CAN is always accept-all at the controller; filtering happens in software.
// - CAN silence is normal. Only an actual TWAI fault triggers recovery.
// - CAN bring-up and recovery are non-blocking, so BLE/GPS/CLI stay alive.
// - CAN frames are coalesced by ID before BLE transmission to prevent backlog storms.
//
// Board: ESP32-S3 Dev Module
// Baseline toolchain: Arduino-ESP32 3.3.6 + NimBLE-Arduino 2.3.6
// Rev B ERB corrective source; build identity and manifest distinguish images.

#include <Arduino.h>
#include <NimBLEDevice.h>
#include <Preferences.h>
#include <atomic>
#include <freertos/queue.h>
#include "src/racechrono_codec.h"
#include "src/oil_model.h"
#include "src/oil_fault_recovery.h"
#include "src/boot_diagnostics.h"
#include "src/driver_loss.h"
#include "src/runtime_timing.h"
#include "src/runtime_config.h"
#include "src/io_budget.h"
#include <esp_attr.h>

#include <driver/twai.h>
#include <esp_err.h>
#include <esp_heap_caps.h>
#include <esp_system.h>
#include <esp_task_wdt.h>

#if defined(__has_include)
#  if __has_include(<esp_idf_version.h>)
#    include <esp_idf_version.h>
#  endif
#endif

#include <ctype.h>
#include <math.h>
#include <stdint.h>
#include <stdio.h>
#include <string.h>

#include "config.h"
#include "src/gps_nmea.h"
#include "src/gps_solution_epoch.h"
#include "src/gps_mode_config.h"
#include "src/led_status.h"
#include "src/nvs_cfg.h"

namespace cca {

// All application diagnostics are buffered. service() writes only bytes already
// accepted by UART TX capacity, up to64 bytes/pass; no blocking flush exists.
class DiagnosticLog final : public Print {
 public:
  using Print::write;
  size_t write(uint8_t c) override { return queue_.append(&c, 1); }
  size_t write(const uint8_t* data, size_t count) override {
    return queue_.append(data, count);
  }
  void service() {
    const int available = Serial.availableForWrite();
    if (available <= 0 || queue_.size() == 0) return;
    const size_t count = std::min<size_t>(64u, std::min<size_t>(
        static_cast<size_t>(available), queue_.contiguousSize()));
    queue_.consume(Serial.write(queue_.contiguousData(), count));
  }
  size_t queued() const { return queue_.size(); }
  size_t highWater() const { return queue_.highWater(); }
  uint64_t dropped() const { return queue_.dropped(); }
 private:
  io::ByteQueue<8192> queue_;
};
static DiagnosticLog g_log;
static uint32_t g_maxLoopGapUs = 0, g_previousLoopUs = 0;
static uint32_t g_cliCommands = 0;
static uint32_t g_canCacheCoalesced = 0, g_canQueueHighWater = 0;
static uint32_t g_canFilteredCount = 0;


// -----------------------------------------------------------------------------
// Build identity
// -----------------------------------------------------------------------------

static constexpr const char* BUILD_ID = "2.1.4-revb-recovered-20260909";

// -----------------------------------------------------------------------------
// Hardware pins
// -----------------------------------------------------------------------------

static constexpr int CAN_TX_GPIO = 5;
static constexpr int CAN_RX_GPIO = 4;

static constexpr int GPS_RX_GPIO = 18;  // GPS TX -> ESP RX
static constexpr int GPS_TX_GPIO = 17;  // GPS RX <- ESP TX

static constexpr int OIL_ADC_PIN = 1;
static constexpr int OIL_EXC_ADC_PIN = 2;
#if !defined(CONFIG_IDF_TARGET_ESP32S3)
#error "Rev B requires an ESP32-S3 target"
#endif
#if defined(ARDUINO_USB_CDC_ON_BOOT) && ARDUINO_USB_CDC_ON_BOOT
#error "Rev B debug connector uses UART0; disable USB CDC on boot"
#endif

// -----------------------------------------------------------------------------
// RaceChrono DIY BLE UUIDs
// -----------------------------------------------------------------------------

static constexpr uint16_t RC_SERVICE_UUID = 0x1FF8;
static constexpr uint16_t RC_CHAR_CAN_UUID = 0x0001;
static constexpr uint16_t RC_CHAR_FILTER_UUID = 0x0002;
static constexpr uint16_t RC_CHAR_GPS_UUID = 0x0003;
static constexpr uint16_t RC_CHAR_GPS_TIME_UUID = 0x0004;

// -----------------------------------------------------------------------------
// General helpers
// -----------------------------------------------------------------------------

static inline bool timeReached(uint32_t now, uint32_t deadline) {
  return static_cast<int32_t>(now - deadline) >= 0;
}

static inline uint32_t elapsedMs(uint32_t now, uint32_t then) {
  return now - then;
}

static inline float clampFloat(float value, float low, float high) {
  if (value < low) return low;
  if (value > high) return high;
  return value;
}

static const char* resetReasonName(esp_reset_reason_t reason) {
  switch (reason) {
    case ESP_RST_UNKNOWN:   return "UNKNOWN";
    case ESP_RST_POWERON:   return "POWERON";
    case ESP_RST_EXT:       return "EXT";
    case ESP_RST_SW:        return "SW";
    case ESP_RST_PANIC:     return "PANIC";
    case ESP_RST_INT_WDT:   return "INT_WDT";
    case ESP_RST_TASK_WDT:  return "TASK_WDT";
    case ESP_RST_WDT:       return "WDT";
    case ESP_RST_DEEPSLEEP: return "DEEPSLEEP";
    case ESP_RST_BROWNOUT:  return "BROWNOUT";
    case ESP_RST_SDIO:      return "SDIO";
#ifdef ESP_RST_USB
    case ESP_RST_USB:       return "USB";
#endif
#ifdef ESP_RST_JTAG
    case ESP_RST_JTAG:      return "JTAG";
#endif
#ifdef ESP_RST_CPU_LOCKUP
    case ESP_RST_CPU_LOCKUP:return "CPU_LOCKUP";
#endif
    default:                return "OTHER";
  }
}

static esp_reset_reason_t g_bootResetReason = ESP_RST_UNKNOWN;
static RTC_NOINIT_ATTR diagnostics::BootRecord g_retainedBootRecord;

// -----------------------------------------------------------------------------
// Watchdog
// -----------------------------------------------------------------------------

static void initWatchdog() {
  esp_err_t initResult = ESP_OK;

#if defined(ESP_IDF_VERSION_MAJOR) && (ESP_IDF_VERSION_MAJOR >= 5)
  esp_task_wdt_config_t config = {};
  config.timeout_ms = 5000;
  config.idle_core_mask = 0;
  config.trigger_panic = true;
  initResult = esp_task_wdt_init(&config);
#else
  initResult = esp_task_wdt_init(5, true);
#endif

  if (initResult != ESP_OK && initResult != ESP_ERR_INVALID_STATE) {
    g_log.printf("WARN: task watchdog init failed: %d\n",
                  static_cast<int>(initResult));
  }

  const esp_err_t addResult = esp_task_wdt_add(nullptr);
  if (addResult != ESP_OK && addResult != ESP_ERR_INVALID_STATE &&
      addResult != ESP_ERR_INVALID_ARG) {
    g_log.printf("WARN: task watchdog add failed: %d\n",
                  static_cast<int>(addResult));
  }
}

// -----------------------------------------------------------------------------
// Configuration and runtime filtering
// -----------------------------------------------------------------------------

static Preferences g_prefs;
static constexpr const char* CFG_NAMESPACE = "cca_cfg_b";

static bool g_profileEnabled = true;
static uint16_t g_oilPublishPeriodMs = 20;

struct __attribute__((packed)) StoredPidDivider {
  uint16_t pid;
  uint8_t divider;
};

static constexpr size_t MAX_CUSTOM_DIVIDERS = 64;

static StoredPidDivider g_customDividers[MAX_CUSTOM_DIVIDERS] = {};
static uint16_t g_customDividerCount = 0;

static int customDividerIndex(uint32_t pid) {
  if (pid > 0xFFFFu) return -1;
  for (uint16_t i = 0; i < g_customDividerCount; ++i) {
    if (g_customDividers[i].pid == static_cast<uint16_t>(pid)) {
      return static_cast<int>(i);
    }
  }
  return -1;
}

static uint8_t customDividerFor(uint32_t pid) {
  const int index = customDividerIndex(pid);
  if (index < 0) return 0;
  uint8_t divider = g_customDividers[index].divider;
  return divider == 0 ? 1 : divider;
}

static bool setCustomDivider(uint32_t pid, uint8_t divider) {
  if (pid > 0x7FFu) return false;
  if (divider == 0) divider = 1;

  const int existing = customDividerIndex(pid);
  if (existing >= 0) {
    g_customDividers[existing].divider = divider;
    return true;
  }

  if (g_customDividerCount >= MAX_CUSTOM_DIVIDERS) return false;
  g_customDividers[g_customDividerCount].pid = static_cast<uint16_t>(pid);
  g_customDividers[g_customDividerCount].divider = divider;
  ++g_customDividerCount;
  return true;
}

static void clearCustomDividers() {
  memset(g_customDividers, 0, sizeof(g_customDividers));
  g_customDividerCount = 0;
}

static constexpr size_t MAX_DENIED_PIDS = 64;
static uint32_t g_deniedPids[MAX_DENIED_PIDS] = {};
static size_t g_deniedPidCount = 0;

static bool isDenied(uint32_t pid) {
  for (size_t i = 0; i < g_deniedPidCount; ++i) {
    if (g_deniedPids[i] == pid) return true;
  }
  return false;
}

static void denyPid(uint32_t pid) {
  if (isDenied(pid)) return;
  if (g_deniedPidCount < MAX_DENIED_PIDS) {
    g_deniedPids[g_deniedPidCount++] = pid;
  }
}

static void undenyPid(uint32_t pid) {
  for (size_t i = 0; i < g_deniedPidCount; ++i) {
    if (g_deniedPids[i] != pid) continue;
    for (size_t j = i + 1; j < g_deniedPidCount; ++j) {
      g_deniedPids[j - 1] = g_deniedPids[j];
    }
    --g_deniedPidCount;
    return;
  }
}

static void clearDeniedPids() {
  memset(g_deniedPids, 0, sizeof(g_deniedPids));
  g_deniedPidCount = 0;
}

struct RequestedPid {
  uint32_t pid;
  uint16_t intervalMs;
  bool used;
};

static constexpr size_t MAX_REQUESTED_PIDS = 128;
static RequestedPid g_requestedPids[MAX_REQUESTED_PIDS] = {};
static bool g_raceChronoFilterActive = false;
static bool g_raceChronoAllowAll = false;
static uint16_t g_raceChronoAllowAllIntervalMs = 0;
static uint32_t g_filterCommandCount = 0;

static void clearRaceChronoFilter() {
  memset(g_requestedPids, 0, sizeof(g_requestedPids));
  g_raceChronoFilterActive = false;
  g_raceChronoAllowAll = false;
  g_raceChronoAllowAllIntervalMs = 0;
}

static RequestedPid* findRequestedPid(uint32_t pid) {
  for (size_t i = 0; i < MAX_REQUESTED_PIDS; ++i) {
    if (g_requestedPids[i].used && g_requestedPids[i].pid == pid) {
      return &g_requestedPids[i];
    }
  }
  return nullptr;
}

static bool requestPid(uint32_t pid, uint16_t intervalMs) {
  if (RequestedPid* existing = findRequestedPid(pid)) {
    existing->intervalMs = intervalMs;
    return true;
  }

  for (size_t i = 0; i < MAX_REQUESTED_PIDS; ++i) {
    if (g_requestedPids[i].used) continue;
    g_requestedPids[i].pid = pid;
    g_requestedPids[i].intervalMs = intervalMs;
    g_requestedPids[i].used = true;
    return true;
  }

  return false;
}

static size_t requestedPidCount() {
  size_t count = 0;
  for (size_t i = 0; i < MAX_REQUESTED_PIDS; ++i) {
    if (g_requestedPids[i].used) ++count;
  }
  return count;
}

static uint8_t profileDividerFor(uint32_t pid) {
  const auto* map = ACTIVE_PID_MAP;
  if (map != nullptr) {
    for (size_t i = 0; i < map->ruleCount; ++i) {
      if (map->rules[i].pid == pid) {
        const uint8_t divider = map->rules[i].divider;
        return divider == 0 ? 1 : divider;
      }
    }
    if (map->policyDividerForId != nullptr) {
      const uint8_t divider = map->policyDividerForId(pid);
      if (divider != 0) return divider;
    }
  }

  return DEFAULT_UPDATE_RATE_DIVIDER == 0 ? 1
                                          : DEFAULT_UPDATE_RATE_DIVIDER;
}

static bool profileAllows(uint32_t pid) {
  const auto* map = ACTIVE_PID_MAP;
  if (map == nullptr || map->isCanIdWhitelisted == nullptr) return false;
  return map->isCanIdWhitelisted(pid);
}

struct RouteDecision {
  bool allowed;
  uint16_t minimumIntervalMs;
};

static RouteDecision routeDecision(uint32_t pid) {
  RouteDecision result = {false, 40};

  if (isDenied(pid)) return result;

  // A serial ALLOW command is an explicit operator override.
  const uint8_t customDivider = customDividerFor(pid);
  if (customDivider != 0) {
    result.allowed = true;
    uint32_t customInterval = static_cast<uint32_t>(customDivider) * 10u;
    if (customInterval < 10u) customInterval = 10u;
    if (customInterval > 2000u) customInterval = 2000u;
    result.minimumIntervalMs = static_cast<uint16_t>(customInterval);
    return result;
  }

  // PROFILE OFF is the deliberate bench/sniff mode. It ignores RaceChrono's
  // requested PID set but still honors the deny list and the BLE global cap.
  if (!g_profileEnabled) {
    result.allowed = true;
    result.minimumIntervalMs = 10;
    return result;
  }

  // Once RaceChrono sends a filter command, follow the standard protocol.
  if (g_raceChronoFilterActive) {
    if (g_raceChronoAllowAll) {
      result.allowed = true;
      result.minimumIntervalMs =
          g_raceChronoAllowAllIntervalMs == 0
              ? 10
              : g_raceChronoAllowAllIntervalMs;
      return result;
    }

    if (RequestedPid* requested = findRequestedPid(pid)) {
      result.allowed = true;
      result.minimumIntervalMs =
          requested->intervalMs == 0 ? 10 : requested->intervalMs;
      return result;
    }

    return result;
  }

  // Before RaceChrono sends filters, use the compiled GR86 profile so the
  // device still streams useful data in generic BLE clients.
  if (!profileAllows(pid)) return result;

  result.allowed = true;
  if (pid == 0x710u) {
    result.minimumIntervalMs = g_oilPublishPeriodMs;
  } else if (pid == 0x777u) {
    result.minimumIntervalMs = 2000;
  } else {
    const uint8_t divider = profileDividerFor(pid);
    uint32_t interval = static_cast<uint32_t>(divider) * 10u;
    // Cap per-ID output at 25 Hz even for profile entries with divider 1.
    if (interval < 40u) interval = 40u;
    if (interval > 2000u) interval = 2000u;
    result.minimumIntervalMs = static_cast<uint16_t>(interval);
  }

  return result;
}

static void loadRuntimeConfig() {
  runtime_config::Snapshot stored;
  const bool loaded=runtime_config::load(stored);
  g_profileEnabled=stored.profileEnabled!=0;
  g_oilPublishPeriodMs=stored.oilPeriodMs;
  clearCustomDividers();
  for (uint16_t i=0;i<stored.count;++i)
    setCustomDivider(stored.items[i].pid,stored.items[i].divider);
  if (!loaded) g_log.println("Runtime configuration missing/incompatible/CRC invalid; using defaults.");
}

static bool saveRuntimeConfig() {
  runtime_config::Snapshot value;
  value.profileEnabled=g_profileEnabled?1:0;
  value.oilPeriodMs=g_oilPublishPeriodMs;
  value.count=g_customDividerCount;
  for (uint16_t i=0;i<value.count;++i) {
    value.items[i].pid=g_customDividers[i].pid;
    value.items[i].divider=g_customDividers[i].divider;
  }
  return runtime_config::save(value);
}

// -----------------------------------------------------------------------------
// BLE transport
// -----------------------------------------------------------------------------

static NimBLEServer* g_bleServer = nullptr;
static NimBLEAdvertising* g_bleAdvertising = nullptr;
static NimBLEService* g_bleService = nullptr;
static NimBLECharacteristic* g_canCharacteristic = nullptr;
static NimBLECharacteristic* g_filterCharacteristic = nullptr;
static NimBLECharacteristic* g_gpsCharacteristic = nullptr;
static NimBLECharacteristic* g_gpsTimeCharacteristic = nullptr;

static bool g_bleConnected = false;
static bool g_canSubscribed = false;
static bool g_gpsSubscribed = false;
static bool g_gpsTimeSubscribed = false;

static uint16_t g_bleMtu = 23;
static uint32_t g_bleConnectCount = 0;
static uint32_t g_bleDisconnectCount = 0;
static int g_lastBleDisconnectReason = 0;
static uint32_t g_lastBleConnectMs = 0;
static uint32_t g_lastBleDisconnectMs = 0;
static uint32_t g_advertisingStartCount = 0;
static uint32_t g_advertisingStartFailures = 0;
static uint32_t g_nextAdvertisingCheckMs = 0;

static uint32_t g_bleNotifySuccesses = 0;
static uint32_t g_bleNotifyFailures = 0;
static uint32_t g_bleNotifyRateDrops = 0;
static uint32_t g_bleNotifyUnsubscribedDrops = 0;
static timing::Backoff g_bleNotifyBackoff;
static uint32_t g_lastBleNotifyFailureMs = 0;

// Shared token bucket. GPS consumes ~11 notifications/s; the remaining budget
// is available for CAN. This prevents a noisy bus from starving NimBLE.
static constexpr uint16_t BLE_TOKEN_CAPACITY = 24;
static constexpr uint16_t BLE_TOKEN_RATE_PER_SECOND = 120;
static io::TokenBucket g_bleBudget(BLE_TOKEN_CAPACITY, BLE_TOKEN_RATE_PER_SECOND);

static bool isBleConnected() {
  return g_bleConnected && g_bleServer != nullptr &&
         g_bleServer->getConnectedCount() > 0;
}

static bool takeBleToken(uint32_t now, uint16_t reserve = 0) {
  if (g_bleBudget.take(now, reserve)) return true;
  ++g_bleNotifyRateDrops;
  return false;
}

static bool notifyCharacteristic(NimBLECharacteristic* characteristic,
                                 bool subscribed,
                                 const uint8_t* data,
                                 size_t length,
                                 uint32_t now) {
  if (!isBleConnected() || characteristic == nullptr) return false;

  if (!subscribed) {
    ++g_bleNotifyUnsubscribedDrops;
    return false;
  }

  if (g_bleNotifyBackoff.pending(now)) return false;
  const bool oilPacket = characteristic == g_canCharacteristic && length >= 4u &&
      data[0] == 0x10u && data[1] == 0x07u && data[2] == 0 && data[3] == 0;
  // Keep room for a coincident GPS solution, GPS time and oil update. This
  // reserves burst capacity; the total120 notifications/s cap is unchanged.
  const uint16_t reserve = characteristic == g_canCharacteristic && !oilPacket ? 3u : 0u;
  if (!takeBleToken(now, reserve)) return false;

  characteristic->setValue(data, length);
  if (characteristic->notify()) {
    ++g_bleNotifySuccesses;
    return true;
  }

  ++g_bleNotifyFailures;
  g_lastBleNotifyFailureMs = now;
  // A short quiet period is enough to let NimBLE drain. Do not restart BLE.
  g_bleNotifyBackoff.start(now, 100);
  return false;
}

static void startAdvertisingIfNeeded(uint32_t now, bool forceCheck = false) {
  if (g_bleAdvertising == nullptr || isBleConnected()) return;
  if (!forceCheck && !timeReached(now, g_nextAdvertisingCheckMs)) return;

  g_nextAdvertisingCheckMs = now + 3000;
  if (g_bleAdvertising->isAdvertising()) return;

  if (g_bleAdvertising->start()) {
    ++g_advertisingStartCount;
    g_log.println("BLE: advertising");
  } else {
    ++g_advertisingStartFailures;
    g_log.println("WARN: BLE advertising start rejected; retry scheduled");
  }
}

enum class BleEventType : uint8_t {
  Connect, Disconnect, Mtu, CanSubscription, GpsSubscription,
  TimeSubscription, NotifyFailure, Filter
};
struct BleEvent {
  BleEventType type;
  uint16_t value;
  int code;
  uint8_t length;
  uint8_t data[7];
};
static QueueHandle_t g_bleEvents = nullptr;
static std::atomic<uint32_t> g_bleEventDrops{0};
static std::atomic<bool> g_bleEventOverflow{false};

static void queueBleEvent(const BleEvent& event) {
  if (!g_bleEvents || xQueueSend(g_bleEvents, &event, 0) != pdTRUE) {
    ++g_bleEventDrops;
    g_bleEventOverflow.store(true);
  }
}

class ServerCallbacks final : public NimBLEServerCallbacks {
 public:
  void onConnect(NimBLEServer*, NimBLEConnInfo& info) override {
    queueBleEvent({BleEventType::Connect, info.getMTU(), 0, 0, {}});
  }
  void onDisconnect(NimBLEServer*, NimBLEConnInfo&, int reason) override {
    queueBleEvent({BleEventType::Disconnect, 0, reason, 0, {}});
  }
  void onMTUChange(uint16_t mtu, NimBLEConnInfo&) override {
    queueBleEvent({BleEventType::Mtu, mtu, 0, 0, {}});
  }
};
static ServerCallbacks g_serverCallbacks;

class SubscriptionCallbacks final : public NimBLECharacteristicCallbacks {
 public:
  explicit SubscriptionCallbacks(BleEventType type) : type_(type) {}
  void onSubscribe(NimBLECharacteristic*, NimBLEConnInfo&,
                   uint16_t value) override {
    queueBleEvent({type_, value, 0, 0, {}});
  }
  void onStatus(NimBLECharacteristic*, int code) override {
    if (code) queueBleEvent({BleEventType::NotifyFailure, 0, code, 0, {}});
  }
 private:
  BleEventType type_;
};
static SubscriptionCallbacks g_canSubscriptionCallbacks(BleEventType::CanSubscription);
static SubscriptionCallbacks g_gpsSubscriptionCallbacks(BleEventType::GpsSubscription);
static SubscriptionCallbacks g_gpsTimeSubscriptionCallbacks(BleEventType::TimeSubscription);
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
void loop() {
  cca::loopImpl();
}

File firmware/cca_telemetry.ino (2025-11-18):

// ===== CCA Telemetry: ESP32-S3 + TWAI + RaceChrono DIY BLE (CAN + GPS) =====
// - Robust BLE reconnect (no NimBLE deinit on S3; stop/start advertiser only)
// - TWAI CAN RX burst buffering + per-PID throttle
// - Profile allow-list (car mode) vs sniff-all (bench mode)
// - Oil pressure analog on GPIO1 -> CAN 0x710 (0.1 psi/bit, big-endian)
// - Flash config (Preferences): V0_ADC, V1_ADC, PROFILE, custom dividers
// - RaceChrono DIY BLE service 0x1FF8 with:
//      0x0001 CAN main (READ+NOTIFY)
//      0x0002 CAN filter (WRITE)
//      0x0003 GPS main (READ+NOTIFY)
//      0x0004 GPS time (READ+NOTIFY)
// - Serial CLI (CR, LF, CRLF, or none)
//
// Libs:
//   ESP32-TWAI-CAN
//   NimBLE-Arduino
//   Preferences
//
// Board: ESP32S3 Dev Module

#include <ESP32-TWAI-CAN.hpp>
#include <NimBLEDevice.h>
#include <NimBLEUtils.h>
#if defined(CONFIG_NIMBLE_CPP_IDF)
#include "host/ble_gap.h"
#include "host/ble_hs.h"
#include "host/ble_att.h"
#else
#include "nimble/nimble/host/include/host/ble_gap.h"
#include "nimble/nimble/host/include/host/ble_hs.h"
#include "nimble/nimble/host/include/host/ble_att.h"
#endif
#include "nimble/porting/nimble/include/os/os_mempool.h"
#include <Preferences.h>
#include <esp_gatt_defs.h>
#include <esp_random.h>
#include <cstdio>
#include <cstring>
#include <cstdint>
#include <ctype.h>
#include <driver/twai.h>
#include <esp_err.h>
#include <freertos/FreeRTOS.h>
#include <math.h>
#include <esp_system.h>
#include <esp_task_wdt.h>
#include <esp_heap_caps.h>
#if defined(__has_include)
#if __has_include(<esp_idf_version.h>)
#include <esp_idf_version.h>
#endif
#endif
#include "config.h"   // must define DEFAULT_UPDATE_RATE_DIVIDER and DEVICE_NAME
#include "src/gps_nmea.h"
#include "src/sched.hpp"
#include "src/nvs_cfg.h"
#include "src/led_status.h"

#ifndef PASSKEY_U32
#define PASSKEY_U32 123456
#endif

#ifndef DEV_TRUST_FIL
#define DEV_TRUST_FIL 0
#endif

// ---------- Version ----------
#ifndef FW_VERSION
#define FW_VERSION "0.6.1"
#endif
#ifndef FW_GITHASH
#define FW_GITHASH "esp32s3"
#endif
static const char FW_VERSION_STRING[] = FW_VERSION " (" FW_GITHASH ")";

// ===== Pins (S3 <-> SN65HVD230) =====
#define CAN_TX 5
#define CAN_RX 4

// ===== GPS pins (UART1) =====
#define GPS_RX_GPIO 18   // GPS TX -> ESP RX
#define GPS_TX_GPIO 17   // GPS RX <- ESP TX (PMTK)

// ===== GPS PMTK sequences =====
static const char *PMTK_SET_NMEA_OUTPUT_RMCGGA = "$PMTK314,0,1,0,1,0,0,0,0,0,0,0,0,0,0,0,0,0,0,0*28\r\n";
static const char *PMTK_SET_NMEA_UPDATE_10HZ   = "$PMTK220,100*2F\r\n";
static const char *PMTK_SET_BAUD_115200        = "$PMTK251,115200*1F\r\n";

// ===== BLE UUIDs (RaceChrono DIY) =====
static const char* RC_SERVICE_UUID   = "00001ff8-0000-1000-8000-00805f9b34fb";
static const char* RC_CHAR_CAN_UUID  = "00000001-0000-1000-8000-00805f9b34fb"; // READ+NOTIFY
static const char* RC_CHAR_FIL_UUID  = "00000002-0000-1000-8000-00805f9b34fb"; // WRITE
static const char* RC_CHAR_GPS_UUID  = "00000003-0000-1000-8000-00805f9b34fb"; // READ+NOTIFY
static const char* RC_CHAR_GTM_UUID  = "00000004-0000-1000-8000-00805f9b34fb"; // READ+NOTIFY
static const char* RC_CHAR_DIAG_UUID = "00000005-0000-1000-8000-00805f9b34fb"; // READ+NOTIFY

// ====== (Fix) Governor snapshot: define early so Arduino doesn't mangle prototypes ======
struct GovernorSnapshot { uint32_t pid; uint8_t governor; };
struct NimblePoolWatermark { uint16_t minFreeBlocks; uint16_t blockSize; };
static constexpr size_t   BLE_GOVERNOR_SNAPSHOT_MAX = 128;
static size_t capture_governor_snapshot(GovernorSnapshot *out);
static bool   restore_governor_snapshot(const GovernorSnapshot *snapshots, size_t count);

// ====== Forward declarations to satisfy Arduino's autogenerated prototypes ======
struct PidExtra;
static void resetSkippedUpdatesCounters();
static int64_t gpsComputeMonotonicUs(uint32_t micros_now, int64_t correction_us);
static void gpsHandlePpsDiscipline(uint32_t now_ms);
static void IRAM_ATTR gpsPpsIsr();
static void gpsMarkSentenceStale();
static void bleNotifyBackoffReset();
static void bleNotifyBackoffService(uint32_t now);
static void bleApplyNegotiatedMtu(uint16_t mtu);
static void bleResetNotifySizing();
static void bleHandleNotifyStatus(const char *label, int code);

// ===== Global state =====
static bool     isCanBusReaderActive = false;
static uint32_t lastCanMessageReceivedMs = 0;
static uint32_t loop_iteration = 0;
static uint16_t num_can_bus_timeouts = 0;
static uint8_t  consecutiveCanRxTimeouts = 0;
static uint32_t lastCanRxTimeoutMs = 0;

static bool     have_seen_any_can = false;
static uint32_t lastHbMs = 0;
static uint16_t hbCounter = 0;
static const uint32_t HB_PID = 0x7AA; // BLE heartbeat

static constexpr uint32_t MS_PER_SECOND = 1000;
static constexpr uint32_t MS_PER_MINUTE = 60 * MS_PER_SECOND;
static constexpr uint32_t MS_PER_HOUR   = 60 * MS_PER_MINUTE;
static constexpr uint32_t MS_PER_DAY    = 24 * MS_PER_HOUR;

static uint32_t rxCount = 0;
static uint32_t lastRxPrintMs = 0;
static constexpr uint32_t CAN_RX_PRINT_INTERVAL_MS = 200;

static constexpr uint16_t kBaseCanNotifiesPerLoop = 20;
static constexpr uint16_t BLE_BASE_NOTIFY_PAYLOAD = 20;
static constexpr uint32_t BLE_NOTIFY_BASE_BUDGET_BYTES =
    static_cast<uint32_t>(kBaseCanNotifiesPerLoop) * BLE_BASE_NOTIFY_PAYLOAD;
static constexpr uint32_t NOTIFY_CAP_LOG_INTERVAL_MS = 2000;
static uint16_t canNotifiesThisLoop = 0;
static bool notifyCapHitCurrentLoop = false;
static uint32_t notifyCapHitsSinceLastLog = 0;
static uint32_t notifyCapLastLogMs = 0;
static uint32_t notifies_suppressed_total = 0;
static uint16_t g_bleNotifyBurstBudgetPerLoop = kBaseCanNotifiesPerLoop;

static uint16_t g_bleNegotiatedMtu = BLE_ATT_MTU_DFLT;
static uint16_t g_bleNotifyMaxValueLength = (BLE_ATT_MTU_DFLT > 3) ? (BLE_ATT_MTU_DFLT - 3) : 0;
static uint32_t bleNotifyFailuresTotal = 0;
static uint32_t bleNotifyStatusErrors = 0;
static uint32_t bleNotifyCongestionEvents = 0;
static uint32_t bleNotifyClampEvents = 0;
static uint32_t bleNotifyFailureLastLogMs = 0;
static uint32_t bleNotifyClampLastLogMs = 0;
static uint32_t bleNotifyBackoffEvents = 0;
static uint32_t bleNotifyBackoffLastLogMs = 0;
static uint32_t bleNotifyBackoffUntilMs = 0;
static uint8_t  bleNotifyBackoffLevel = 0;
static bool     bleNotifyBackoffActive = false;
static int      bleNotifyLastStatusCode = 0;
static uint32_t bleNotifyLastStatusMs = 0;
static char     bleNotifyBackoffLastReason[48] = "none";
static constexpr uint32_t BLE_NOTIFY_FAILURE_LOG_INTERVAL_MS = 2000;
static constexpr uint32_t BLE_NOTIFY_CLAMP_LOG_INTERVAL_MS   = 5000;
static constexpr uint32_t BLE_NOTIFY_BACKOFF_LOG_INTERVAL_MS = 5000;
static constexpr uint8_t  BLE_NOTIFY_BACKOFF_MAX_LEVEL       = 5;
static constexpr uint32_t BLE_NOTIFY_BACKOFF_BASE_MS         = 20;
static constexpr uint32_t BLE_NOTIFY_BACKOFF_MAX_MS          = 640;
static GovernorSnapshot bleNotifyBackoffSnapshot[BLE_GOVERNOR_SNAPSHOT_MAX];
static size_t bleNotifyBackoffSnapshotCount = 0;
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

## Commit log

2025-10-18 Implement per-PID allow-all throttle
2025-10-19 Remove allow-all throttle gate
2025-11-03 Forward declare PidExtra for Arduino prototypes
2025-11-03 Refactor CAN profile into selectable pid map
2025-11-03 Fix PID map include guard
2025-11-03 Tighten PID map extra creation
2025-11-03 Qualify PID map type references
2025-11-03 Handle RaceChrono filter commands without dropping CAN PIDs
2025-11-04 Make GPS NMEA parser header-only for Arduino
2025-11-04 Move GPS NMEA parser into Arduino library
2025-11-04 Place GPS parser sources under Arduino src layout
2025-11-04 Handle oil ADC glitches and persist calibration blob
2025-11-11 Force dual TWAI filters for profile builds
2025-11-11 Add status LED manager and integrate runtime signals
2025-11-11 Add oil status LED and improve LED servicing
2025-11-11 Improve LED servicing and defaults
2025-11-11 Improve LED refresh for BLE and GPS
2025-11-11 Adjust LED patterns and reset behavior
    [led_status.h]
2025-11-11 Fix LED polarity defaults and validate GPIOs
    [led_status.cpp, led_status.h]
2025-11-11 Make status LEDs responsive without BLE connection
2026-09-10 Rev B I23: return rework verified; foil clearance reopened (#45)
    * Prepare RVB-22 corrective engineering plan and verified native-evidence runner
    * Add RVB-22 I06 corrective candidate and source-bound review evidence
    Forward the complete CAD and firmware candidate, final mechanical source, harness and assembly contracts, native runner, and final review records. Preserve main firmware and retain native, thermal, conditional-model, supplier and physical acceptance gates.
    * Run the I06 candidate in a pinned native engineering review job
    * Keep CAD evidence independent of compiler downloads and allow bounded transfer time
    * Use the forwarded native runner entry point and verify all job sour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
    [CAN.kicad_sch, ENVELOPE_CDTop_PA1616D_20Pad_v06.step, ENVELOPE_C_0603_1608Metric_RVB22_C205.step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]
2026-09-10 I24: shorten oil routes to restore CAN RX reference paths
    [GR86_CCA_RevB.kicad_pcb]
2026-09-10 I24: preserve alternate CAN TX reference through coordinated LED clearance
    [GR86_CCA_RevB.kicad_pcb]
2026-09-10 Preserve I24 mechanical rework and independent native evidence
    [ASSEMBLY_C06_W03_T04.scad, GR86_RVB_CARRIER_C06.scad, THERMAL_CONTACT_T04.scad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]
2026-09-10 I24: disposition high-temperature GPS pigtail
2026-09-10 I24: adjudicate LED optical visibility criterion
2026-09-10 Freeze I25 thermal CAD redline and acceptance gates
2026-09-11 Resolve native feedback trial findings and add ground-only thermal access candidate
2026-09-11 Stage hash-verified Convergence01 source import authorized by owner
2026-09-11 Publish verified Convergence01 source and evidence without adopting CAD trials
    [CURRENT_FITTED_MPN_HANDLING.csv]
2026-09-11 Bind native verification to full board content and run exports after complete build
2026-09-11 Add C04 release power-profile thermal rationale
2026-09-11 Couple release thermal budget to actual power flow
2026-09-11 Advance current execution plan to I26 prehardware closure
2026-09-12 Add I26 source-bound LED, return-path and thermal reconciliation evidence pipeline
    [HISTORICAL_54.csv]
